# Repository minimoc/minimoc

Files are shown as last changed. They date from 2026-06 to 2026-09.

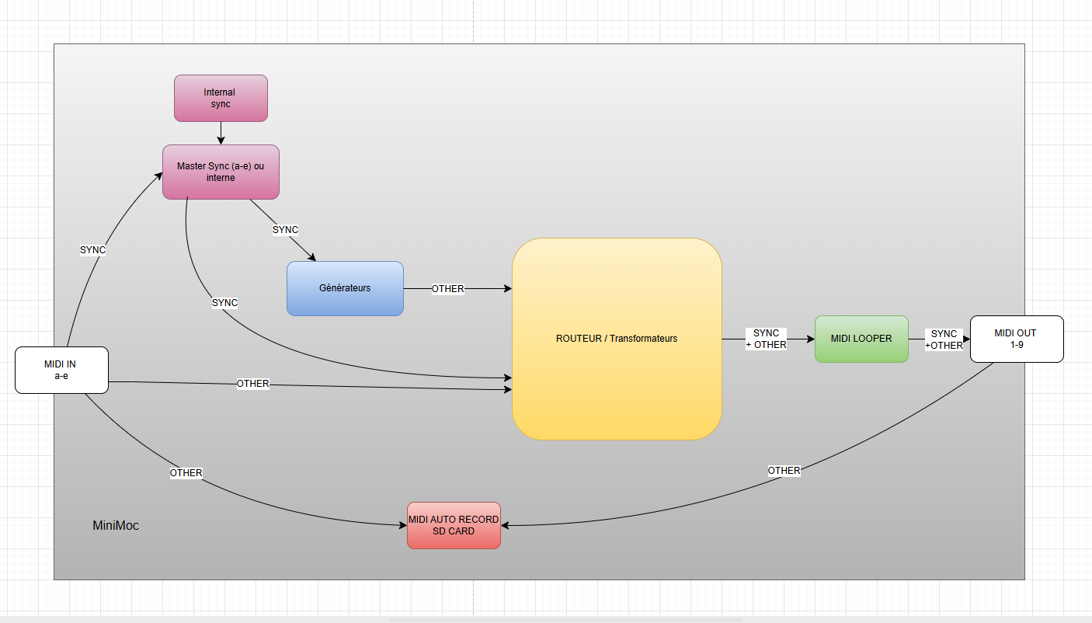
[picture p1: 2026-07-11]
docs/Conception.png

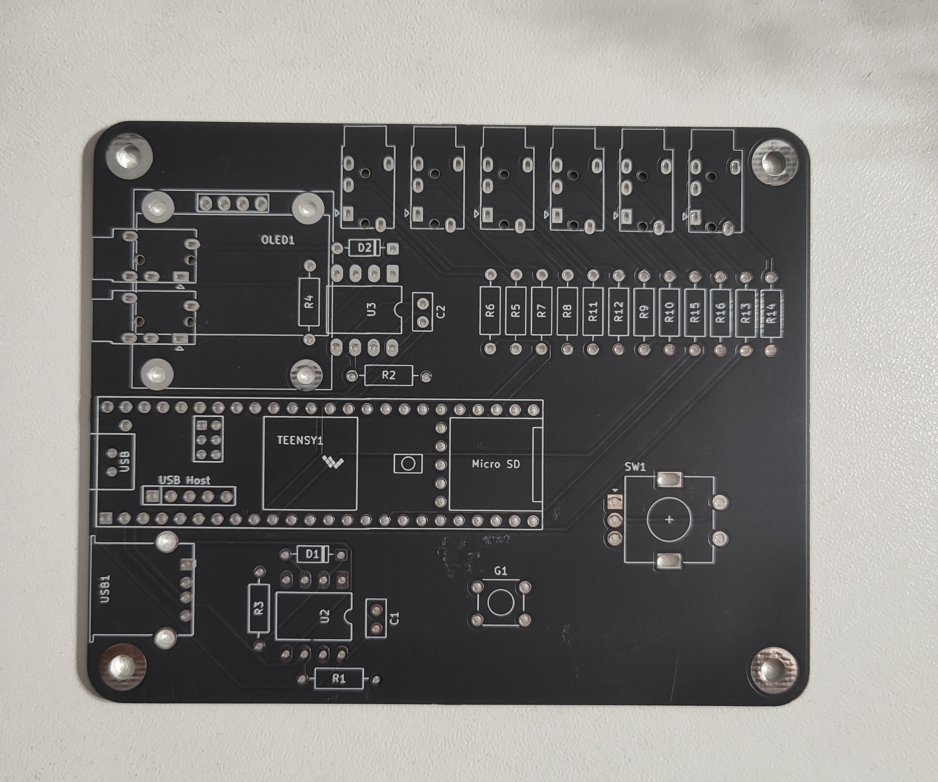
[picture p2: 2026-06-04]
hardware/dessous.jpg

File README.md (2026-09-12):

# miniMoc

**Routeur MIDI hybride DAWless, fait main.**

🇬🇧 In English — miniMoc is a handmade, open-hardware DAWless MIDI router built around a Teensy 4.1: 5 MIDI inputs, 9 outputs, TRS TYPE A + USB Host, a 128x64 OLED screen and a rotary encoder. Route MIDI between your synths and machines with no computer. Its signature feature, Smart Mirror: plug in a PC and the miniMoc's physical ports reappear as identical virtual ports in your DAW — no setup, no drivers. Unplug and you're back to standalone mode. The project is at v0.5.2 (routing, Smart Mirror, MIDI clock sync, Flux transforms — transpose/harmonize/chord progressions —, MIDI generators — LFO/Euclidean/drum patterns — and SD presets are solid; continuous MIDI auto-recording to SD is postponed to a future version). Documentation is currently in French — English translation contributions are very welcome (see CONTRIBUTING.md). Licence: source-available, non-commercial (PolyForm NC for firmware, CC BY-NC for hardware) — personal use is free, commercial use requires permission.

Le miniMoc est un boîtier portable qui route le MIDI entre vos synthés, séquenceurs
et machines — sans ordinateur. cinq entrées (2 TRS Type A + 3 USB), neuf sorties (6 TRS TYPE A + 3 USB), USB Host, un écran OLED 128x64 pixels
et un encodeur pour tout piloter à la main.

> **Smart Mirror** — branchez un PC/MAC/LINUX/SMARTPHONE et les ports physiques du miniMoc réapparaissent
> à l'identique en ports virtuels dans votre DAW. Aucune configuration, aucun pilote
> à installer. Vous débranchez, vous repartez en mode autonome.

---

## Démonstrations vidéo

- **Le projet et l'appel aux compagnons** : https://www.youtube.com/watch?v=sc03914Uq1w
- **Présentation du hardware** (ce que vous recevez, comment c'est fait) : https://youtu.be/FKErdNdDdWI
- **La navigation dans les menus** : https://youtu.be/ahOwxcXlfOY
- **Le smartmirror expliqué** : https://youtu.be/d6lrl4uF-Bw

---

## État du projet — v0.5.2

Le miniMoc en est à sa version 0.5.2, assemblée à la main.

**Ce qui fonctionne et est éprouvé :**
- Routage MIDI complet (mode BASIC par matrice, mode FLUX avancé avec filtrage et
  remapping de canal)
- Smart Mirror (miroir des ports physiques vers le DAW)
- Synchronisation MIDI Clock (horloge interne réglable ou source externe) + écran TRANSPORT
- Transformateurs de Flux : transposition, harmonisation, réharmonisation sur une
  progression d'accords
- Générateurs MIDI internes : LFO, séquenceur euclidien, motifs de batterie pré-enregistrés
- Sauvegarde / rappel des configurations sur carte SD (32 presets utilisateur + 8 d'usine)
- Interface écran OLED + encodeur
- Mise à jour du firmware par OTA depuis l'éditeur web

**Reporté après la V1 :**
- Auto-enregistrement MIDI continu sur carte SD (capture automatique des jams). Le moteur
  existe dans le code mais reste désactivé par défaut : pas de commande pour démarrer/
  arrêter un enregistrement à la volée, pas de fermeture propre du fichier en cours
  d'usage. Sera retravaillé pour une version ultérieure — vos retours d'usage sur ce
  point précis restent les bienvenus.

---

## Ce que c'est (et ce que ce n'est pas)

Le miniMoc est un projet dans un esprit maker. Ce n'est pas un
produit fini sous coque fermée : il se présente sous forme de carte (PCB) avec son
Teensy 4.1, et un *bezel* maintient l'écran en position. Des premiers fichiers 3D de
boîtier et de socle existent (dossiers [`boitier/`](boitier/) et [`socle/`](socle/))
mais restent perfectibles — c'est un terrain de contribution ouvert pour qui aime la CAO.

---

## Matériel

- **Microcontrôleur** : Teensy 4.1 (PJRC)
- **Affichage** : écran OLED monochrome (I²C)
- **Entrées / sorties** : 2+3 IN MIDI, 6+3 OUT MIDI
- **Contrôle** : encodeur rotatif + bouton

Les fichiers de conception (schémas, PCB, BOM) se trouvent dans le dossier
[`hardware/`](hardware/). Le *bezel* à imprimer est dans [`bezel/`](bezel/).

---

## Firmware

Le code du firmware est dans [`firmware/`](firmware/). Il se compile avec
**l'IDE Arduino + Teensyduino**, pour Teensy 4.1.

### Dépendances

Ces bibliothèques **ne sont pas incluses dans ce dépôt**. Installez-les via le
gestionnaire de bibliothèques de l'IDE Arduino (ou elles sont fournies avec
Teensyduino) :

- U8g2
- Arduino MIDI Library (version 5+)
- USBHost_t36 *(fournie avec Teensyduino)*
- MTP_Teensy
- SdFat
- Encoder *(fournie avec Teensyduino)*
- Bounce2

> ⚠️ N'essayez pas de récupérer ces bibliothèques depuis ce dépôt : elles n'y sont
> volontairement pas. Passez par le gestionnaire de bibliothèques Arduino.

Les licences de ces dépendances sont détaillées dans
[`THIRD_PARTY_LICENSES.md`](THIRD_PARTY_LICENSES.md).

---

## Licence

**Sources ouvertes — usage personnel libre, commercialisation sur accord.**

- **Firmware** (dossier `firmware/`) : licence **PolyForm Noncommercial 1.0.0**.
  Vous pouvez l'utiliser, l'étudier, le modifier et le partager **pour un usage
  non commercial**.
- **Matériel** (dossiers `hardware/` et `bezel/`) : licence
  **Creative Commons Attribution-NonCommercial 4.0 (CC BY-NC 4.0)**.

Toute **utilisation commerciale** (vente, intégration dans un produit vendu, etc.)
nécessite mon accord préalable. Si vous souhaitez commercialiser quelque chose à
partir du miniMoc, contactez-moi : c'est tout à fait possible de s'entendre.

Voir les fichiers [`LICENSE`](LICENSE) (firmware) et
[`hardware/LICENSE`](hardware/LICENSE) (matériel).

---

## Contribuer

Le miniMoc avance avec celles et ceux qui l'utilisent. Retours d'usage,
corrections, idées de fonctionnalités, conception d'un boîtier complet : tout est
bienvenu. Voir [`CONTRIBUTING.md`](CONTRIBUTING.md).

---

*miniMoc — conçu et assemblé à la main par François Jacob.*

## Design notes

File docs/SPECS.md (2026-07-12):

# miniMoc — Spécifications Fonctionnelles

## 1. Vue d'ensemble

Le **miniMoc** est un routeur MIDI hardware intelligent combinant :
- Un firmware embarqué (C++/Arduino) sur **Teensy 4.1**
- Une interface homme-machine sur **OLED 128×64 (SSD1306 I2C)**
- Un **encodeur rotatif** (navigation + sélection) et un bouton BACK

---

## 2. Ports MIDI

### Entrées (5 ports)
| Port | Type | Description |
|---|---|---|
| A | DIN MIDI (Serial2) | Entrée physique TRS TYPE A |
| B | DIN MIDI (Serial1) | Entrée physique TRS TYPE A |
| C | USB Host | 1er device USB branché |
| D | USB Host | 2e device USB branché |
| E | USB Host | 3e device USB branché |

### Sorties (9 ports)
| Port | Type | Description |
|---|---|---|
| 1–6 | DIN MIDI (Serial3/6/7/8) | Sorties physiques TRS |
| 7–9 | USB Host | Sorties vers devices USB |

### USB Device (vers DAW)
- Port 0 : SysEx/éditeur
- Ports 1–2 : miroir brut des entrées A/B
- Ports 3–12 : miroir routé des sorties 1–9 + miroir brut des entrées C/D/E
- **Smart Mirror** : tout signal routé est simultanément mirroré vers le DAW pour enregistrement

### USB Host (6 slots physiques)
- 6 objets `MIDIDevice_BigBuffer` (MIDIUSB1–6), assignation FIFO
- 3 instances `USBHub` pour robustesse hub multi-TT / reconnexion
- Pool : 12 pipes + 48 transfers extra

---

## 3. Routage MIDI — Architecture Hybride

Le routage combine deux couches cumulatives calculées dans `route_matrix[5][16][9]` :

### 3.1 Couche BASIC (matrice 5×9)
- Grille booléenne Port d'entrée → Port de sortie
- Quand un nœud est actif : **passthrough canal** (ch1→ch1, ch2→ch2, etc.)
- Stockée dans `basic_matrix[5]` (bitmask uint16_t par port d'entrée)
- Navigation : encodeur (1 case/tick), VALID = toggle

### 3.2 Couche FLUX (règles avancées cumulatives)
Chaque **flux** définit :
- **Entrées** : liste de (port, canal_mask) — ex. {A, ch1} + {B, ch2}
- **Sorties** : liste de (port, canal_mask) — ex. {sortie1, ch5} + {sortie4, ch2}
- Si canal_mask = 0 → tous les canaux (entrée) ou passthrough (sortie)
- Multi-sélection indépendante pour entrées ET sorties
- MAX 16 flux simultanés

**Cumul** : route_matrix = BASIC + tous FLUX actifs. Les bits sont OR-és : un signal peut arriver sur plusieurs destinations via BASIC et FLUX simultanément.

### 3.3 Filtrage canal 10
Supprimé — le canal 10 est traité comme n'importe quel autre canal.

---

## 4. Synchronisation MIDI (SYNC)

Sélection d'une **unique source maître** (`sync_master`, `uint8_t`) pour Clock/Start/Stop/Continue/SystemReset, diffusée via `_sync_forward()` (`_midi.h`) vers **toutes les sorties** (1–6 physiques, 7–9 USB Host) et leur miroir PC (smartmirror, `SYNC_MIRROR_CABLES[]`).

### 4.1 Encodage `sync_master`

Chaque lettre A-E a deux sources physiques distinctes qui déclenchaient toutes les deux le même maître avant cette distinction : l'entrée TRS/USB Host physique d'un côté, le câble USB miroir venant du PC (smartmirror) de l'autre. `SYNC_LABELS[]` (`logic.h`) :

| Valeur | Source | Valeur | Source |
|---|---|---|---|
| 0 | A (TRS) | 5 | A (USB/PC) |
| 1 | B (TRS) | 6 | B (USB/PC) |
| 2 | C (USB Host) | 7 | C (USB/PC) |
| 3 | D (USB Host) | 8 | D (USB/PC) |
| 4 | E (USB Host) | 9 | E (USB/PC) |
| 10 | MINIMOC (horloge interne) | 0xFF (RAM) / 0x7F (EEPROM, SysEx) | OFF |

- Persisté en EEPROM (adresse 34, 1 octet, valeurs 0-10 ou 0x7F=OFF)
- Les USB Host inputs (C/D/E) supportent la réception d'horloge via callbacks `setHandleRealTimeSystem` (`_usb_rt()`, valeurs 2-4 uniquement — inchangé par la distinction TRS/USB ci-dessus)
- Rétrocompatibilité : les valeurs 0-4 et 0xFF gardent exactement le sens qu'elles avaient avant l'introduction des variantes USB/PC (5-9) et MINIMOC (10)

### 4.2 Horloge interne (MINIMOC)

Quand `sync_master == SYNC_MASTER_INTERNAL` (10), le miniMoc génère lui-même le Clock via `internal_clock_isr()` (`_midi.h`), déclenché par un `IntervalTimer` matériel — indépendant de `loop()` et de ses appels bloquants (`u8g2.sendBuffer()` ~8ms, `sd_tick()`/`MTP.loop()`, `myusb.Task()`).

- **Sorties DIN (MIDI1-6)** : envoyées directement depuis l'ISR. Sûr par construction : si le buffer TX UART est plein, l'IRQ UART (priorité 64) préempte l'`IntervalTimer` (priorité par défaut 128, donc moins prioritaire) pour le drainer — mécanisme prévu par le core Teensy pour ce cas précis (`HardwareSerial.cpp::write9bit()`).
- **Sorties USB Host (7-9) et miroir PC** : jamais appelées depuis l'ISR — `MIDIDevice_BigBuffer::sendRealTime()` (USBHost_t36) et `usbMIDI` ne sont pas garantis réentrants (`write_packed()` peut boucler un temps non borné en cas de buffers pleins). L'ISR pose un flag (`internal_clock_usb_pending`), vidé en best-effort par `internal_clock_flush_usb()` appelée sans condition dans `loop()`.
- Tempo : `internal_clock_bpm` (`uint16_t`, 20-300, défaut 100), persisté en EEPROM (37-38). `internal_clock_apply()` démarre/arrête/reconfigure le timer (`period_us = 60000000UL / (24UL * internal_clock_bpm)`) — appelée après toute affectation de `sync_master` ou de `internal_clock_bpm`.
- Pas de Start/Stop/Continue automatique généré par le Clock lui-même — géré séparément par le menu TRANSPORT (4.3).

### 4.3 Transport (Play/Pause/Stop/MMC)

`transport_submenu.h` expose des actions réutilisées à la fois par les gestes physiques (encodeur + BACK) et par la commande SysEx `0x11` (weblink) :

| Fonction | Effet |
|---|---|
| `transport_do_play_pause()` | Bascule Play/Pause. Play : `Start` (premier départ) ou `Continue` (reprise après pause) selon `transport_resumable`. Pause : `Stop` temps réel, `transport_resumable=true` |
| `transport_do_stop()` | `Stop` temps réel + MMC Stop, `transport_resumable=false` (le Play suivant redémarre avec `Start`, pas `Continue`) |
| `transport_do_record()` | MMC Record Strobe |
| `transport_do_fastforward()` | MMC Fast Forward |
| `transport_do_rewind()` | MMC Rewind |

État partagé : `transport_playing` (bool), `transport_resumable` (bool) — lus par `transport_draw()` pour l'affichage PLAY/PAUSE/STOP.

**MMC (MIDI Machine Control)** : SysEx `F0 7F 7F 06 <commande> F7` (device-id 0x7F = broadcast), diffusé vers les mêmes 9 sorties + miroir PC via `send_mmc()` (`_midi.h`). Commandes utilisées : Stop 0x01, Fast Forward 0x04, Rewind 0x05, Record Strobe 0x06. Protocole indépendant du Start/Continue/Stop temps réel (`_sync_forward()`).

**Gestes physiques** (écran TRANSPORT) :
- Encodeur (BACK relâché) : ±1 BPM, ±5 si deux crans s'enchaînent en moins de `TRANSPORT_BPM_ACCEL_MS` (180ms)
- Clic encodeur (BACK relâché) : `transport_do_play_pause()`
- Clic simple BACK : `transport_do_stop()` si en pause (reste sur l'écran), sinon retour au menu précédent
- BACK tenu + clic encodeur / tourner à droite / tourner à gauche : `transport_do_record()` / `transport_do_fastforward()` / `transport_do_rewind()`
- Le long-appui global BACK→écran logo (`firmware.ino::loop()`) est désactivé tant que `ui_screen == UI_TRANSPORT`, pour ne pas interrompre les gestes chordés ci-dessus
- `btn_back` distingue un **front** (`backButton.fell()`, un seul événement par appui — utilisé par tous les autres écrans pour "remonter d'un niveau") d'un **niveau continu** (`btn_back_held`, utilisé uniquement par TRANSPORT pour les gestes chordés)

### 4.4 Protocole SysEx éditeur (PCEditor.h)

Toutes les commandes `F0 7D <cmd> ... F7` (`MANUFACTURER_ID = 0x7D`) :

| Cmd | Sens | Description |
|-----|---|---|
| 0x01 | PC→device | Update routing direct (legacy) |
| 0x02 | PC→device | Request full dump (`sendFullDumpToPC()`) |
| 0x03 | device→PC | Version firmware (ASCII, ex. "v0.3.0") — envoyée en tête du dump complet et à chaque QUICK POLL |
| 0x04 | bidirectionnel | BPM horloge interne (14 bits, 2×7bit) |
| 0x05 / 0x06 | PC→device | Charger / sauver preset N |
| 0x07 | device→PC | Preset actif |
| 0x08 | bidirectionnel | Ping / Pong (heartbeat) |
| 0x09 | bidirectionnel | Cellule matrice BASIC |
| 0x0A / 0x0B | bidirectionnel | Flux (données / count) |
| 0x0C | bidirectionnel | SYNC master |
| 0x0D | bidirectionnel | HOST CONFIG |
| 0x0E | PC→device | Quick poll (déclenche l'envoi groupé de 0x03/0x07/0x0C/0x04/0x09/0x0B/0x0A/0x0D/0x0F) |
| 0x0F | device→PC | Nom device USB (par slot) |
| 0x10 | PC→device | Reboot HalfKay bootloader |
| 0x11 | PC→device | Action transport — 0=Play/Pause 1=Stop 2=Record 3=Fast Forward 4=Rewind (voir 4.3) |

---

## 5. USB Host — Configuration (HOST CONFIG)

### 5.1 Assignation port logique ↔ slot physique
Table `port_slot[6]` : pour chaque port logique (IN C/D/E + OUT 7/8/9), quel slot physique (MIDIUSB1-6) le gère.

Défaut : slot 0 → C+7, slot 1 → D+8, slot 2 → E+9.

### 5.2 Mode AUTO
- Assignation chronologique FIFO (premier device branché = premier slot)
- Pas de persistance des assignations
- Toute reconnexion repart dans l'ordre d'arrivée

### 5.3 Mode MANUEL
- L'utilisateur assigne manuellement chaque port logique à un slot physique
- Capture des empreintes **VID:PID** de chaque port au moment de l'activation
- À la reconnexion : scan par VID:PID → le device retrouve son port logique quel que soit l'ordre de branchement
- Persisté en EEPROM (adresse 2, format v3)

---

## 6. Presets

- Stockage sur **carte SD** (SDIO), répertoire `/PRESETS/PRSTnn.DAT`
- Maximum **32 presets**
- Format v3 : `route_matrix` + `basic_matrix` + flux_list (FLUX)
- Migration automatique des presets v1 (legacy route_matrix → basic_matrix déduite)
- Sauvegarde/chargement via menu PRESET
- Preset actif mémorisé en EEPROM (adresse 0)

---

## 7. Interface Homme-Machine

### 7.1 Contrôles physiques
- **Encodeur rotatif** : navigation dans les listes/grilles
- **Bouton VALID** (encodeur click) : sélectionner, valider, entrer dans un menu
- **Bouton BACK** (bouton séparé) : retour arrière dans la navigation
- **Appui long BACK** (1s) : basculer vers/depuis l'écran logo (mode live)
- **Depuis le logo** : tout clic ou rotation → retour au carousel

### 7.2 Carousel principal (6 items)
```
PRESET → SYNC → ROUTAGE → MONITOR → SYSTEM → TRANSPORT
```
Ordre d'enregistrement : `firmware.ino::setup()` (`carousel_register()`).

### 7.3 Menu PRESET
- Affichage du numéro de preset courant (indicateur SD si sauvegardé)
- Actions : changer de numéro / Sauvegarder / Charger

### 7.4 Menu SYNC
- Liste défilante (`sync_submenu.h`) : 11 sources + OFF (voir §4.1), curseur en encart inversé, flèches `^`/`v` quand du contenu est masqué
- La source active est marquée d'un `*`, indépendamment de la position du curseur
- VALID = sélectionner + sauvegarder EEPROM + `internal_clock_apply()` (démarre/arrête l'horloge interne selon le nouveau choix)

### 7.5 Menu ROUTAGE
```
ROUTAGE
├── MATRICE  → grille 5×9 interactive (BASIC)
└── FLUX     → liste des flux avancés
     ├── [F1 - A:1 → 1:5]  (clic = Modifier / Supprimer)
     ├── [F2 - B → 1 4]
     └── [+] Nouveau flux
           Step 1 : FLUX → ENTREES (ports A-E, long press = canaux)
           Step 2 : FLUX → SORTIES (ports 1-9, long press = canaux)
           Picker canaux : grille 4×4 (ch1-16), sélection multi indépendante
```

### 7.6 Menu MONITOR
- VU-mètre temps réel : 5 entrées (A/B/C/D/E) + 9 sorties (1-9)
- Actualisation permanente (animation fondu 500ms)
- Les barres d'entrée s'allument dès réception, indépendamment du routage
- Page 2 (BPM) : tempo du maître SYNC en grand ; fréquence de rafraîchissement pilotée par le réglage **BPM REFRESH** (§7.7) ; un clic sur l'encodeur force toujours une actualisation immédiate quel que soit ce réglage ; la LED embarquée (`LED_BUILTIN`) clignote à chaque temps (`bpm_push_clock()`, toutes les 24 ticks), indépendamment de l'affichage

### 7.7 Menu SYSTEM
```
SYSTEM
├── INFO         → stats SD + liste devices USB physiques (D1..D6)
├── HOST CONFIG  → assignation ports logiques / Mode AUTO-MANUEL / LOCK VID:PID
├── USB LINK     → polling USB 2,5s pour forcer l'énumération (sans reboot)
├── USB RESET    → reboot Cortex-M7 complet (équivalent power-cycle)
├── CONTRASTE    → luminosité OLED (16–255)
└── BPM REFRESH  → fréquence d'actualisation de la page BPM du MONITOR
                   (250/500/1000/2000/5000ms ou MANUEL — cf. BPM_REFRESH_OPTIONS, logic.h)
```
Liste défilante (même pattern que SYNC), 6 items.

### 7.8 Menu TRANSPORT
Écran minimal : BPM en grand (`u8g2_font_logisoso42_tn`) + indicateur PLAY/PAUSE/STOP en dessous (`transport_submenu.h`). Pilote le tempo et le transport de l'horloge interne MINIMOC (§4.2, §4.3) — voir §4.3 pour le détail des gestes. `UI_TRANSPORT` est ajouté à `need_anim` dans `controls.h::ui_tick()` : l'écran tourne en continu (pas seulement sur activité détectée), nécessaire pour observer de façon fiable le front de relâchement de BACK.

---

## 8. Performances et stabilité

- **Latence MIDI** : presque nulle — `sendBuffer()` OLED suspendu si pas d'input utilisateur
- **USB Host** : `myusb.Task()` appelé 2× par itération de loop pour réduire le gap pendant SD/MTP
- **Démarrage** : logo affiché, preset et config restaurés depuis SD/EEPROM ; USB LINK disponible si devices non reconnus
- **Récupération** : USB RESET depuis SYSTEM → reboot propre, re-énumération complète

---

## 9. Stockage EEPROM (Teensy 4.1 — 1080 octets)

| Adresse | Contenu |
|---|---|
| 0 | Preset actif (index 1-indexed) |
| 1 | Compteur de session SD |
| 2–33 | Config USB Host (magic + mode + port_slot + VID:PID) |
| 34 | Maître SYNC (0-10, cf. `SYNC_LABELS` §4.1 ; 0x7F=OFF) |
| 35 | Contraste OLED (`screen_contrast`, 1 octet) |
| 36 | Intervalle de rafraîchissement BPM REFRESH (index dans `BPM_REFRESH_OPTIONS`, 1 octet) |
| 37–38 | BPM de l'horloge interne MINIMOC (`internal_clock_bpm`, `uint16_t`) |

---

## 10. Stockage SD

| Chemin | Contenu |
|---|---|
| `/PRESETS/PRSTnn.DAT` | Presets MIDI (format v3) |
| `/REC/RECnnn.DAT` | Enregistrements MIDI (ring buffer) |

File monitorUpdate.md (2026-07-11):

# Mémo — Réduction jitter menu Monitor

## Problème

Le menu Monitor (VU-mètre + BPM) introduisait du jitter et de l'instabilité dans le traitement MIDI.

**Cause racine :** l'appel `u8g2.sendBuffer()` (transfert I2C vers l'écran OLED) bloque le Teensy environ **20 ms** à chaque exécution. Avec un rafraîchissement toutes les 50 ms, le processeur était occupé par l'affichage **40 % du temps**, empêchant la lecture des messages MIDI USB en temps voulu.

---

## Modifications apportées

### 1. Throttle du rafraîchissement : 50 ms → 300 ms
**Fichier :** `firmware/monitor_submenu.h` — fonction `mon_handle_input()`

Un timestamp `mon_last_draw_ms` conditionne l'appel aux fonctions de rendu (`mon_draw()` / `mon_draw_bpm()`) : elles ne sont exécutées que si 300 ms se sont écoulées depuis le dernier dessin. Un changement de page via l'encodeur force un redraw immédiat (l'affichage répond instantanément à la navigation).

### 2. Vitesse I2C : 400 kHz → 1 MHz
**Fichier :** `firmware/firmware.ino` — fonction `setup()`

`Wire.setClock(400000)` remplacé par `Wire.setClock(1000000)`.
Le Teensy 4.1 supporte le mode Fast-mode Plus (1 MHz). À cette vitesse, chaque `sendBuffer()` passe de ~20 ms à ~8 ms.

---

## Effet combiné

| Situation | Durée sendBuffer | Fréquence | Temps bloqué / seconde |
|---|---|---|---|
| Avant | ~20 ms | toutes les 50 ms | ~400 ms/s |
| Après | ~8 ms | toutes les 300 ms | ~27 ms/s |

Réduction d'environ **15× du temps de blocage I2C** pendant l'affichage Monitor.

---

## Vérifications après flashage

### 1. Stabilité de l'écran OLED
- Naviguer dans le menu Monitor : l'affichage doit être propre, sans artefacts, lignes parasites ou freeze.
- Rester sur la page VU-mètre quelques secondes, puis passer à la page BPM.
- Si l'écran est instable → voir **Rollback** ci-dessous.

### 2. Rafraîchissement VU-mètre et BPM
- Le VU-mètre doit se mettre à jour environ 3 fois par seconde (toutes les ~300 ms). L'animation est moins fluide qu'avant mais reste lisible.
- Le BPM doit afficher la valeur correcte et se rafraîchir au même rythme.
- Changer de page avec l'encodeur : le nouveau contenu doit apparaître immédiatement (sans attendre les 300 ms).

### 3. Réduction du jitter MIDI
- Brancher un séquenceur ou une boîte à rythme envoyant du MIDI Clock.
- Comparer le jitter horloge mesuré dans le DAW (ou avec un outil de monitoring MIDI) avant/après.
- En mode Monitor actif, le jitter doit être significativement plus faible qu'avant.

### 4. Fonctionnement normal hors Monitor
- Vérifier que les autres menus (Preset, Sync, Routage, System) ne sont pas affectés.
- Le carousel doit défiler normalement.

---

## Rollback si l'OLED est instable à 1 MHz

Dans `firmware/firmware.ino`, ligne `Wire.setClock(...)` :

| Valeur | Mode | À essayer si… |
|---|---|---|
| `1000000` | Fast-mode Plus | **valeur actuelle** |
| `800000` | intermédiaire | artefacts légers |
| `400000` | Fast (valeur d'origine) | freeze ou corruption d'image |

Le throttle 300 ms reste bénéfique quelle que soit la vitesse I2C choisie.

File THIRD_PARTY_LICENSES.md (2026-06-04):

# Licences des bibliothèques tierces

Le firmware miniMoc utilise les bibliothèques externes listées ci-dessous.
Elles ne sont **pas** incluses dans ce dépôt : elles doivent être installées
séparément via le gestionnaire de bibliothèques de l'IDE Arduino / Teensyduino
(voir la section « Dépendances » du README).

Chaque bibliothèque reste soumise à sa propre licence. Les mentions de copyright
ci-dessous sont conservées conformément aux termes des licences MIT et BSD.

| Bibliothèque | Auteur | Licence | Lien |
|---|---|---|---|
| U8g2 | oliver (olikraus) | BSD 2-Clause | https://github.com/olikraus/u8g2 |
| Arduino MIDI Library (v5) | Francois Best | MIT | https://github.com/FortySevenEffects/arduino_midi_library |
| USBHost_t36 | Paul Stoffregen / PJRC | MIT | https://github.com/PaulStoffregen/USBHost_t36 |
| MTP_Teensy | PJRC / contributors | MIT | https://github.com/KurtE/MTP_Teensy |
| SdFat | Bill Greiman | MIT | https://github.com/greiman/SdFat |
| Encoder | Paul Stoffregen / PJRC | MIT | https://github.com/PaulStoffregen/Encoder |
| Bounce2 | Thomas Ouellet Fredericks | MIT | https://github.com/thomasfredericks/Bounce2 |
| Core Teensy (Wire, EEPROM, FS, usb_names) | PJRC | MIT (+ clause PJRC) | https://github.com/PaulStoffregen/cores |

## Notes importantes

- **U8g2 — fonts.** Le firmware n'utilise que des fonts du domaine public
  (`5x7_tf`, `6x10_tf`, `7x13_tf`, `8x13_tf`). La bibliothèque U8g2 contient par
  ailleurs un font sous GPLv2 (`u8g2_font_siji_t_6x10`) qui n'est **pas** utilisé
  par ce projet et n'entre donc pas dans le binaire compilé. Pour que cela reste
  vrai, U8g2 ne doit jamais être copié dans ce dépôt : il est référencé comme
  dépendance externe uniquement.

- **Fichiers d'exemple.** Certaines bibliothèques (MIDI, USBHost_t36) contiennent
  des sketches d'exemple sous licence GPL/LGPL. Ces fichiers ne sont jamais
  compilés dans le firmware miniMoc et n'ont aucun impact sur sa licence. C'est
  une raison de plus de ne pas embarquer ces bibliothèques dans le dépôt.

- **Clause PJRC (core Teensy).** Les fichiers du core Teensy portent une clause
  additionnelle PJRC qui concerne l'intégration dans un IDE / toolchain listant
  des cibles matérielles. Elle ne s'applique pas à un firmware utilisateur.

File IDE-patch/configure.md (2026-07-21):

Installation de l'env. IDE Arduino:

1 - télécharger et installer la dernière version https://www.arduino.cc/en/software/
2 - installer TeensyDduino: https://www.pjrc.com/teensy/td_download.html
3 - copier le fichier boards.txt modifié + usb_desc.h modifié
4 - supprimer C:\Users\XXXXXXXX\AppData\Roaming\arduino-ide
5 - Selectionner Teensy 4.1 MINOMOC comme boards
6 - Selectionner Tools/USB TYPE : Serial + MIDI16 + MTP
7 - librairies:
Installer les bibliothèques manquantes

Via Tools > Manage Libraries... (gestionnaire de bibliothèques), installe celles qui ne sont pas fournies par Teensyduino :

- U8g2 (écran OLED)

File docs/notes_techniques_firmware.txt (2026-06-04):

================================================================================
  miniMoc v0.2 — Notes techniques firmware
  Teensy 4.1 @ 600 MHz
  Date : 28 mai 2026
================================================================================

━━━━━━━━━━━━━━━━━━━━━━━━━━━━━━━━━━━━━━━━━━━━━━━━━━━━━━━━━━━━━━━━━━━━━━━━━━━━━━
1. GESTION MIDI ET ROUTAGE DES MESSAGES
━━━━━━━━━━━━━━━━━━━━━━━━━━━━━━━━━━━━━━━━━━━━━━━━━━━━━━━━━━━━━━━━━━━━━━━━━━━━━━

─── 1.1  Ports physiques TRS (UART hardware) ────────────────────────────────

Le Teensy 4.1 dispose de nombreux UARTs indépendants. Chaque port MIDI TRS
est câblé sur un Serial dédié, géré en interruption hardware. Les buffers ont
été agrandis à 1 024 octets (au lieu de 64 par défaut) pour absorber ~330 ms
de MIDI dense sans perte lors des opérations longues (SD write, OLED).

  Port   UART      Objet MIDI        Rôle
  ─────────────────────────────────────────────────────────────────────
  IN A   Serial2   MIDIA             Entrée TRS A
  IN B   Serial1   MIDIB             Entrée TRS B
  OUT 1  Serial8   MIDI1             Sortie physique 1
  OUT 2  Serial3   MIDI2             Sortie physique 2
  OUT 3  Serial7   MIDI3             Sortie physique 3
  OUT 4  Serial6   MIDI4             Sortie physique 4
  OUT 5  Serial2   MIDI5 = MIDIA_5   Sortie 5 (même UART que IN A)
  OUT 6  Serial1   MIDI6 = MIDIB_6   Sortie 6 (même UART que IN B)

  NOTE : MIDI5 et MIDI6 partagent l'UART avec les entrées A et B.
  Cela ne pose AUCUN problème de routage A→5 ou B→6 (voir § 1.5).

─── 1.2  Ports USB Host (C, D, E / sorties 7, 8, 9) ────────────────────────

Six objets MIDIDevice_BigBuffer (MIDIUSB1…MIDIUSB6) sont déclarés sur le bus
USB Host. Ils sont assignés dynamiquement aux ports logiques C/D/E (entrées)
et 7/8/9 (sorties) via le tableau port_slot[6]. Cette indirection permet de
reconfigurer quel device physique répond à quel port logique sans recompiler.

  port_slot[0..2] = slot physique pour les ENTREES C, D, E
  port_slot[3..5] = slot physique pour les SORTIES 7, 8, 9

Les devices USB se connectent dans l'ordre FIFO : le premier device branché
prend MIDIUSB1 (slot 0), le deuxième MIDIUSB2 (slot 1), etc. Le menu HOST
CONFIG permet de réassigner logiquement ces slots sans hot-plug.

─── 1.3  Matrice de routage route_matrix[5][16][9] ─────────────────────────

C'est le cœur de toute la logique de routage. Déclaration :

  uint16_t route_matrix[5][16][9]
    [input  0-4 ] : A, B, C (USB Host), D (USB Host), E (USB Host)
    [canal  0-15] : canaux MIDI 1-16
    [sortie 0-8 ] : OUT 1-6 (TRS physiques) + OUT 7/8/9 (USB Host)
    valeur        : bitmask uint16_t — bit i actif = canal (i+1) sur cette sortie

Cette matrice est PRÉCALCULÉE au chargement du preset par la fonction
recompute_route_matrix(). Elle n'est jamais modifiée pendant le routage en
temps réel, ce qui rend la lecture atomique et très rapide.

Elle combine deux couches :
  - BASIC  : mapping simple entrée→sortie, passthrough de canal
  - FLUX   : règles canal→canal avancées (many-to-many, remapping de canal)

Dans chaque handler (handleNoteOn, handleControlChange…), une double boucle
parcourt les 9 sorties et, pour chaque sortie, itère sur les bits actifs du
bitmask via __builtin_ctz (instruction CPU native, ~1 cycle). Complexité
O(sorties × canaux actifs), typiquement < 5 µs par message routé.

─── 1.4  Smart Mirror — mirroring vers le DAW (PC) ─────────────────────────

La conception est symétrique : chaque port possède un câble USB numéroté
identiquement pour les deux sens (Teensy→PC et PC→Teensy). Le mirroring
s'effectue à trois niveaux :

  NIVEAU 1 — Entrées brutes vers DAW
    Dans loop(), MIDIA.read() et MIDIB.read() envoient immédiatement le
    message reçu sur le câble USB correspondant (USB_PORT_A=1, USB_PORT_B=2)
    AVANT tout routage. Le DAW reçoit donc une copie exacte de l'entrée.

  NIVEAU 2 — Sorties routées vers DAW
    Dans les macros SEND_NOTE_ON/OFF etc., chaque envoi vers une sortie
    physique est SIMULTANÉMENT mirrored vers le câble USB correspondant
    (USB_OUT_1…USB_OUT_9). Guard : if(src!=SRC_PC) pour éviter la double
    boucle lorsque le message vient déjà du DAW.

  NIVEAU 3 — USB Host vers DAW
    Les callbacks _usb_note_on() envoient d'abord le miroir vers le DAW
    (usbMIDI.sendNoteOn sur HC_IN_CABLE[p]) puis déclenchent le routage
    via handleNoteOn(). Le DAW voit donc les entrées USB Host sur ses
    propres câbles (C=3, D=4, E=5).

  Tableau des câbles USB :
    USB_PORT_A  = 1    IN A   <-> DAW  (miroir + inject)
    USB_PORT_B  = 2    IN B   <-> DAW
    USB_IN_C    = 3    USB Host IN C <-> DAW
    USB_IN_D    = 4    USB Host IN D <-> DAW
    USB_IN_E    = 5    USB Host IN E <-> DAW
    USB_OUT_1   = 6    Sortie physique 1 (miroir vers DAW)
    USB_OUT_2   = 7    Sortie physique 2
    USB_OUT_3   = 8    Sortie physique 3
    USB_OUT_4   = 9    Sortie physique 4
    USB_OUT_5   = 10   Sortie physique 5
    USB_OUT_6   = 11   Sortie physique 6
    USB_OUT_7   = 12   USB Host OUT 7 (miroir vers DAW)
    USB_OUT_8   = 13   USB Host OUT 8
    USB_OUT_9   = 14   USB Host OUT 9
    Câble 0     = 0    Éditeur SysEx (commandes de configuration)

─── 1.5  Clarification : MIDI5/MIDI6 et routage A→5 ou B→6 ─────────────────

MIDI5 = MIDIA = MIDIA_5 = Serial2  (même objet C++)
MIDI6 = MIDIB = MIDIB_6 = Serial1  (même objet C++)

La question : router A→5 (ou B→6) pose-t-il un problème puisqu'ils partagent
le même UART ?

RÉPONSE : NON, aucun problème.

Un UART est FULL-DUPLEX par nature hardware :
  - La pin RX reçoit les données de l'entrée A (via optoisolateur)
  - La pin TX émet les données vers la sortie 5
  - Ces deux pins et leurs buffers sont électriquement et logiciellement
    indépendants dans le silicium

Quand handleNoteOn route A→5, il appelle :
  - MIDIA_5.read()       → lit le buffer RX de Serial2 (ce qui arrive)
  - MIDI5.sendNoteOn()   → écrit dans le buffer TX de Serial2 (ce qui part)
  Ces deux opérations n'interfèrent pas.

Le seul effet réel de ce partage est une contrainte matérielle : le Teensy
n'ayant pas d'UART supplémentaire, OUT 5 et OUT 6 ne peuvent pas être des
entrées indépendantes — ils sont fixés comme sorties. Ce n'est pas une
limitation de routage mais une limitation de ressources hardware.

━━━━━━━━━━━━━━━━━━━━━━━━━━━━━━━━━━━━━━━━━━━━━━━━━━━━━━━━━━━━━━━━━━━━━━━━━━━━━━
2. LOGIQUE ET TIMING DE LA BOUCLE PRINCIPALE
━━━━━━━━━━━━━━━━━━━━━━━━━━━━━━━━━━━━━━━━━━━━━━━━━━━━━━━━━━━━━━━━━━━━━━━━━━━━━━

La loop() est un polling pur, sans RTOS, sans delay(). Elle s'exécute aussi
vite que possible sur le Teensy 4.1 @ 600 MHz.

─── 2.1  Déroulement séquentiel avec estimations de durée ───────────────────

  Étape                         Durée estimée
  ────────────────────────────────────────────────────────────────────────
  ota_tick()                    ~1-5 µs (idle) / bloquant pendant OTA
  Gestion logo / BACK           ~0.5 µs
  ui_tick() max 1×/50 ms        ~20 ms si sendBuffer OLED / ~1 µs si skip
  MIDIA.read()                  ~0.5-2 µs (+2-5 µs si message : callback)
  MIDIB.read()                  ~0.5-2 µs
  myusb.Task() 1er appel        ~5-50 µs  (transferts USB Host → buffers)
  MIDIUSBx.read() × 6           ~1-3 µs × 6
  hc_poll()                     ~1 µs    (détection hot-plug USB Host)
  myusb.Task() 2ème appel       ~5-50 µs  (évite gap > bInterval hub ~8 ms)
  MIDIUSBx.read() × 6           ~1-3 µs × 6
  sd_tick()                     ~0.5 µs idle / 1-3 ms si write / pic 5-10 ms
  MTP.loop()                    ~1-10 ms variable si accès PC
  while usbMIDI.read()          ~1-5 µs par message PC → inject sorties
  ────────────────────────────────────────────────────────────────────────

  Durée typique sans MIDI actif : ~100–300 µs / itération
  Fréquence nominale de boucle  : ~3 000–10 000 itérations/seconde
  Avec MIDI dense + SD write    : peut monter à ~3–15 ms / itération

Raison du double appel myusb.Task() : le hub USB a un bInterval de ~8 ms.
Si le gap entre deux Task() dépasse cette valeur, le hub manque ses interrupts
de port. sd_tick() pouvant durer 1-3 ms, le second appel avant sd_tick()
garantit que le hub est servi dans les temps.

─── 2.2  Interruptions ───────────────────────────────────────────────────────

Il n'y a AUCUNE interruption applicative explicite dans le code (pas de
attachInterrupt(), pas d'ISR manuelle). Cependant, plusieurs mécanismes
tournent en interruption sous le capot de Teensyduino :

  UART RX (Serial1–8)
    Les octets MIDI arrivants sont reçus en ISR hardware et placés dans les
    buffers de 1 024 octets (agrandis via addMemoryForRead). Le MIDI.read()
    dépile ce buffer en tâche de fond. Capacité : ~330 ms de MIDI dense.

  USB Device (usbMIDI)
    Géré par les interruptions USB internes du Teensy. Transparent.

  USB Host (myusb.Task())
    N'EST PAS une interruption — c'est un polling coopératif. C'est pourquoi
    il est appelé deux fois par boucle (voir § 2.1).

  Encodeur rotatif (Encoder library)
    Utilise des interruptions GPIO sur les pins 39/40 pour ne rater aucun
    cran, quelle que soit la durée de la boucle principale.

  Bouton SELECT (Bounce2 library)
    Polling dans ui_tick(), avec debounce logiciel de 150 ms.

─── 2.3  Latence MIDI effective ─────────────────────────────────────────────

Sur le chemin critique (ISR UART → callback → MIDI.sendX()), la latence entre
réception d'un octet MIDI et émission vers la sortie est de l'ordre de
quelques dizaines de microsecondes — bien en dessous du seuil de perception
humain (~1 ms).

Pendant un sd_tick() à 3 ms, environ 9 octets MIDI arrivent sur chaque UART
(31 250 bauds = 3 125 octets/s). Le buffer RX de 1 024 octets absorbe ~330 ms
d'arrivée avant débordement — aucune perte dans ce cas.

━━━━━━━━━━━━━━━━━━━━━━━━━━━━━━━━━━━━━━━━━━━━━━━━━━━━━━━━━━━━━━━━━━━━━━━━━━━━━━
3. PARTAGE DU TEMPS : OLED ET CARTE SD
━━━━━━━━━━━━━━━━━━━━━━━━━━━━━━━━━━━━━━━━━━━━━━━━━━━━━━━━━━━━━━━━━━━━━━━━━━━━━━

─── 3.1  OLED SSD1306 (128×64, I2C 400 kHz) ────────────────────────────────

Un sendBuffer() — envoi du framebuffer complet 128×64 en I2C à 400 kHz —
prend environ 20 ms. C'est le plus grand consommateur de temps dans la boucle.
L'oscillateur SSD1306 est mis au maximum (0xF0) pour optimiser les temps.

Protection : rafraîchissement conditionnel à deux niveaux.

  Niveau 1 : ui_tick() n'est appelé que toutes les 50 ms
    (gardien : if millis()-lastUI > 50 dans loop())

  Niveau 2 : à l'intérieur de ui_tick(), le dessin n'est effectué que si
    nécessaire (flag need_anim, interaction utilisateur, ou entrée de menu).
    Sinon : return immédiat — aucun appel I2C.

  Conséquences pratiques :
    Mode logo/idle          : 0 dessin, OLED ne consomme rien du tout
    Menu sans interaction   : 0 dessin sauf animation en cours
    Mode MONITOR (VU-mètre) : redessin chaque 50 ms (~20 ms / 50 ms = 40% CPU)
    Interaction humaine     : 1 dessin ~20 ms, imperceptible

─── 3.2  Carte SD — Architecture ring buffer asynchrone ─────────────────────

Le SD recorder utilise une architecture ring buffer qui garantit que le flux
MIDI n'est JAMAIS bloqué par les écritures disque.

  rec_push()   — appelée dans _midi.h à chaque événement routé
    Durée : ~50 ns
    Action : copie 10 octets dans le ring buffer RAM. Ne bloque jamais.
    Structure d'un événement (10 octets) :
      [0-3]  timestamp micros() uint32_t little-endian
      [4]    sortie (1-9)
      [5]    source (0=PC/DAW, 1=A, 2=B, 3=C, 4=D, 5=E)
      [6]    type MIDI (0x90=NoteOn, 0x80=NoteOff, 0xB0=CC…)
      [7]    canal destination (1-16)
      [8]    data1 (note / numéro CC…)
      [9]    data2 (vélocité / valeur CC… / 0 si absent)

  sd_tick()    — appelée dans loop() à chaque itération
    Durée : ~0.5 µs si idle / 1-3 ms si write / pics jusqu'à 5-10 ms
    Action : écrit sur SD si >= 280 octets disponibles (28 événements)
    Batch max : 56 événements (504 octets) par appel pour plafonner la latence
    Sync : flush tous les ~4 Ko (pas à chaque write) pour limiter les délais

  Paramètres du ring buffer :
    Taille            : 4 096 octets (puissance de 2 → masquage binaire)
    Seuil d'écriture  : 280 octets (28 événements)
    Batch maximum     : 504 octets (56 événements)
    Préallocation SD  : 20 Mo au démarrage (~30h de MIDI dense)
      → évite la fragmentation et les délais FAT pendant la session

  Métriques exposées dans le menu Monitor :
    sd_max_us        : durée max d'un appel write() en µs (historique session)
    sd_spike_count   : nombre de writes ayant dépassé 3 000 µs

  MTP.loop() : accès aux fichiers REC*.DAT depuis le PC via USB (disque USB).
    Placé APRÈS sd_tick() pour donner priorité aux écritures MIDI.
    Peut bloquer plusieurs ms si le PC lit activement un fichier.

━━━━━━━━━━━━━━━━━━━━━━━━━━━━━━━━━━━━━━━━━━━━━━━━━━━━━━━━━━━━━━━━━━━━━━━━━━━━━━
4. 6 ENTRÉES + 9 SORTIES EN SIMULTANÉ — FAISABILITÉ
━━━━━━━━━━━━━━━━━━━━━━━━━━━━━━━━━━━━━━━━━━━━━━━━━━━━━━━━━━━━━━━━━━━━━━━━━━━━━━

Configuration maximale : 3 TRS IN (A, B + OUT5/6 reconfigurés non applicable)
                         + 3 USB Host IN (C, D, E)
                         = 5 entrées MIDI indépendantes (A, B, C, D, E)
                       : 6 TRS OUT (1, 2, 3, 4, 5, 6)
                         + 3 USB Host OUT (7, 8, 9)
                         = 9 sorties MIDI indépendantes

─── 4.1  Ce qui tourne vraiment en parallèle ────────────────────────────────

  UARTs TX : matériellement indépendants
    Quand MIDI1.sendNoteOn() écrit sur Serial8 et MIDI2.sendNoteOn() écrit
    sur Serial3, ces deux transmissions se font physiquement en même temps
    dans le silicium. Le CPU ne fait que remplir les buffers TX et passer à
    la suite. Les 6 ports TRS émettent donc en parallèle.

  UARTs RX : interruptions indépendantes
    Chaque port RX a sa propre ISR et son propre buffer de 1 024 octets.
    Les données arrivent en parallèle sur tous les ports.

  USB Host : contrôleur EHCI hardware
    Le contrôleur EHCI du Teensy 4.1 gère les transactions USB en hardware.
    myusb.Task() ne fait que drainer les buffers déjà remplis.

  USB Device (usbMIDI) : géré en interruption, indépendant du polling.

─── 4.2  Le vrai goulot : la bande passante MIDI TRS ────────────────────────

MIDI = 31 250 baud = ~3 125 octets/s = ~1 000 messages 3 octets/s par port.
C'est la limite physique du protocole, indépendante du Teensy.

  Scénario          Entrées→Sortie 1  Charge sortie 1  Résultat
  ───────────────────────────────────────────────────────────────────────
  Diagonal (A→1…)   1 seule entrée   ~100%             OK
  Merge 2→1         A + B            ~200%             Saturation si plein régime
  Live réaliste     6 entrées        6×50=300 msg/s    OK (~30% capacité)
  Stress test       6 entrées max    ~600%             Saturation certaine
  ───────────────────────────────────────────────────────────────────────

  Note : les sorties USB Host 7/8/9 ne sont pas concernées par ce goulot.
  USB Full Speed = 12 Mbps → ~40 000 messages MIDI/s. Pas de limite pratique.

─── 4.3  Comportement en cas de saturation d'une sortie TRS ─────────────────

Si une sortie TRS est saturée, MIDI.sendNoteOn() ne PERD PAS l'événement
mais BLOQUE jusqu'à ce qu'il y ait de la place dans le buffer TX (64 octets
par défaut = ~20 ms de MIDI).

Ce blocage stalle loop(), ce qui retarde la lecture des autres entrées.
Mais les buffers RX de 1 024 octets absorbent ~330 ms d'arrivée :
  → pas de perte de données, juste un retard temporaire.

─── 4.4  Synthèse des marges ─────────────────────────────────────────────────

  Ressource          Limite          Usage live typique   Marge
  ───────────────────────────────────────────────────────────────────────
  CPU (600 MHz)      ~millions msg/s quelques milliers/s  immense
  USB Host           ~40 000 msg/s   centaines/s          très large
  TRS IN (buffer)    ~1 000 msg/s    ~100-200/s           large
  TRS OUT (1 port)   ~1 000 msg/s    ~100-200/s (1:1)     confortable
  Merge N→1 TRS OUT  1 000 msg/s     N × flux entrée      risque si N > 3-4
                     partagés entre                        à plein régime
                     N sources
  ───────────────────────────────────────────────────────────────────────

CONCLUSION : 6 entrées + 9 sorties en simultané fonctionne sans problème
pour un usage musical normal. La seule limite réelle est physique (débit
MIDI 31 250 baud sur les sorties TRS), pas le Teensy. Un merge de plusieurs
entrées très actives vers la même sortie TRS peut provoquer un retard de
quelques ms, sans perte de données (grâce aux buffers RX de 1 Ko).

━━━━━━━━━━━━━━━━━━━━━━━━━━━━━━━━━━━━━━━━━━━━━━━━━━━━━━━━━━━━━━━━━━━━━━━━━━━━━━
5. SCHÉMA RÉCAPITULATIF DE LA BOUCLE PRINCIPALE
━━━━━━━━━━━━━━━━━━━━━━━━━━━━━━━━━━━━━━━━━━━━━━━━━━━━━━━━━━━━━━━━━━━━━━━━━━━━━━

+--------------------------------------------------------------+
|           BOUCLE PRINCIPALE  (polling pur, sans RTOS)        |
|    ~100 µs/iter idle          ~3-15 ms/iter avec SD+OLED     |
|                                                              |
|  TRS IN A/B    ISR UART -> buffer 1 Ko                       |
|  ----------->  MIDIA/B.read() polling       ~2 µs            |
|                callback -> route_matrix[in][ch][out]         |
|                   -> send TRS physique + USB miroir          |
|                      -> rec_push()  ~50 ns  (ring buf RAM)   |
|                                                              |
|  USB HOST C/D/E  myusb.Task() × 2 / boucle (avant+après SD) |
|  ------------>   MIDIUSBx.read() × 6                        |
|                  callback -> même pipeline que TRS           |
|                                                              |
|  USB PC (DAW)  usbMIDI.read() while loop                     |
|  ----------->  dispatch par câble USB (0-14)                 |
|                -> inject direct vers sorties physiques       |
|                                                              |
|  SD Recorder   sd_tick()  ~1-3 ms si 28+ events             |
|  ring 4 Ko ->  56 events × 10 B par écriture batch          |
|                sync() tous les ~4 Ko (pas à chaque write)    |
|                                                              |
|  OLED SSD1306  ui_tick() toutes les 50 ms                    |
|  I2C 400 kHz   sendBuffer() ~20 ms si interaction/animation  |
|                skip complet si pas d'interaction (0 I2C)     |
+--------------------------------------------------------------+

  UARTs hardware (TX) : 6 ports TRS émettent EN PARALLÈLE dans le silicium
  UARTs hardware (RX) : 5 ports écoutent EN PARALLÈLE via ISR
  USB Host EHCI       : transactions USB gérées EN PARALLÈLE par le contrôleur
  CPU                 : séquentiel mais ~600 MHz, routing ~5 µs/message

================================================================================
  Fin des notes — miniMoc firmware v2.0.2
================================================================================

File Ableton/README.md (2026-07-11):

# AutoTrackCreator - POC Ableton Live

Script MIDI Remote Script pour Ableton Live qui crée automatiquement une piste MIDI avec un routage configurable.

Compatible avec Ableton Live Lite 11 et versions supérieures.

## Installation

### Automatique

```bash
python install.py
```

Options :
- `--symlink` : crée un lien symbolique au lieu de copier (pratique pour le dev, nécessite admin)
- `--system` : installe dans le chemin système au lieu du chemin utilisateur (nécessite admin)

### Manuelle

Copier le dossier `AutoTrackCreator/` dans le répertoire User Remote Scripts d'Ableton :

```
%APPDATA%\Ableton\Live 11.x.x\Preferences\User Remote Scripts\
```

## Configuration

### Activer dans Ableton

1. (Re)démarrer Ableton Live
2. Aller dans **Preferences > Link/Tempo/MIDI**
3. Dans un slot Control Surface, sélectionner **AutoTrackCreator**
4. Input/Output MIDI : laisser sur "None"

### Configurer le routage MIDI

Éditer le fichier `config.json` dans le dossier installé :

```json
{
  "track_name": "Auto-MIDI",
  "midi_input": "Nom du peripherique input",
  "midi_input_channel": "All Channels",
  "midi_output": "Nom du peripherique output",
  "midi_output_channel": "All Channels"
}
```

Pour connaître les noms exacts des périphériques disponibles, consulter le fichier `Log.txt` après le premier lancement. Le script y liste tous les périphériques détectés.

Laisser un champ vide (`""`) pour garder le routage par défaut d'Ableton.

### Chemin du Log.txt

```
%APPDATA%\Ableton\Live 11.x.x\Preferences\Log.txt
```

Chercher les lignes contenant `AutoTrackCreator` pour voir les messages du script.

## Workflow typique

1. `python install.py`
2. Ouvrir Ableton, activer AutoTrackCreator dans les préférences
3. La piste "Auto-MIDI" est créée, Log.txt liste les périphériques
4. Éditer `config.json` avec les noms souhaités
5. Relancer Ableton (ou désélectionner/resélectionner le Control Surface)
6. La piste est créée avec le bon routage

## Limitations

- **Live Lite** : maximum 8 pistes MIDI + 8 pistes Audio
- Pas de rechargement à chaud : il faut relancer Ableton ou basculer le Control Surface pour recharger le script
- Python 3.7 (version embarquée dans Ableton 11)

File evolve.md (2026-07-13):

# Faisabilité : Transformateurs & Générateurs MIDI sur miniMoc

## Contexte

miniMoc est un routeur MIDI DAWless (Teensy 4.1, écran OLED 128x64, encodeur rotatif) avec un éditeur web compagnon "weblink" (Web MIDI/SysEx + Web Serial pour le flashage). Aujourd'hui, la matrice de routage (`route_matrix`, `firmware/logic.h:104-198`) ne fait que **recopier les messages MIDI d'une entrée vers une sortie**, avec au maximum un remap de canal — aucun traitement du message lui-même.

L'idée : ajouter deux familles de blocs de traitement, comme le font d'autres équipements MIDI (Retrokits RK-006, Squarp Hermod, Chase Bliss, etc.) :
- **Transformateurs** — modifient un message MIDI existant en transit (transpose, scale/clamp de vélocité, remap/scale/quantize de CC, offset de PC, scale de pitch bend, etc.)
- **Générateurs** — produisent eux-mêmes des messages MIDI de façon autonome (LFO, arpégiateur, séquenceur euclidien)

Ces deux enums (`TransformType`, `GeneratorType`) n'existent pas dans le code actuel — c'est un **greenfield feature**, pas une fonctionnalité à terminer. Il n'y a aucune trace dans le CHANGELOG ou l'historique git. Ce document est une évaluation de faisabilité et un espace de réflexion architecturale, pas encore un plan d'implémentation détaillé.

## Ce qui existe et sur quoi ça s'accrocherait

- **Routage** (`firmware/logic.h:104-198`, `firmware/_midi.h`) : `route_matrix[in_port][in_chan][out_port]` est une table booléenne + remap de canal, construite depuis `basic_matrix` et une liste de règles `Flux` (`flux_list[16]`, chacune avec des slots d'entrée/sortie). Les handlers (`handleNoteOn/Off`, `handleControlChange`, `processPitchBend`, `processAfterTouch`, `handleProgramChange` dans `_midi.h`) font le lookup puis envoient directement (`SEND_NOTE_ON` etc.) — **aucun point d'accroche pour un traitement intermédiaire n'existe aujourd'hui**.
- **UI on-device** (`firmware/routing_submenu.h`) : un menu en wizard (liste de Flux → étape entrées → étape sorties → sélecteur de canal par port). L'écran 128px est déjà serré ; un écran générique "liste de paramètres" serait nécessaire pour éditer des transforms (pas juste réutiliser les grilles fixes actuelles).
- **weblink** (`weblink/index.html`) : mirroir exact du firmware — `FluxEditor`, SysEx opcodes 0x04–0x0D déjà occupés (BPM, matrice, flux, sync, contraste, host config). Un mécanisme de version/bump SysEx existe déjà (`0x0A`), donc étendre le protocole est un problème déjà anticipé, pas un blocage.
- **Contraintes temps réel** : le clock est déjà géré par ISR (`_midi.h:135-176`, marqué real-time-critical, non-blocking). Tout générateur autonome (LFO/arpège/euclidien) devra s'accrocher à cette horloge existante plutôt que d'en créer une nouvelle.

## Analyse de faisabilité

**Verdict : oui, c'est faisable et réaliste — mais ce n'est pas un petit patch.** C'est une fonctionnalité transverse qui touche le firmware (dispatch + stockage EEPROM), l'UI OLED, l'UI weblink et le protocole SysEx simultanément. Rien n'est architecturalement bloqué ni n'exige de bricolage exotique : ce sont des traitements MIDI simples et bien connus (transpose, scale, clamp, remap, LFO, euclidien...), déjà faits dans d'autres équipements.

### Transformateurs — complexité modérée, à faire en premier
- Modèle de données : attacher un transform optionnel à chaque `Flux` (le concept de "règle" existe déjà, c'est une extension naturelle plutôt qu'une nouvelle structure).
- Point d'accroche : insérer l'appel du transform entre le lookup `route_matrix` et les `SEND_*`, dans ~5-6 handlers — mécanique mais répétitif.
- Coût CPU : négligeable (arithmétique simple), aucun souci sur un Teensy 4.1 à 600 MHz.
- Stockage EEPROM : de la place libre (prochain octet libre ~39), mais la disposition doit être versionnée proprement (le projet a déjà un mécanisme de migration via l'OTA/version bump).
- UI OLED + weblink : travail répétitif (un écran/formulaire par type de transform), pas complexe individuellement mais volumineux si on veut couvrir les ~25 types listés.

### Générateurs — plus complexe, à faire ensuite
- Contrairement aux transforms, un générateur n'est **pas déclenché par une entrée** — c'est une source autonome qui doit être routée vers une ou plusieurs sorties. Idée à valider : le traiter comme une "entrée virtuelle" dans `flux_list`, ce qui réutiliserait gratuitement toute la UI et la logique de routage existantes pour ses sorties — probablement le levier de simplification le plus important du projet.
- LFO : simple (forme d'onde, taux, sync clock, CC cible) — complexité modérée.
- Arpégiateur : état des notes tenues, modes de direction, latch — complexité moyenne-haute, plus de cas limites.
- Euclidien : peut réutiliser l'infra de clock/division déjà présente (`TRANS_CLOCK_DIVIDER` est dans la même famille d'idée) — modéré.
- Risque principal : tout code de tick doit respecter les contraintes non-bloquantes déjà en place dans l'ISR de clock.

### Effort réaliste
Pas une fonctionnalité de "quelques heures" — plutôt un projet de plusieurs semaines si on veut une poignée de transforms + 2-3 générateurs avec firmware **et** weblink à jour, fait type par type de façon incrémentale. Le principal risque n'est pas technique mais de **volume** : chaque nouveau type de transform/générateur implique un écran OLED + un formulaire weblink + un opcode SysEx à maintenir en synchro des deux côtés.

## Décisions prises

1. **Transform attaché à la route individuelle (niveau Flux)** — chaque `Flux` porte un transform optionnel ; cohérent avec le fait que `Flux` est déjà l'unité de règle dans `flux_list`.
2. **Générateur = entrée virtuelle** — un générateur (LFO, arpégiateur, euclidien) est traité comme une source supplémentaire aux côtés des 5 ports d'entrée physiques, et se raccorde à des sorties via le mécanisme `Flux` existant. Ça évite de dupliquer la logique de routage/canaux pour les générateurs.
3. **Un écran OLED dédié par type de transform** — pas d'écran générique "liste de paramètres" mutualisé ; chaque type de transform (transpose, vel scale, CC remap, etc.) a son propre écran de configuration, plus simple à lire sur 128x64 mais plus de volume de code UI à produire et maintenir (et à répliquer côté weblink).

Prochaine étape si on avance : définir précisément la structure de données du transform attaché au Flux (union/struct par type ? enum + params génériques ?) et le nouveau format d'entrée virtuelle pour les générateurs, avant de toucher au firmware.

## État

Faisabilité confirmée, décisions d'architecture verrouillées (ci-dessus). Pas de code écrit. En attente d'une demande explicite pour passer à un plan d'implémentation détaillé (structures de données précises, découpage des opcodes SysEx, ordre des types de transform/générateur à livrer en premier).

## POC recommandé : TRANS_NOTE_TRANSPOSE

Premier transform à coder : transpose de note (offset signé, ex. -24..+24 demi-tons), attaché à un `Flux`. Choisi parce que :
- Un seul paramètre (int8), pas de courbe/plage à gérer — valide la plomberie complète (Flux → EEPROM → firmware → OLED → weblink → SysEx) sans complexité annexe.
- Utile en soi (adapter le registre entre clavier/synthé, décaler un séquenceur).
- Touche exactement 2 handlers (`handleNoteOn`/`handleNoteOff` dans `_midi.h`), assez pour valider le pattern d'insertion du hook sans la variété CC/PC/PB/AT.
- UI minimale des deux côtés (un seul widget valeur, OLED + weblink).

Une fois ce transform validé bout-en-bout, les ~24 autres types deviennent un travail répétitif plutôt qu'un risque architectural.

## Extension architecturale : points virtuels (patch bay)

Idée proposée : généraliser "générateur = source virtuelle" en introduisant des **points virtuels** qui peuvent être à la fois :
- la **destination** d'un Flux (au lieu d'un port de sortie physique)
- la **source** d'un autre Flux (au lieu d'un port d'entrée physique / générateur)

Ça transforme le modèle actuel (table plate `route_matrix` : une entrée → une sortie) en un **graphe de patch** permettant de chaîner plusieurs transforms en série (`entrée → transform A → point virtuel → transform B → sortie`) et de faire du fan-in/fan-out entre points virtuels — beaucoup plus de combinaisons qu'un simple transform mono-étape entre une entrée et une sortie.

**Implications architecturales :**
- **Espace des ports élargi** : entrées physiques + générateurs + points virtuels comme sources ; sorties physiques + points virtuels comme destinations. Extension de la liste déjà proposée dans le wizard OLED / `FluxEditor` weblink, pas un nouveau paradigme d'UI.
- **Détection de cycle nécessaire** : un point virtuel étant source ET destination, une boucle est possible (A → ... → A) — à détecter à la validation de la config (DFS/tri topologique), jamais au runtime.
- **Résolution recommandée à la config, pas au runtime** : aplatir/précalculer le graphe en une séquence de transforms lors d'un changement de config (comme le fait déjà `recompute_route_matrix()`), pour garder les handlers temps réel (`_midi.h`, ISR clock) aussi simples qu'aujourd'hui — un simple lookup + séquence de transforms précalculée, sans marche de graphe par message.
- **Stockage** : coût EEPROM marginal (juste un id de port supplémentaire), le vrai coût est en logique de validation/aplatissement à la config.

**Verdict** : faisable, et ça augmente significativement la puissance du système (vrai patch bay chaînable) sans compromettre le temps réel, à condition d'aplatir le graphe à la config plutôt que de le parcourir en live. C'est une extension architecturale plus large que les 3 décisions initiales — à traiter comme une itération après le POC transpose, pas en même temps.

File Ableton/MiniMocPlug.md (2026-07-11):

# MiniMocPlug — Création dynamique de pistes via SysEx du MINIMOC

> Ce document décrit l'extension future du script AutoTrackCreator pour recevoir des commandes SysEx du MINIMOC et créer des pistes dynamiquement.

## Principe

Le MINIMOC envoie des messages MIDI SysEx à Ableton. Le script AutoTrackCreator les intercepte, parse le payload JSON, et crée les pistes avec le routage demandé.

## Protocole SysEx

### Format du message

```
F0 7D 01 <commande> <payload JSON en ASCII> F7
```

| Octet | Valeur | Signification |
|---|---|---|
| `F0` | Fixe | Début SysEx |
| `7D` | Fixe | Manufacturer ID non-commercial (réservé par la spec MIDI, usage privé) |
| `01` | Fixe | Device ID AutoTrackCreator |
| `<cmd>` | Variable | Commande (voir ci-dessous) |
| Payload | Variable | Chaîne JSON encodée en ASCII 7-bit |
| `F7` | Fixe | Fin SysEx |

### Commandes

| Commande | Octet | Payload | Description |
|---|---|---|---|
| Créer piste | `0x01` | JSON | Crée une piste avec la config spécifiée |
| Supprimer piste | `0x02` | JSON | Supprime une piste par nom |
| Ping | `0x03` | Aucun | Heartbeat — le script répond avec un acquittement |

### Payload "Créer piste"

```json
{
  "type": "midi",
  "port": 3,
  "name": "Synth",
  "channel": 1
}
```

| Champ | Type | Requis | Valeurs | Description |
|---|---|---|---|---|
| `type` | string | Oui | `"midi"` ou `"audio"` | Type de piste |
| `port` | integer | Oui (MIDI) | 2-16 | Numéro de port MINIMOC → dérivé en `MIDIIN{port} (MINIMOC)` / `MIDIOUT{port} (MINIMOC)` |
| `name` | string | Oui | ASCII | Nom affiché de la piste |
| `channel` | integer | Non | 1-16 | Canal MIDI. 0 ou absent = "All Channels" |

### Payload "Supprimer piste"

```json
{
  "name": "Synth"
}
```

### Réponse d'acquittement (vers le MINIMOC)

```
F0 7D 01 7F <status> <JSON> F7
```

- `status` : `0x00` = succès, `0x01` = erreur
- JSON : `{"cmd":1,"ok":true}` ou `{"cmd":1,"ok":false,"error":"message"}`

## Exemples SysEx concrets

### Ping
```
F0 7D 01 03 F7
```

### Créer une piste MIDI "Synth" sur le port 3, canal 1
```
F0 7D 01 01 7B 22 74 79 70 65 22 3A 22 6D 69 64 69 22 2C 22 70 6F 72 74 22 3A 33 2C 22 6E 61 6D 65 22 3A 22 53 79 6E 74 68 22 2C 22 63 68 61 6E 6E 65 6C 22 3A 31 7D F7
```
(= `{"type":"midi","port":3,"name":"Synth","channel":1}` en hexadécimal ASCII)

### Supprimer la piste "Synth"
```
F0 7D 01 02 {"name":"Synth"} F7
```

## Modifications du script à réaliser

### 1. `AutoTrackCreator.py`

**Nouvelles constantes :**
```python
SYSEX_HEADER = (0xF0, 0x7D, 0x01)
CMD_CREATE_TRACK = 0x01
CMD_DELETE_TRACK = 0x02
CMD_PING = 0x03
SYSEX_RESPONSE = 0x7F
STATUS_OK = 0x00
STATUS_ERROR = 0x01
```

**Modifications du `__init__` :**
- Ajouter `self._dynamic_tracks = []` pour tracker les pistes créées dynamiquement
- Conditionner la création initiale sur `config.get('create_initial_track', True)`

**Nouvelles méthodes :**

- `handle_sysex(midi_bytes)` — override du parent `ControlSurface`. Vérifie l'en-tête `F0 7D 01`, extrait la commande et le payload, dispatche vers le bon handler.

- `_handle_command(command, payload_bytes)` — Parse le JSON du payload et dispatche vers `_handle_create_track` ou `_handle_delete_track`.

- `_handle_create_track(payload)` — Crée la piste (MIDI ou Audio), stocke la référence dans `_dynamic_tracks`, puis diffère le routage via `schedule_message(DEFERRED_DELAY_TICKS, callback, (track, routing_config))`.

- `_build_routing_config(track_type, port, channel)` — Convertit le numéro de port en noms de périphériques via les templates `port_name_format` du config.json. Ex: port=3 → `"MIDIIN3 (MINIMOC)"`.

- `_deferred_dynamic_setup(params)` — Callback différé qui applique le routage via `_apply_routing()` (méthode existante réutilisée).

- `_handle_delete_track(payload)` — Supprime par nom, uniquement parmi `_dynamic_tracks`.

- `_send_ack(command, success, error_msg)` — Envoie un SysEx d'acquittement via `self._send_midi()`.

**Méthodes existantes réutilisées sans modification :**
- `_apply_routing()`, `_set_routing()`, `_log_available_routing()`, `_load_config()`

### 2. `config.json` — Nouveau schéma

```json
{
  "create_initial_track": true,
  "track_name": "Auto-MIDI",
  "midi_input": "MIDIIN2 (MINIMOC)",
  "midi_input_channel": "All Channels",
  "midi_output": "MIDIOUT2 (MINIMOC)",
  "midi_output_channel": "",
  "port_name_format": {
    "input": "MIDIIN{port} (MINIMOC)",
    "output": "MIDIOUT{port} (MINIMOC)"
  }
}
```

- `create_initial_track` : si `true`, crée la piste au démarrage (comportement actuel). `false` pour tout gérer via SysEx.
- `port_name_format` : templates pour dériver les noms de périphériques à partir du numéro de port. Adaptable à d'autres routeurs MIDI.

### 3. `__init__.py` — Ajouter `get_capabilities()`

```python
from _Framework.Capabilities import (
    PORTS_KEY, NOTES_CC, SCRIPT, REMOTE,
    inport, outport,
)

def get_capabilities():
    return {
        PORTS_KEY: [
            inport(props=[NOTES_CC, SCRIPT, REMOTE]),
            outport(props=[SCRIPT, REMOTE]),
        ]
    }

def create_instance(c_instance):
    from .AutoTrackCreator import AutoTrackCreator
    return AutoTrackCreator(c_instance)
```

### 4. `install.py`

Mettre à jour les instructions "Next steps" pour mentionner l'assignation du MIDI Input.

## Contrainte importante : port de contrôle dédié

Le port MIDI assigné comme Control Surface Input est **consommé** par le Control Surface — il n'apparaîtra plus comme entrée MIDI disponible sur les pistes.

**Recommandation :** Dédier le **port 2 du MINIMOC** au contrôle SysEx. Les ports 3-16 restent disponibles pour le routage musical des pistes.

## Configuration dans Ableton

1. Preferences > Link/Tempo/MIDI
2. Control Surface : **AutoTrackCreator**
3. MIDI Input : **MIDIIN2 (MINIMOC)** (port de contrôle)
4. MIDI Output : **MIDIOUT2 (MINIMOC)** (pour les acquittements, optionnel)

## Vérification

1. `python install.py` → copier vers Ableton
2. Redémarrer Ableton, configurer AutoTrackCreator avec MIDI Input = `MIDIIN2 (MINIMOC)`
3. Envoyer un ping : `F0 7D 01 03 F7` → vérifier "Ping received" dans Log.txt
4. Créer une piste : `F0 7D 01 01 {"type":"midi","port":3,"name":"Synth","channel":1} F7`
5. Vérifier qu'une piste "Synth" apparaît, routée sur MIDIIN3/MIDIOUT3 (MINIMOC), canal 1
6. Tester la suppression : `F0 7D 01 02 {"name":"Synth"} F7`
7. Tester les erreurs : limite de pistes (Live Lite: 8 MIDI + 8 Audio), JSON invalide

## Notes techniques

- **Timing** : Le routage est appliqué en différé (`schedule_message`, 10 ticks) car les propriétés de routage ne sont pas disponibles immédiatement après la création de la piste.
- **Python 3.7** : Pas de f-strings, utiliser `.format()`. Pas de walrus operator.
- **Taille SysEx** : Garder les noms de pistes courts (< 50 caractères). Les payloads typiques font ~50 octets, bien dans les limites.
- **Messages simultanés** : Si le MINIMOC envoie plusieurs commandes rapidement, espacer d'au moins ~100ms pour éviter de surcharger Ableton.
- **Référence de piste invalide** : Dans le callback différé, vérifier que la piste existe encore avant d'appliquer le routage (l'utilisateur pourrait la supprimer manuellement entre-temps).

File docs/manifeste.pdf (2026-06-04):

Bonjour à tous,

Il y a un an, je cherchais un appareil qui n'existait pas. Alors je l'ai fabriqué.
Aujourd'hui, j'en ai six exemplaires, et je cherche six musiciens pour inventer la suite avec moi : les fonctions à ajouter, à améliorer.

Je suis François Jacob, ingénieur en informatique et électronicien. Je fais de la musique électronique en amateur, pendant mon temps libre.

J'ai commencé sur PC. Mais pour moi, le PC, ce n'est pas un instrument de musique. Ça tue toute inspiration. Alors, je suis passé au DAWless* pour retrouver le contact avec les instruments. Mais là, deux murs. D'abord la galère des branchements et des setups qu’il faut toujours faire et refaire. Ensuite, le pire : enchaîner des impros, et à la fin, tout perdre car rien n’avait été enregistré.

L’idéal pour moi c’est juste de m'asseoir, d’allumer mes instruments et de jouer — puis de retrouver toutes mes sessions d’impro, intactes, dans l’ordinateur pour les finaliser. N'ayant pas trouvé de solution dans les produits existants, j'ai décidé d'utiliser mes compétences pour fabriquer le miniMoc.

Le miniMoc, ce sont deux étapes essentielles:

1 - Pendant les impros, il fait dialoguer toutes tes machines midi entre elles, avec ou sans ordinateur.

2 - Après, il permet de récupérer toutes les sessions dans le logiciel de prod, pour finaliser — sans rien rebrancher.

Concrètement :

- Un boîtier compact qui route et enregistre tout le setup MIDI, sans ordinateur ;
- Toutes les sessions sauvegardées automatiquement en MIDI, prêtes à être rejouées ou exportées ;
- Branché, allumé, ça marche — pas de PC, pas de configuration interminable.

Le matériel est abouti et stable : le routage, l'interface et le Smart Mirror sont solides et éprouvés. Mais ce n’est pas tout car les possibilités d'évolution du logiciel sont immenses. Et le Minimoc peut se mettre à jour par un simple site web.

Je ne suis ni une multinationale ni une start up en quête de profit. Je suis un musicien et un artisan qui vous ouvre la porte de son atelier.

Ce que je propose à mes 6 compagnons de route :

- Vous recevez un miniMoc fonctionnel, assemblé à la main, pour un prix modeste.
- En échange, vous l'intégrez à votre setup et vous me faites des retours honnêtes : ce qui marche, ce qui coince, ce qui manque.
- Vous suggérez et votez sur les prochaines fonctionnalités prioritaires. On construit le produit ensemble.

- Tous les firmwares, présents et à venir, sont gratuits et le code est libre, à vie. Vous pouvez le customiser, le partager, le faire vôtre. (*)

Soyons clairs : vous faites partie de la première série. L'appareil tourne, je l'utilise dans mes propres sessions. Mais comme on défriche ensemble, vous croiserez peut-être un bug ou deux — c'est justement ce qui fait de vous des co-créateurs, des expérimentateurs, pas de simples consommateurs.

Si vous vous reconnaissez dans ce besoin de protéger vos impros et de jouer sans vous prendre la tête avec la technique, écrivez-moi. On prendra le temps d'échanger sur vos configurations pour voir si on peut avancer ensemble. »

(*): la seule restriction, pour protéger mon travail (et le votre) est que toute commercialisation du code ou du hardware nécessite sans mon autorisation.

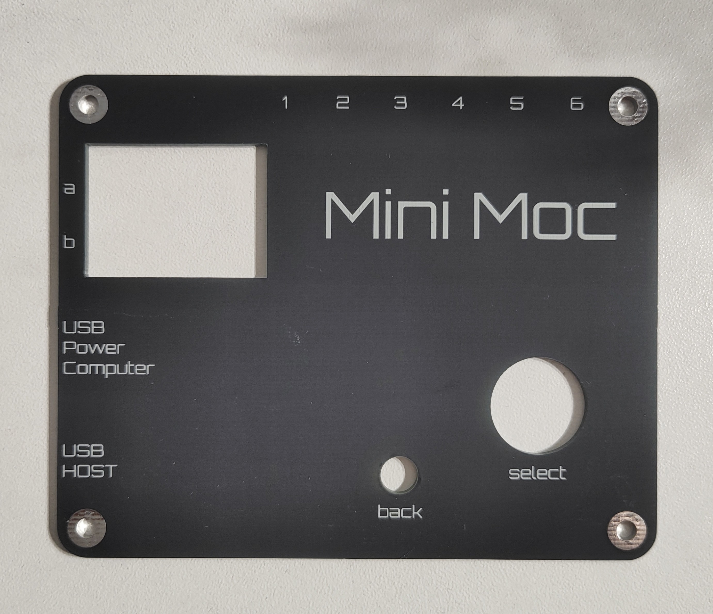
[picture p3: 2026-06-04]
hardware/dessus.jpg

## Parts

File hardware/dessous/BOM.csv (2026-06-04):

Reference | Qty | Value | DNP | Exclude from BOM | Exclude from Board | Footprint | Datasheet
C1,C2 | 2 | 104 |  |  |  | Capacitor_THT:C_Disc_D5.0mm_W2.5mm_P2.50mm | ~
D1,D2 | 2 | 1N4148 |  |  |  | Diode_THT:D_DO-35_SOD27_P7.62mm_Horizontal | https://assets.nexperia.com/documents/data-sheet/1N4148_1N4448.pdf
G1 | 1 | SW_Omron_B3FS |  |  |  | Button_Switch_THT:SW_TH_Tactile_Omron_B3F-100x | https://omronfs.omron.com/en_US/ecb/products/pdf/en-b3fs.pdf
MIDI_IN1,MIDI_IN2,MIDI_OUT1,MIDI_OUT2,MIDI_OUT3,MIDI_OUT4,MIDI_OUT5,MIDI_OUT6 | 8 | Conn_01x04_Pin |  |  |  | Connector_Audio:Jack_3.5mm_PJ320E_Horizontal | ~
OLED1 | 1 | Conn_01x04_Pin |  |  |  | KICAD:128x64OLED | ~
R1,R2 | 2 | 470 |  |  |  | Resistor_THT:R_Axial_DIN0207_L6.3mm_D2.5mm_P10.16mm_Horizontal | ~
R3,R4 | 2 | 220 |  |  |  | Resistor_THT:R_Axial_DIN0207_L6.3mm_D2.5mm_P10.16mm_Horizontal | ~
R5,R6,R7,R8,R9,R10,R11,R12,R13,R14,R15,R16 | 12 | 47 |  |  |  | Resistor_THT:R_Axial_DIN0207_L6.3mm_D2.5mm_P10.16mm_Horizontal | ~
SW1 | 1 | RotaryEncoder_Switch |  |  |  | Rotary_Encoder:RotaryEncoder_Alps_EC11E-Switch_Vertical_H20mm | ~
TEENSY1 | 1 | Teensy4.1 |  |  |  | teensy:Teensy41
U2,U3 | 2 | 6N138 |  |  |  | Package_DIP:DIP-8_W10.16mm_LongPads | http://www.onsemi.com/pub/Collateral/HCPL2731-D.pdf
USB1 | 1 | USB_A |  |  |  | Connector_USB:USB_A_Stewart_SS-52100-001_Horizontal | ~

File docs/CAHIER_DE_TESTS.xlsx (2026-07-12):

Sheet: 0-Config
miniMoc — Configuration matérielle de test
Entrées
Port | Type | Appareil
A | TRS | Novation SL MK2
B | TRS | Electribe 2
C | USB Host | Arturia MiniLab
D | USB Host | (libre — tests de branchement à chaud)
E | USB Host | (libre — tests de branchement à chaud)
Sorties
Port | Type | Appareil
1 | TRS | Dreadbox Typhon
2 | TRS | Minifreak
3 | TRS | Electribe 2
4 | TRS | reface CP
5 | TRS | Keytron SD1000
6 | TRS | Novation SL MK2
7 | USB Host | OP-1
8 | USB Host | (libre)
9 | USB Host | (libre)
Poste informatique
Rôle | Machine
Smart Mirror / enregistrement DAW | PC + Ableton Live (branché en USB sur le miniMoc)
Éditeur web (weblink) | PC + navigateur Chrome ou Edge, weblink/index.html (ou URL hébergée)
Point d'attention config : l'Electribe 2 est câblée à la fois en entrée B et en sortie 3, et le Novation SL MK2 à la fois en entrée A et en sortie 6. Vérifier lors des tests de bouclage qu'un message n'est pas indéfiniment renvoyé vers sa propre source (voir MATRICE-05, FLUX-06). Point d'attention USB Host : MiniLab (entrée C) et OP-1 (sortie 7) sont deux appareils USB distincts. En mode AUTO, l'assignation des slots est FIFO — l'ordre de branchement détermine qui devient C/D/E. Testé en section 7 (HOST CONFIG).

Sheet: Synthese
miniMoc — Synthèse des tests
Thème | Nb tests | OK | KO | Non testé / vide
1-Connectique | 5
2-Matrice | 9
3-Flux | 7
4-Sync | 9
5-Transport | 10
6-Presets | 7
7-HostConfig | 9
8-Monitor | 8
9-System | 6
10-SmartMirror | 8
11-RecordSD | 6
12-Weblink | 10
13-Robustesse | 6
TOTAL

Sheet: 1-Connectique
ID | Procédure | Résultat attendu | Résultat | Commentaire
CONN-01 | Démarrer le miniMoc sans rien de branché | Écran logo puis carousel s'affiche normalement, aucun blocage
CONN-02 | Brancher Novation SL MK2 sur A, Electribe 2 sur B (câbles TRS) | MONITOR (page VU-mètres) affiche une activité sur A et B dès qu'une note est jouée sur chaque appareil
CONN-03 | Brancher MiniLab sur un port USB Host du miniMoc | SYSTEM → INFO liste MiniLab parmi les devices USB (D1..D6) ; MONITOR affiche l'activité sur le port logique C (mode AUTO, 1er device = C)
CONN-04 | Brancher les 6 sorties TRS (Typhon=1, Minifreak=2, Electribe2=3, reface CP=4, Keytron=5, SL MK2=6) et OP-1 sur une sortie USB Host | SYSTEM → INFO confirme la présence d'OP-1 ; aucune sortie TRS ne nécessite de config
CONN-05 | Débrancher puis rebrancher le câble USB PC pendant que le miniMoc fonctionne seul (sans PC) | Le routage MIDI matériel (TRS/USB Host) continue de fonctionner sans interruption pendant le débranchement

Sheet: 2-Matrice
ID | Procédure | Résultat attendu | Résultat | Commentaire
MATRICE-01 | Charger le preset d'usine VIDE, jouer une note sur Novation SL MK2 (A) | Aucune sortie ne reçoit la note
MATRICE-02 | Activer la cellule [A, 1] (MATRICE), jouer une note sur A | Dreadbox Typhon (sortie 1) reçoit la note, sur tous les canaux (passthrough canal)
MATRICE-03 | Activer [A,1] et [A,2] simultanément | Note de Novation SL MK2 arrive à la fois sur Typhon (1) et Minifreak (2)
MATRICE-04 | Charger le preset DIAGONALE (A→1, B→2, C→3, D→4, E→5) | Novation SL MK2 (A) → Typhon (1) ; Electribe2 (B) → Minifreak (2) ; MiniLab (C) → Electribe2 (3)
MATRICE-05 | Activer [B,3] (Electribe2 → Electribe2 en sortie 3) | La note jouée sur l'Electribe2 (entrée B) ressort sur sa propre entrée MIDI (sortie 3) — vérifier absence de boucle infinie ou de blocage
MATRICE-06 | Charger le preset MERGE | Toutes les entrées (A,B,C) arrivent sur toutes les sorties actives ; jouer sur MiniLab (C) doit atteindre les 6 sorties TRS + OP-1 (7)
MATRICE-07 | Charger USB>TRS | MiniLab (C, entrée USB) routé vers les sorties TRS 1–6 ; aucune sortie vers OP-1 (7)
MATRICE-08 | Charger TRS>USB | Novation SL MK2 (A) et Electribe2 (B) routés vers OP-1 (sortie 7 USB Host) ; aucune sortie TRS
MATRICE-09 | Désactiver toutes les cellules (retour VIDE) puis vérifier via MONITOR | Barres d'entrée VU-mètre continuent de s'allumer (réception indépendante du routage) mais aucune sortie ne s'anime

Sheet: 3-Flux
ID | Procédure | Résultat attendu | Résultat | Commentaire
FLUX-01 | Créer un flux : Entrée B canal 10 uniquement → Sortie 3 canal 1 (remap) | Jouer canal 10 sur Electribe2 (B) → arrive sur Electribe2 (sortie 3) reconverti en canal 1 ; jouer canal 1 sur B ne passe pas
FLUX-02 | Créer un flux : Entrée A (ALL canaux) → Sortie 6 (ALL, passthrough) | Toute note de Novation SL MK2 (A), quel que soit le canal, ressort sur sa propre sortie 6 (SL MK2), canal conservé
FLUX-03 | Créer un flux multi-entrées : {A, ch1} + {B, ch2} → {sortie 4, ch1} | ch1 de SL MK2 et ch2 d'Electribe2 arrivent tous deux sur reface CP (sortie 4) en canal 1
FLUX-04 | Créer 16 flux (maximum) | Le 17e flux est refusé ou impossible à créer (limite respectée)
FLUX-05 | Activer un flux ET la cellule MATRICE correspondante en parallèle (ex FLUX-01 + MATRICE [B,3]) | Doublement du signal MIDI observé sur Electribe2 sortie 3 (comportement cumulatif documenté — non un bug)
FLUX-06 | Modifier un flux existant (bouton Éditer) puis le supprimer (✕) | Modification appliquée immédiatement ; suppression stoppe le routage correspondant sans affecter les autres flux/matrice
FLUX-07 | Créer un flux avec sélection multi-canaux via la grille 4×4 (ex. ch1, ch3, ch7 sur MiniLab C) | Seules les notes sur les canaux cochés passent, les autres canaux de C sont bloqués pour ce flux

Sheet: 4-Sync
ID | Procédure | Résultat attendu | Résultat | Commentaire
SYNC-01 | Régler SYNC = A (TRS), envoyer Clock depuis Novation SL MK2 sur l'entrée A | Toutes les sorties actives (TRS 1–6 + OP-1 si branché) reçoivent le Clock ; MONITOR page BPM affiche le tempo mesuré
SYNC-02 | Régler SYNC = C (USB Host), envoyer Clock depuis MiniLab | Clock diffusé sur toutes les sorties ; vérifier qu'aucune autre source n'est écoutée en parallèle
SYNC-03 | Régler SYNC = A (USB/PC), envoyer Clock depuis Ableton via le câble miroir A | Clock d'Ableton propagé sur les sorties, alors qu'un clock TRS simultané sur l'entrée physique A est ignoré
SYNC-04 | Envoyer simultanément un Clock TRS sur A et un Clock USB/PC sur le miroir A, avec SYNC=A (TRS) | Seul le clock TRS physique est suivi, le clock USB/PC est ignoré (pas de tempo instable/mélangé)
SYNC-05 | Régler SYNC = MINIMOC, définir un BPM via le menu TRANSPORT | Le miniMoc génère lui-même le Clock en continu, y compris en naviguant dans d'autres menus ou avec le VU-mètre MONITOR actif
SYNC-06 | SYNC = MINIMOC, envoyer volontairement un Start MIDI externe depuis SL MK2 sur A | Le Start externe est ignoré (seule la source sélectionnée est maître)
SYNC-07 | Régler SYNC = OFF | Aucun Clock/Start/Stop/Continue n'est propagé sur aucune sortie, quel que soit ce qui est branché en entrée
SYNC-08 | Parcourir la liste des 11 sources + OFF depuis l'écran OLED SYNC | La source active est marquée d'un *, indépendamment de la position du curseur ; le choix est conservé après redémarrage (persistance EEPROM)
SYNC-09 | Sélectionner une source SYNC depuis l'onglet SYNC de l'éditeur web | Réglage appliqué et sauvegardé immédiatement, visible aussi sur l'écran OLED

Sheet: 5-Transport
ID | Procédure | Résultat attendu | Résultat | Commentaire
TRSP-01 | Entrer dans le menu TRANSPORT, tourner l'encodeur (SYNC=MINIMOC) | BPM affiché change de ±1 ; ±5 si rotation rapide (< 180 ms entre crans)
TRSP-02 | Clic encodeur (1er appui) | Indicateur passe à PLAY, un message Start (FA) est envoyé sur toutes les sorties + miroir PC
TRSP-03 | Clic simple BACK pendant PLAY | Retour au menu précédent (pas de Stop)
TRSP-04 | Revenir dans TRANSPORT, clic encodeur (Pause) | Indicateur PAUSE, message Stop (FC) envoyé, transport_resumable=true
TRSP-05 | Clic encodeur à nouveau depuis PAUSE | Message Continue (FB) envoyé (pas un nouveau Start)
TRSP-06 | Depuis PAUSE, clic simple BACK | STOP réel (le prochain Play enverra Start, pas Continue)
TRSP-07 | Maintenir BACK + clic encodeur | Message MMC Record Strobe envoyé (SysEx F0 7F 7F 06 06 F7)
TRSP-08 | Maintenir BACK + tourner à droite / à gauche | MMC Fast Forward / Rewind envoyés respectivement
TRSP-09 | Rester sur l'écran TRANSPORT et vérifier le long-appui BACK global (retour logo) | Le geste global BACK→logo (1s) est désactivé sur cet écran, pour ne pas interrompre les gestes chordés
TRSP-10 | Piloter Play/Pause/Stop/Record/FF/RW depuis l'onglet SYNC de l'éditeur web | Mêmes effets que les gestes physiques, cohérence affichée entre OLED et éditeur web

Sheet: 6-Presets
ID | Procédure | Résultat attendu | Résultat | Commentaire
PRST-01 | Configurer un routage (MATRICE + FLUX + SYNC), Sauver sur preset 5 | Fichier /PRESETS/PRST05.DAT créé/mis à jour sur la carte SD
PRST-02 | Charger un autre preset puis recharger le preset 5 | Routage, flux et réglage SYNC restaurés à l'identique
PRST-03 | Redémarrer le miniMoc (coupure d'alimentation) | Le dernier preset actif (EEPROM) est rechargé automatiquement au boot
PRST-04 | Charger chacun des 8 presets d'usine (VIDE, DIAGONALE, MERGE, DISPATCH, TOTAL, SPLIT, USB>TRS, TRS>USB) | Chaque preset produit le comportement décrit dans le guide utilisateur
PRST-05 | Charger un preset legacy v1 (si disponible) | Migration automatique vers v3 sans perte (route_matrix legacy → basic_matrix déduite)
PRST-06 | Sauver/charger un preset via l'éditeur web | Comportement identique à l'écran OLED, astérisque * affiché en cas de modif non sauvée
PRST-07 | Tester la limite haute (preset 32) | Sauvegarde/chargement fonctionne sans erreur

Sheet: 7-HostConfig
ID | Procédure | Résultat attendu | Résultat | Commentaire
HOST-01 | Mode AUTO, brancher MiniLab en premier puis OP-1 en second | MiniLab → port logique C (+7 en miroir de slot), OP-1 second device → assigné au slot suivant (D+8)
HOST-02 | Mode AUTO, débrancher/rebrancher les deux appareils dans l'ordre inverse | L'assignation change en fonction du nouvel ordre de branchement (comportement FIFO documenté)
HOST-03 | Passer en mode MANUEL depuis SYSTEM → HOST CONFIG | Listes déroulantes activées, assigner explicitement le slot de MiniLab → C et le slot d'OP-1 → 7
HOST-04 | Avec le mapping manuel de HOST-03, débrancher/rebrancher MiniLab et OP-1 en même temps, en désordre | Chaque appareil retrouve son port logique via VID:PID, indépendamment de l'ordre physique de branchement
HOST-05 | Éteindre/rallumer le miniMoc avec le mapping MANUEL déjà configuré | Mapping conservé après redémarrage (persistance EEPROM adresse 2)
HOST-06 | Configurer HOST CONFIG depuis l'éditeur web (onglet HOST CONFIG) | Résultat identique à la configuration via écran OLED
HOST-07 | Brancher un 3e appareil USB Host sur le port D ou E libre (branchement à chaud) | Le nouvel appareil est détecté sans reboot ; SYSTEM → INFO le liste
HOST-08 | Provoquer un problème de reconnaissance (débrancher pendant l'activité) puis lancer USB LINK | Re-détection des appareils en ~2,5 s sans reboot complet
HOST-09 | Lancer USB RESET | Redémarrage complet du Teensy, tous les appareils USB Host se ré-énumèrent proprement

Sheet: 8-Monitor
ID | Procédure | Résultat attendu | Résultat | Commentaire
MON-01 | Entrer dans MONITOR (page VU-mètres), jouer sur chacune des 3 entrées (A, B, C) | Chaque barre d'entrée s'allume à réception, avec fondu ~500 ms, indépendamment du routage actif
MON-02 | Router A→1 (MATRICE) et jouer sur A | Barre d'entrée A ET barre de sortie 1 (Typhon) s'animent
MON-03 | Tourner l'encodeur vers la droite pour passer à la page BPM, SYNC = A (TRS) actif avec Clock envoyé | Tempo du maître affiché en grand, arrondi à l'entier le plus proche ; source maître rappelée en haut
MON-04 | Couper la source Clock plus de 2 secondes | Écran affiche NO CLOCK
MON-05 | Régler SYSTEM → BPM REFRESH sur 5000 ms, changer le tempo pendant l'affichage de la page BPM | L'affichage ne se met à jour qu'après ~5 s, sauf clic encodeur qui force une actualisation immédiate
MON-06 | Régler BPM REFRESH sur MANUEL | Affichage jamais rafraîchi automatiquement ; seul le clic encodeur actualise
MON-07 | Vérifier le clignotement de la LED embarquée pendant la lecture SYNC=MINIMOC | LED clignote à chaque temps (toutes les 24 ticks), indépendamment de l'écran affiché
MON-08 | Retourner à l'écran d'accueil après consultation MONITOR | Limiter le temps sur MONITOR en usage à forte densité MIDI pour éviter le jitter dû au refresh I²C (~20 ms)

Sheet: 9-System
ID | Procédure | Résultat attendu | Résultat | Commentaire
SYS-01 | SYSTEM → INFO | Stats carte SD affichées + liste des devices USB physiques branchés (MiniLab, OP-1)
SYS-02 | SYSTEM → CONTRASTE, faire varier de 16 à 255 | Luminosité OLED change visiblement sur toute la plage
SYS-03 | SYSTEM → USB LINK | Polling 2,5 s, appareils USB non reconnus forcés à se ré-énumérer, sans reboot
SYS-04 | SYSTEM → USB RESET | Reboot complet du Teensy (équivalent power-cycle), retour au logo puis restauration preset/config
SYS-05 | SYSTEM → BPM REFRESH, parcourir toutes les options (250/500/1000/2000/5000/MANUEL) | Chaque valeur est sélectionnable et persistée en EEPROM (adresse 36)
SYS-06 | Retirer la carte SD puis consulter SYSTEM → INFO | Message d'absence de carte cohérent, pas de blocage du firmware

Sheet: 10-SmartMirror
ID | Procédure | Résultat attendu | Résultat | Commentaire
MIRROR-01 | Brancher le miniMoc en USB sur le PC, ouvrir Ableton Live | Le miniMoc apparaît comme périphérique MIDI multi-port (15 câbles virtuels), sans installation de driver
MIRROR-02 | Dans Ableton, armer une piste sur le câble correspondant à l'entrée A, jouer sur Novation SL MK2 | La note est reçue en temps réel dans Ableton (câble 1 = entrée physique A)
MIRROR-03 | Router A→1 (MATRICE), armer dans Ableton le câble correspondant à la sortie 1 | Ableton reçoit également le miroir de ce qui sort vers Dreadbox Typhon (câbles 6-11 = sorties 1–6)
MIRROR-04 | Jouer sur MiniLab (entrée C, USB Host) avec Ableton armé sur le câble 3 (entrées USB Host C/D/E) | Réception confirmée dans Ableton indépendamment du routage
MIRROR-05 | Envoyer du MIDI depuis Ableton sur le câble miroir de sortie 7 (OP-1) | Le message ressort physiquement sur OP-1 comme si envoyé directement par le miniMoc
MIRROR-06 | Débrancher le PC en cours d'utilisation | Le miniMoc continue de fonctionner en autonome (Smart Mirror non requis pour le fonctionnement standalone)
MIRROR-07 | Rebrancher le PC | Les mêmes ports réapparaissent dans Ableton avec les mêmes numéros de câble
MIRROR-08 | Test croisé SYNC-03/04 avec Ableton comme source de Clock via le câble miroir A | Confirme le comportement TRS vs USB/PC documenté en section SYNC

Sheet: 11-RecordSD
ID | Procédure | Résultat attendu | Résultat | Commentaire
REC-01 | Jouer sur plusieurs entrées avec un routage actif pendant quelques minutes | Fichier(s) /REC/RECnnn.DAT créé(s)/mis à jour sur la carte SD
REC-02 | Remplir jusqu'à REC099 puis continuer à jouer | REC001 est écrasé (ring buffer confirmé)
REC-03 | Brancher le miniMoc en USB sous Windows, vérifier qu'il apparaît en disque amovible | Fichiers /REC/*.DAT accessibles en copie
REC-04 | Charger un .dat dans l'éditeur web, onglet DAT → MIDI | Événements affichés dans un tableau (horodatage, source, destination, type, canal)
REC-05 | Configurer l'export : diviser par sortie physique, BPM 120, PPQ 960, cocher les pistes | Fichier .mid téléchargé, lisible dans un lecteur MIDI standard, tempo et résolution respectés
REC-06 | Répéter REC-05 en divisant par source d'entrée plutôt que sortie | Pistes réparties différemment dans le fichier exporté, conformément au choix

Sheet: 12-Weblink
ID | Procédure | Résultat attendu | Résultat | Commentaire
WEB-01 | Ouvrir weblink/index.html dans Chrome/Edge, brancher le miniMoc en USB | Menu déroulant « Port MIDI » liste le miniMoc
WEB-02 | Sélectionner le port miniMoc | Point de statut passe au vert (Connecté), badge de version firmware affiché à côté du logo
WEB-03 | Ouvrir avec un navigateur non-Chromium (Firefox) | Connexion impossible (Web MIDI API non supportée) — comportement attendu, à documenter
WEB-04 | Tester chaque onglet (SYNC, MATRICE, FLUX, HOST CONFIG, FIRMWARE, DAT→MIDI) avec la config matérielle en place | Chaque onglet reflète et modifie l'état réel du miniMoc en temps réel
WEB-05 | Modifier une cellule MATRICE depuis le navigateur, vérifier sur l'écran OLED | Changement appliqué immédiatement et visible sur les deux interfaces
WEB-06 | Onglet FIRMWARE → sélectionner une version depuis « Firmwares du serveur » | Fichier .hex téléchargé automatiquement depuis le serveur
WEB-07 | Lancer la mise à jour firmware (⬆), choisir le port série dans le sélecteur navigateur | Barre de progression, confirmation, redémarrage automatique du miniMoc avec le nouveau firmware actif
WEB-08 | Vérifier le comportement si le firmware connecté est plus ancien que l'éditeur web | Bandeau d'avertissement affiché avec lien vers une version compatible du configurateur
WEB-09 | Onglet FIRMWARE → « Fichier local », glisser un .hex compilé manuellement (Arduino IDE) | Même flux de mise à jour que WEB-06/07, avec le fichier local
WEB-10 | Brancher/débrancher le miniMoc pendant que l'éditeur web est ouvert | Le menu déroulant Port MIDI reflète la (dé)connexion sans crash de la page

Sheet: 13-Robustesse
ID | Procédure | Résultat attendu | Résultat | Commentaire
ROB-01 | Couper l'alimentation brutalement pendant une écriture SD (sauvegarde preset ou enregistrement) | Redémarrage propre, pas de corruption bloquante de la carte SD (au pire perte du dernier événement)
ROB-02 | Enchaîner rapidement de nombreux changements MATRICE/FLUX/SYNC via l'éditeur web | Pas de blocage ni désynchronisation entre firmware et éditeur web
ROB-03 | Saturer une sortie TRS avec un flux dense (ex. pitch bend continu sur SL MK2) pendant que SYNC=MINIMOC | Le Clock interne (IntervalTimer/ISR) reste stable, pas de dérive tempo malgré la charge UART
ROB-04 | Saturer une sortie USB Host (OP-1) de la même façon | internal_clock_flush_usb() absorbe le flag en best-effort ; pas de blocage prolongé du Clock USB Host
ROB-05 | Naviguer dans tous les menus OLED pendant qu'un Clock externe rapide (200+ BPM) est actif sur une entrée TRS | Pas de perte de synchro DIN (l'ISR UART préempte l'affichage OLED bloquant ~8ms)
ROB-06 | Débrancher un appareil USB Host en pleine transmission MIDI (ex. MiniLab pendant une note tenue) | Pas de note bloquée en stuck note sur les sorties routées ; récupération propre après USB LINK/RESET

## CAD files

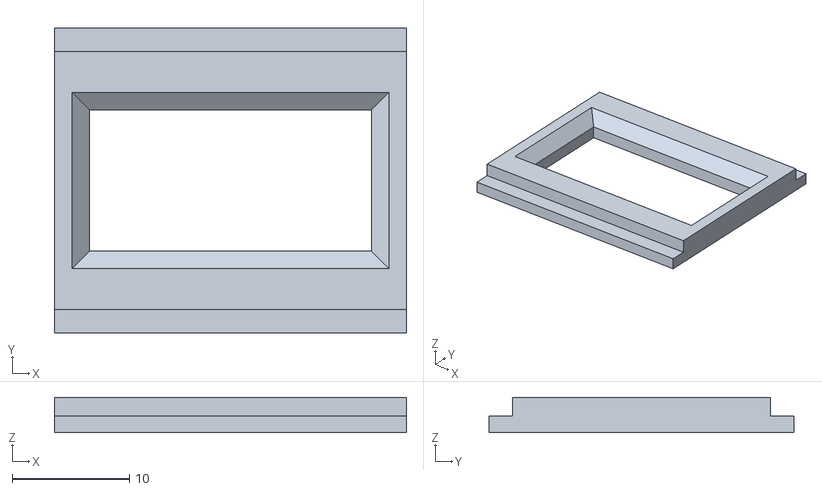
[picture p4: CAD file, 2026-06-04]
bezel/bezel.stl
30.0 x 26.0 x 3.00

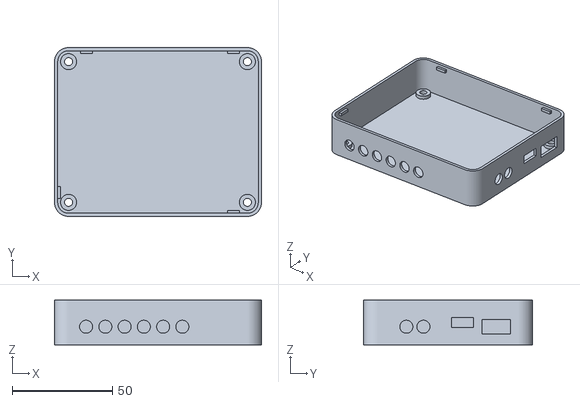
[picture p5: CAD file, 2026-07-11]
boitier/boitier.stl
103.0 x 84.0 x 22.2

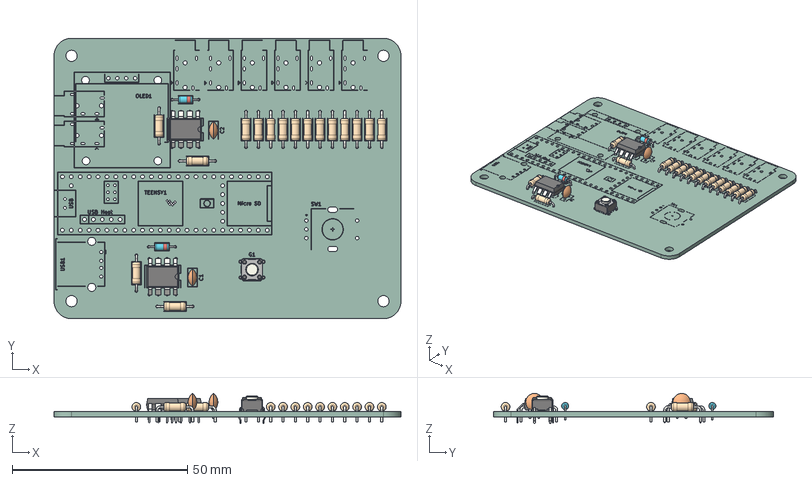
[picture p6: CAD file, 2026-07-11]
hardware/dessous/MIDISHIELD.step
99.0 x 80.0 x 8.60 mm
DIP-8_W10.16mm x 2
R_Axial_DIN0207_L6.3mm_D2.5mm_P10.16mm_Horizontal x 16
C_Disc_D5.0mm_W2.5mm_P2.50mm x 2
D_DO-35_SOD27_P7.62mm_Horizontal x 2
SW_TH_Tactile_Omron_B3F-100x
MiniMoc_bottom_silkscreen
MiniMoc_bottom_PCB

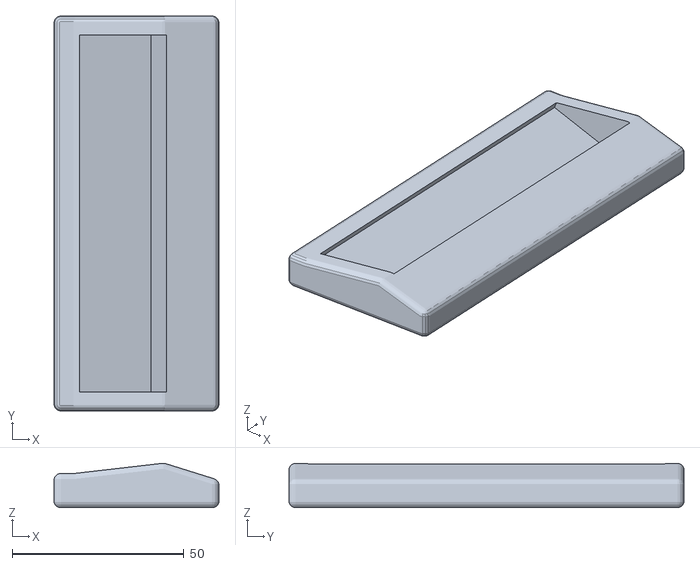
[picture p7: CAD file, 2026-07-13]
socle/socle.stl
48.0 x 114.9 x 12.9

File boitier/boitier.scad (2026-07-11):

// ============================================================
//  MiniMoc — BOÎTIER FUSIONNÉ (fond + anneau en une pièce)
//  ------------------------------------------------------------
//  Ce fichier NE MODIFIE PAS ta géométrie. Il contient tes deux
//  pièces telles quelles (l'anneau a juste ses noms préfixés
//  "a_" pour éviter les conflits avec le fond), puis les
//  assemble :
//    - fond() à sa place
//    - anneau retourné 180° autour de Y, recalé en X, posé à
//      Z = 2.4 mm (sur la plaque du fond)
//
//  Pour exporter : F6 puis Exporter STL.
// ============================================================

$fn = 64;

// ---------- PIÈCE A : LE FOND (inchangé) --------------------
// ============================================================
//  MiniMoc — Boîtier imprimé en 3D
//  PIÈCE 1/2 : LE FOND (plaque inférieure)
//  ------------------------------------------------------------
//  Repère : coin inférieur-gauche du PCB = origine (0,0),
//  comme dans KiCad. Cotes en millimètres.
//
//  Cotes extraites du PCB MiniMoc v0.2 :
//    - Contour des cartes ......... 99 x 80 mm, coins R5
//    - 4 trous M3 aux coins ....... (5,5) (94,5) (5,75) (94,75)
//
//  IMPORTANT : le fond et l'anneau partagent la MÊME empreinte
//  extérieure (PCB + jeu + murs). Les deux dépassent donc
//  légèrement du PCB, du même montant, pour coïncider bord à
//  bord. Le PCB, lui, reste à 99 x 80 à l'intérieur.
//
//  OpenSCAD : F5 = aperçu, F6 = rendu, puis
//  Fichier > Exporter > Exporter en STL.
// ============================================================


// ---------- PARAMÈTRES À AJUSTER ----------------------------

pcb_l        = 99;    // longueur du PCB (axe X)
pcb_w        = 80;    // largeur du PCB  (axe Y)
coin_r       = 5;     // rayon des coins du PCB (R5)

// -- Murs & jeu : CES DEUX VALEURS définissent l'empreinte --
//    extérieure, partagée avec l'anneau. Garde-les identiques
//    dans les deux fichiers.
mur_ep       = 1.6;   // épaisseur des murs de l'anneau
jeu_pcb      = 0.4;   // jeu entre le PCB et l'intérieur des murs

// => empreinte extérieure de la coque (calculée, ne pas éditer)
ext_l        = pcb_l + 2*(jeu_pcb + mur_ep);   // ~103.0
ext_w        = pcb_w + 2*(jeu_pcb + mur_ep);   // ~84.0
ext_coin_r   = coin_r + jeu_pcb + mur_ep;      // arrondi extérieur

fond_ep      = 2.4;   // épaisseur de la plaque de fond

// -- Colonnes de vis aux 4 coins (positions = repère PCB) --
trou_x1      = 5;
trou_x2      = 94;
trou_y1      = 5;
trou_y2      = 75;

colonne_d    = 8;     // diamètre des bossages de vis
colonne_h    = 2;     // hauteur des bossages (surélève le PCB,
                      //  dégage les soudures du dessous)

// -- Type de fixation --
//   "taraude" = vis M3 taraude le plastique (Ø2.7)
//   "insert"  = trou pour insert thermofusible M3 (Ø4.0)
fixation     = "insert";

trou_d_taraude = 2.9;
trou_d_insert  = 4.0;

// -- Lamage tête de vis sous la plaque --
// -- Lamage tête de vis sous le fond (vis Allen tête bombée M3) --
// La vis monte PAR LE DESSOUS ; sa tête bombée se loge dans ce
// logement cylindrique creusé sous le fond pour ne pas dépasser.
lamage       = true;
lamage_d     = 6.2;   // Ø tête bombée M3 (~5.7) + jeu impression
lamage_h     = 2.0;   // profondeur (tête bombée M3 ~1.65 de haut)

$fn = 48;


// ---------- CONSTRUCTION ------------------------------------

// Profil arrondi générique (l, w, r) centré sur le repère PCB.
// Le décalage place le contour extérieur autour du PCB.
module profil(l, w, r, ox, oy) {
    translate([ox, oy, 0])
    hull() {
        translate([r,       r    ]) circle(r);
        translate([l - r,   r    ]) circle(r);
        translate([r,       w - r]) circle(r);
        translate([l - r,   w - r]) circle(r);
    }
}

// Décalage du contour extérieur par rapport à l'origine PCB
off = -(jeu_pcb + mur_ep);

trou_d = (fixation == "insert") ? trou_d_insert : trou_d_taraude;

positions = [
    [trou_x1, trou_y1], [trou_x2, trou_y1],
    [trou_x1, trou_y2], [trou_x2, trou_y2]
];

module fond() {
    difference() {
        union() {
            // plaque à l'empreinte EXTÉRIEURE (partagée avec l'anneau)
            linear_extrude(fond_ep)
                profil(ext_l, ext_w, ext_coin_r, off, off);
            // colonnes de vis
            for (p = positions)
                translate([p[0], p[1], 0])
                    cylinder(d = colonne_d, h = fond_ep + colonne_h);
        }
        // perçage des trous de vis
        for (p = positions)
            translate([p[0], p[1], -1])
                cylinder(d = trou_d, h = fond_ep + colonne_h + 2);
        // lamage optionnel
        if (lamage)
            for (p = positions)
                translate([p[0], p[1], -0.01])
                    cylinder(d = lamage_d, h = lamage_h);
    }
}



// ---------- PIÈCE B : L'ANNEAU (noms préfixés a_, inchangé) --
// ============================================================
//  MiniMoc — Boîtier imprimé en 3D
//  PIÈCE 2/2 : L'ANNEAU (cadre + 2 épaulements + découpes)
//  ------------------------------------------------------------
//  Repère KiCad : coin HAUT-gauche du PCB = origine (0,0),
//  axe X vers la droite, axe Y vers le BAS. Cotes en mm.
//
//  STRUCTURE (coupe en "H" couché) :
//    - débord extérieur = ton liseré autour des PCB
//    - épaulement BAS  : repose SUR le PCB du bas
//    - ouverture centrale : hauteur = entretoises (11 mm)
//    - épaulement HAUT : reçoit le PCB du haut
//
//  FIXATION : 4 trous ronds laissent passer les entretoises
//  hexagonales aux coins -> bloquent l'a_anneau en X/Y. Les deux
//  épaulements + les PCB le bloquent en Z.
//
//  Murs (repère) :
//    - bord y=0 -> FACE AVANT : 6 jacks de sortie
//    - bord x=0 -> FACE GAUCHE : 2 entrées + USB-A + micro-USB Teensy
//
//  Positions connecteurs & entretoises : extraites du PCB. NE PAS toucher.
//  Cotes à confirmer = bloc MESURES.
//  OpenSCAD : F5 aperçu, F6 rendu, export STL.
// ============================================================


// réglages fins FJA
a_decaltrs=0;
a_agrandir_anneau= 5.6;



// ---------- DOIT CORRESPONDRE AU FICHIER DU FOND ------------
a_pcb_l        = 99;
a_pcb_w        = 80;
a_coin_r       = 5;
a_mur_ep       = 1.6;    // épaisseur du mur extérieur (liseré)
a_jeu_pcb      = 0.4;    // jeu pour que le PCB entre sans forcer

// empreinte extérieure (identique au fond)
a_ext_l        = a_pcb_l + 2*(a_jeu_pcb + a_mur_ep);
a_ext_w        = a_pcb_w + 2*(a_jeu_pcb + a_mur_ep);
a_ext_coin_r   = a_coin_r + a_jeu_pcb + a_mur_ep;
a_off          = -(a_jeu_pcb + a_mur_ep);


// ---------- MESURES (confirmées avec toi) -------------------
a_entretoise_h = 11.0+a_agrandir_anneau;   // hauteur des entretoises = ouverture centrale
a_pcb_ep       = 1.6;    // épaisseur de tes PCB (feuillures)

// --- PATINS D'APPUI (au lieu d'un rebord continu) ---
// Chaque a_patin = petit plot sur lequel un PCB vient reposer.
// Format : [x, y, largeur, profondeur]  (x,y = centre, repère PCB)
// ÉDITE CETTE LISTE LIBREMENT : ajoute/déplace/supprime des lignes.
// Pré-rempli avec les 4 coins (zones dégagées). Décale-les vers
// l'intérieur si un composant gêne, réduis largeur/profondeur, etc.
//


// Attntion BAS = ceux du haut et HAUT = plus utilisés
// Patins du BAS (sous le PCB du bas — ATTENTION aux composants) :
a_patins_bas = [
    [12, 0, 6, 2],   // coin bas-gauche
    [99, 10, 2, 6],   // coin bas-droite
    [12, 80, 6, 2],   // coin haut-gauche
    [85, 80, 6, 2],   // coin haut-droite
];
// Patins du HAUT (sous le PCB du haut — carte nue, peu de contraintes) :
a_patins_haut = [
    [12, 2, 6, 6],
    [98, 10, 6, 6],
    [12, 78, 6, 6],
    [85, 78, 6, 6],
];

// hauteur totale de l'a_anneau = PCB bas + entretoises + PCB haut
a_anneau_h     = a_pcb_ep + a_entretoise_h + a_pcb_ep;   // = 14.2

// -- Entretoises hexagonales (passage aux 4 coins) --
a_entre_plats  = 4.0;    // dimension entre plats mesurée (4 mm)
a_ent_jeu      = 0.4;    // jeu d'impression
// largeur max de l'hexagone (pointe à pointe) = a_entre_plats / cos(30)
a_ent_trou_d   = a_entre_plats / cos(30) + a_ent_jeu;   // ~5.02


// ---------- MESURES connecteurs (au pied à coulisse) --------
a_jack_axe_z   = 6.0+a_agrandir_anneau;    // hauteur axe jack au-dessus du PCB bas
a_jack_trou_d  = 6.5;    // Ø trou fût du jack + jeu

a_usb_larg     = 14.0;   // ouverture USB-A
a_usb_haut     = 7.0;
a_usb_axe_z    = 6.0+a_agrandir_anneau;

a_tusb_larg    = 11.0;   // ouverture micro-USB Teensy (large pour la fiche)
a_tusb_haut    = 5.0;
a_tusb_axe_z   = 4.0+a_agrandir_anneau;

// Hauteur de référence : le PCB du bas est posé à z = a_pcb_ep
// (l'épaulement bas fait a_pcb_ep de haut). Les connecteurs sont
// au-dessus du PCB bas, donc leur z = a_pcb_ep + axe_z.
a_pcb_bas_z    = a_pcb_ep;
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

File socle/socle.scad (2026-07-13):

// ============================================================
//  MiniMoc — SOCLE INCLINÉ (profil en CALE)
//  ------------------------------------------------------------
//  Le boîtier se pose DEBOUT dans une gorge inclinée, penché de
//  `angle_vert` degrés depuis la verticale.
//  Jacks 1-6 en haut, entrées A/B à gauche.
//
//  PROFIL EN CALE : fin à l'avant, épais à l'arrière.
//  Gorge asymétrique :
//    - lèvre AVANT basse   -> passe SOUS les têtes de vis du PCB
//    - dossier ARRIÈRE haut -> le boîtier s'y appuie en penchant
//
//  La géométrie est CALCULÉE pour qu'il reste toujours de la
//  matière devant, derrière et sous la gorge (pas de zone
//  fragile, pas de pièce coupée en deux).
// ============================================================


// ---------- PARAMÈTRES ---------------------------------------

angle_vert   = 20;    // inclinaison depuis la VERTICALE (°)

// -- Boîtier --
boitier_l    = 103;   // largeur reposant dans la gorge
boitier_ep   = 22.2;  // épaisseur du boîtier

// -- Gorge --
gorge_jeu    = 0.6;   // jeu d'insertion
gorge_prof   = 9;    // profondeur d'encastrement du boîtier
gorge_h_av   = 6.0;   // hauteur de la lèvre AVANT
                      //  GARDER SOUS 4 mm (vis à 4-5 mm du bord)
gorge_marge  = 6.0;   // débord latéral de chaque côté = épaisseur des
                      //  JOUES qui bloquent le boîtier latéralement
gorge_jeu_lat= 0.8;   // jeu latéral (le boîtier doit glisser sans forcer)

// -- Épaisseurs de matière (solidité) --
ep_sous      = 4.0;   // matière SOUS le fond de la gorge
ep_avant     = 6.0;   // matière DEVANT la gorge (la lèvre)
ep_arriere   = 16.0;  // matière DERRIÈRE la gorge (lest/dossier)
                      //  AUGMENTER si le socle bascule en arrière

dossier_h    = 8;    // hauteur du dossier arrière

// -- Arrondis (confort + finition) --
arrondi_r    = 2.0;   // rayon d'arrondi des arêtes EXTÉRIEURES
arrondi_fn   = 16;    // finesse de l'arrondi (16 = bon compromis).
                      //  Monte à 24-32 pour l'export final si tu veux
                      //  plus lisse ; baisse à 8-12 si le rendu F6
                      //  est trop lent pendant que tu travailles.
                      //  (la gorge, elle, reste à angles VIFS pour
                      //   que le boîtier s'y loge bien)

$fn = 48;


// ---------- CALCULS (géométrie garantie cohérente) -----------

socle_l  = boitier_l + 2*gorge_marge;   // largeur totale
gorge_w  = boitier_ep + gorge_jeu;      // largeur de la fente
dx       = gorge_prof * tan(angle_vert);// décalage dû à l'inclinaison

// Bord AVANT de la gorge, mesuré à son point le plus avancé
// (c'est-à-dire au FOND de la gorge, car elle penche vers l'avant).
// On place ce point à ep_avant du bord avant du socle.
// => position X de l'axe de la gorge, au niveau du DESSUS :
gx       = ep_avant + gorge_w/2 + dx;

// Hauteur du sommet de la gorge (= hauteur utile du socle à cet endroit)
h_gorge  = ep_sous + gorge_prof;

// Bord ARRIÈRE de la gorge au sommet + matière derrière
prof_tot = gx + gorge_w/2 + ep_arriere;

// Hauteur de la lèvre avant (sommet)
h_levre  = ep_sous + gorge_h_av;


// ---------- CONSTRUCTION -------------------------------------

// Silhouette : cale (fin devant, épais derrière)
module silhouette_brute() {
    polygon([
        [0,                    0],           // avant-bas
        [prof_tot,             0],           // arrière-bas
        [prof_tot,             dossier_h],   // arrière-haut
        [gx + gorge_w/2,       h_gorge],     // sommet, derrière la gorge
        [gx - gorge_w/2 - dx,  h_levre],     // sommet de la lèvre avant
        [0,                    h_levre]      // avant-haut
    ]);
}

// Silhouette avec les angles ARRONDIS (offset -r puis +r)
module silhouette() {
    if (arrondi_r > 0)
        offset(r =  arrondi_r)
            offset(r = -arrondi_r)
                silhouette_brute();
    else
        silhouette_brute();
}

// Gorge : fente inclinée, borgne (s'arrête à ep_sous du fond)
module gorge() {
    translate([gx, h_gorge])
        rotate(-angle_vert)
            translate([-gorge_w/2, -gorge_prof])
                square([gorge_w, gorge_prof + 30]);
}

module profil_socle() {
    difference() {
        silhouette();
        gorge();
    }
}

// Le socle : bloc plein extrudé sur toute la largeur, dans lequel
// on creuse la gorge UNIQUEMENT sur la longueur du boîtier.
// Il reste donc une JOUE de `gorge_marge` de chaque côté, qui
// empêche le boîtier de coulisser latéralement.
module socle() {
    gorge_len = boitier_l + gorge_jeu_lat;
    gorge_y0  = (socle_l - gorge_len) / 2;

    difference() {
        // ---- BLOC PLEIN, arêtes extérieures arrondies ----
        // On arrondit les arêtes verticales (coins vus de dessus) en
        // rétrécissant puis re-gonflant le bloc avec minkowski d'un
        // cylindre : cela adoucit tous les bords verticaux.
        minkowski() {
            // bloc réduit du rayon d'arrondi dans TOUTES les directions.
            // IMPORTANT : on le décale de +arrondi_r en Y pour que le
            // regonflement par la sphère retombe SYMÉTRIQUEMENT
            // (sinon le socle se décale d'un côté).
            translate([0, arrondi_r, 0])
                rotate([90, 0, 0])
                    translate([0, 0, -(socle_l - 2*arrondi_r)])
                        linear_extrude(socle_l - 2*arrondi_r)
                            offset(delta = -arrondi_r) silhouette();
            // la "brosse" : une SPHÈRE -> arrondit TOUTES les arêtes,
            // y compris celles des faces latérales gauche et droite.
            sphere(r = arrondi_r, $fn = arrondi_fn);
        }

        // ---- LA GORGE : creusée APRÈS -> angles VIFS ----
        translate([0, gorge_y0, 0])
            rotate([90, 0, 0])
                translate([0, 0, -gorge_len])
                    linear_extrude(gorge_len)
                        gorge();
    }
}

socle();

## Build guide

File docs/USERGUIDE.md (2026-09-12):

# Mode d'emploi — miniMoc

> Version 0.5.2

---

## Sommaire

1. [Présentation](#1-présentation)
2. [Matériel — ce qu'il y a dans la boîte](#2-matériel)
3. [Connexions MIDI](#3-connexions-midi)
4. [Interface physique — écran et encodeur](#4-interface-physique)
5. [Smart Mirror — connexion à un DAW](#5-smart-mirror)
6. [Routage basique (MATRICE)](#6-routage-basique-matrice)
7. [Routage avancé (FLUX)](#7-routage-avancé-flux)
8. [Synchronisation MIDI Clock (SYNC)](#8-synchronisation-midi-clock-sync)
9. [Gestion des presets](#9-gestion-des-presets)
10. [Appareils USB (HOST CONFIG)](#10-appareils-usb-host-config)
11. [Enregistrement MIDI sur carte SD](#11-enregistrement-midi-sur-carte-sd)
12. [Éditeur web (weblink)](#12-éditeur-web-weblink)
13. [Mise à jour du firmware](#13-mise-à-jour-du-firmware)
14. [Référence des menus OLED](#14-référence-des-menus-oled)
15. [Dépannage](#15-dépannage)

---

## 1. Présentation

Le **miniMoc** est un routeur MIDI hardware fait main, conçu pour fonctionner **sans ordinateur**. Il permet de relier des synthétiseurs, boîtes à rythmes et autres instruments MIDI entre eux avec une grande flexibilité.

**Fonctionnalités principales :**

- 2 entrées MIDI physiques TRS type A (a, b) + 3 entrées USB Host (c, d, e)
- 6 sorties MIDI physiques TRS (1–6) + 3 sorties USB Host (7–9)
- Routage basique par matrice 5×9 (un bouton = une connexion)
- Routage avancé par **Flux** : filtrage par canal, remapping de canal
- **Smart Mirror** : les ports physiques apparaissent automatiquement dans votre DAW quand vous branchez un PC — sans driver, sans configuration
- Synchronisation MIDI Clock : choix d'un maître parmi 10 sources externes (TRS/USB Host physique ou câble USB/PC, au choix) **ou l'horloge interne du miniMoc lui-même**, diffusion sur toutes les sorties
- Menu **TRANSPORT** : réglage du tempo de l'horloge interne, Play/Pause/Stop, et pilotage d'un enregistreur externe (MMC Record/Avance/Rewind)
- **Transformateurs de Flux** : transposition, harmonisation, réharmonisation sur une progression d'accords
- **Générateurs** internes : LFO, séquenceur euclidien, motifs de batterie pré-enregistrés
- 32 presets utilisateur + 8 presets d'usine, stockés sur carte SD
- Mise à jour firmware OTA via l'éditeur web

> L'enregistrement MIDI continu sur carte SD (capture automatique des jams) fait partie
> du projet mais est **désactivé par défaut et reporté après la V1** — voir
> [§11](#11-enregistrement-midi-sur-carte-sd).

---

## 2. Matériel

| Composant | Description |
|---|---|
| Teensy 4.1 | Microcontrôleur principal (ARM Cortex-M7 @ 600 MHz) |
| Écran OLED | 128×64 px, interface I²C |
| Encodeur rotatif | Navigation dans les menus |
| Bouton SELECT | Valider une sélection |
| Bouton BACK | Revenir en arrière / annuler |
| Carte SD | Presets et enregistrements (FAT32) |
| Ports TRS | Connecteurs 3,5 mm Type A (compatibles MIDI TRS et adaptateurs 5-broches DIN) |

---

## 3. Connexions MIDI

### Entrées

| Port | Type | Description |
|---|---|---|
| **A** | TRS 3,5 mm | Entrée physique — câble TRS ou adaptateur DIN |
| **B** | TRS 3,5 mm | Entrée physique — câble TRS ou adaptateur DIN |
| **C** | USB Host | Appareils USB MIDI branchés directement sur le miniMoc |
| **D** | USB Host | (idem) |
| **E** | USB Host | (idem) |

### Sorties

| Port | Type | Description |
|---|---|---|
| **1–6** | TRS 3,5 mm | Sorties physiques — câble TRS ou adaptateur DIN |
| **7–9** | USB Host | Sorties vers les appareils USB MIDI connectés |

### Connexion PC / DAW

Branchez le miniMoc sur votre ordinateur via USB. Il apparaît immédiatement comme un **périphérique MIDI USB multi-port** (15 câbles virtuels). Aucun driver n'est nécessaire.

> **Astuce** : débranchez le PC, le miniMoc continue de fonctionner seul. Rebranchez, et les mêmes ports réapparaissent dans votre DAW.

---

## 4. Interface physique

L'interface est composée de :

- **Encodeur rotatif** : tourner pour naviguer dans les listes / changer une valeur
- **Bouton SELECT** (appuyer sur l'encodeur) : valider / entrer dans un sous-menu
- **Bouton BACK** : revenir au niveau précédent

### Navigation dans le carousel principal

Au démarrage, l'écran affiche un **carousel** de 6 sections :

```
◀ PRESET   SYNC   ROUTAGE   MONITOR   SYSTEME   TRANSPORT ▶
```

Tournez l'encodeur pour changer de section. Appuyez sur SELECT pour entrer.

---

## 5. Smart Mirror

Quand le miniMoc est branché à un ordinateur :

- Chaque message reçu sur un port physique est **simultanément transmis** sur le câble USB correspondant → votre DAW peut enregistrer directement.
- Chaque message envoyé vers une sortie physique est aussi **reflété** sur le câble USB correspondant → monitoring complet depuis le DAW.

**Câbles virtuels USB (numérotation interne) :**

| Câble | Correspondance |
|---|---|
| 1–2 | Entrées physiques A, B |
| 3–5 | Entrées USB Host C, D, E |
| 6–11 | Sorties physiques 1–6 |
| 12–14 | Sorties USB Host 7–9 |
| 0 | Éditeur web (SysEx) |

---

## 6. Routage basique (MATRICE)

La **MATRICE** est une grille 5×9 : chaque cellule active ou désactive la connexion entre une entrée et une sortie.

### Via l'écran OLED

1. Section **ROUTAGE** → **MATRICE**
2. L'écran affiche une grille. La ligne = entrée (A–E), la colonne = sortie (1–9).
3. Naviguez avec l'encodeur, appuyez sur SELECT pour activer/désactiver une cellule.

### Via l'éditeur web

1. Onglet **MATRICE**
2. Cliquez sur une cellule pour l'activer (colorée) ou la désactiver.
3. Les changements sont envoyés en temps réel.

### Exemple : relier le synthé en entrée A aux sorties 1 et 2

Activez les cellules [A, 1] et [A, 2] dans la matrice. Toutes les notes et messages du synthé sont maintenant envoyés simultanément aux deux destinations, **sur tous les canaux MIDI**.

> Pour un routage par canal ou avec remapping, utilisez les **Flux** (section 7).

### Presets d'usine

| Preset | Description |
|---|---|
| VIDE | Aucune connexion |
| DIAGONALE | A→1, B→2, C→3, D→4, E→5 |
| MERGE | Toutes les entrées → toutes les sorties |
| DISPATCH | Chaque entrée → sa sortie + une sortie commune |
| TOTAL | Interconnexion maximale |
| SPLIT | Séparation stéréo / double mono |
| USB>TRS | Entrées USB C/D/E → sorties TRS 1–6 |
| TRS>USB | Entrées TRS A/B → sorties USB 7–9 |

---

## 7. Routage avancé (FLUX)

Les **Flux** permettent un routage précis : vous choisissez **quels canaux MIDI** entrent et **sur quel canal** ils ressortent.

Jusqu'à **16 flux simultanés** sont possibles.

### Créer un flux (éditeur web)

1. Onglet **FLUX** → bouton **+ Nouveau flux**
2. **Étape 1 – Entrées**
   - Cochez les ports d'entrée (A, B, C, D, E)
   - Pour chaque port, cliquez sur l'indicateur de canal :
     - **ALL** : tous les canaux MIDI passent
     - **ch×N** : cliquez pour ouvrir la grille et sélectionner les canaux 1–16 individuellement
3. **Étape 2 – Sorties**
   - Cochez les ports de sortie (1–9)
   - Pour chaque port, cliquez sur l'indicateur de canal :
     - **ALL** : le canal d'entrée est conservé
     - **ch×N** : forcer un canal de sortie fixe (remapping)
4. Cliquez **OK**

### Exemple : boîte à rythmes (entrée B, canal 10) → expandeur (sortie 3, canal 1)

- Entrée : B, canal 10 uniquement
- Sortie : 3, canal 1 (remapping)
- Résultat : seules les données MIDI canal 10 de B arrivent sur la sortie 3, converties en canal 1.

### Gérer les flux existants

- Chaque flux affiché montre un résumé : `F1 - A:1 → 1:5`
- Bouton **Éditer** : modifier le flux
- Bouton **✕** : supprimer le flux

> **Important** : les Flux et la Matrice sont **cumulatifs**. Un message peut être routé à la fois par la matrice (tous canaux) et par un flux (canal spécifique). Veillez à ne pas doubler le signal non voulu.

---

## 8. Synchronisation MIDI Clock (SYNC)

Le miniMoc peut prendre **une seule source** comme maître d'horloge et diffuser son Clock, Start, Stop, Continue sur **toutes les sorties actives** (physiques et USB Host), avec un miroir vers le PC (smartmirror) sur les câbles correspondants.

### Pourquoi chaque lettre a deux variantes

Chaque port A-E existe sous **deux formes distinctes** comme source d'horloge :

- **TRS / USB Host** : le signal reçu sur l'entrée physique elle-même (câble TRS pour A/B, appareil USB branché pour C/D/E).
- **USB/PC** : le signal envoyé par votre ordinateur (via le smartmirror) sur le câble USB miroir de ce même port.

Ce sont deux sources potentiellement différentes qui partagent la même lettre. Sans cette distinction, choisir « A » écouterait les deux en même temps — si un vrai clock TRS et le smartmirror envoient tous les deux du Clock sur le port A, les ticks se mélangent et le tempo devient instable. En choisissant explicitement **A (TRS)** ou **A (USB/PC)**, une seule des deux sources est réellement écoutée.

### Les 11 sources disponibles

| Source | Ce qu'elle écoute |
|---|---|
| **A (TRS)** / **B (TRS)** | Entrée physique TRS |
| **C (USB Host)** / **D (USB Host)** / **E (USB Host)** | Appareil USB branché directement sur le miniMoc |
| **A (USB/PC)** … **E (USB/PC)** | Câble USB miroir correspondant, piloté depuis votre ordinateur (smartmirror) |
| **MINIMOC** | Horloge interne du miniMoc — voir ci-dessous |
| **OFF** | Aucune horloge propagée |

### Configurer le maître

**Via l'écran OLED — section SYNC** :
- Tournez l'encodeur pour faire défiler la liste (11 sources + OFF)
- SELECT pour valider — le choix est sauvegardé immédiatement

**Via l'éditeur web — onglet SYNC** :
- Cliquez sur l'une des cases de la grille
- La source active est marquée d'un `*`
- Le réglage est envoyé et sauvegardé immédiatement

### Ce qui est transmis depuis le maître

- MIDI Clock (F8)
- Start (FA), Stop (FC), Continue (FB)
- Active Sensing (FE)
- System Reset (FF)

Les messages Real-Time des sources non sélectionnées sont **ignorés**, pour éviter les conflits d'horloge. Réglez **OFF** si vous ne souhaitez propager aucun clock.

### Horloge interne (MINIMOC)

Le miniMoc peut être son propre maître d'horloge, sans dépendre d'aucun appareil externe : sélectionnez **MINIMOC** dans la liste SYNC. Le tempo est généré en continu par une horloge matérielle dédiée du Teensy — il reste précis même quand l'écran est très sollicité (VU-mètre, navigation dans les menus). Réglez le tempo et pilotez la lecture depuis le menu **TRANSPORT** (voir ci-dessous) ou depuis l'onglet SYNC de l'éditeur web.

### Menu TRANSPORT

Accessible depuis le carousel principal, cet écran n'affiche que le **BPM en grand** et un indicateur **PLAY / PAUSE / STOP**.

| Geste | Action |
|---|---|
| Tourner l'encodeur | Régler le tempo (±1 BPM ; ±5 si vous tournez vite) |
| Clic encodeur | Play / Pause — premier départ = Start, reprise après pause = Continue (la lecture reprend, elle ne redémarre pas) |
| Clic simple sur BACK, en pause | STOP — arrête réellement l'horloge ; le Play suivant redémarrera depuis le début |
| Clic simple sur BACK, en lecture ou déjà stoppé | Retour au menu précédent |
| Maintenir BACK + clic encodeur | RECORD — commande un enregistreur/DAW externe (MMC) |
| Maintenir BACK + tourner à droite | AVANCE (MMC Fast Forward) |
| Maintenir BACK + tourner à gauche | REWIND (MMC Rewind) |

> Record/Avance/Rewind utilisent le protocole **MMC** (MIDI Machine Control), pensé pour piloter un enregistreur ou un DAW externe — c'est un protocole différent du Play/Pause/Stop "temps réel" qui pilote les appareils synchronisés sur le clock. Les deux peuvent être utilisés indépendamment.

Depuis l'éditeur web, l'onglet SYNC propose les mêmes contrôles : deux boutons **−/+** pour le tempo (appui maintenu = défilement continu) et une rangée de boutons ▶/⏸ ⏹ ⏺ ⏪ ⏩.

### Visualiser le BPM en temps réel

Depuis le carousel, entrez dans **MONITOR** puis tournez l'encodeur vers la droite pour passer à l'écran **BPM**.

- La source maître est rappelée en haut de l'écran.
- Le BPM du maître est affiché en grands chiffres, arrondi à l'entier le plus proche.
- La LED embarquée du miniMoc clignote à chaque temps (toutes les 24 ticks de Clock).
- Si aucun signal n'est reçu depuis plus de 2 secondes, l'écran affiche **NO CLOCK**.
- Tournez l'encodeur vers la gauche pour revenir à l'écran VU-mètre.

La fréquence d'actualisation de cette page se règle dans **SYSTEME → BPM REFRESH** (de 250ms à 5s, ou **MANUEL** pour ne jamais rafraîchir automatiquement). Quel que soit le réglage, un **clic sur l'encodeur** pendant que cette page est affichée force toujours une actualisation immédiate — pratique en mode MANUEL, ou pour vérifier le tempo à l'instant précis où vous le voulez.

> **Important** : l'écran MONITOR se rafraîchit en permanence (chaque rafraîchissement de l'affichage OLED bloque le bus I²C ~20 ms). Pour éviter tout jitter sur les sorties MIDI à forte densité de données, **revenez à l'écran d'accueil (la feuille du carousel) dès que vous n'avez plus besoin du moniteur**. Ceci ne concerne pas l'horloge MINIMOC : générée par un timer matériel dédié, elle reste précise même écran actif.

---

## 9. Gestion des presets

Le miniMoc dispose de **32 emplacements utilisateur** et **8 presets d'usine**.

Chaque preset contient :
- La matrice de routage basique
- Tous les flux définis
- Le réglage SYNC

### Charger un preset

**Via l'éditeur web** :
1. Cliquez **Charger** dans la barre du haut
2. Sélectionnez un preset d'usine ou un numéro 1–32
3. Cliquez **Charger preset N**

**Via l'écran OLED — section PRESET** :
1. Tournez l'encodeur pour sélectionner le numéro
2. SELECT pour charger

### Sauvegarder un preset

**Via l'éditeur web** :
1. Configurez votre routage
2. Cliquez **Sauver** dans la barre du haut
3. Choisissez un emplacement (1–32)
4. Cliquez **Sauver sur preset N**

**Via l'écran OLED — section PRESET** :
1. Allez sur **SAUVER**
2. Sélectionnez le numéro de destination
3. SELECT pour confirmer

### Indicateur de modification

Dans l'éditeur web, un astérisque `*` apparaît à côté du numéro de preset si des modifications non sauvegardées sont en cours.

### Persistance

- Les presets sont stockés sur la **carte SD** (`/PRESETS/PRST01.DAT` à `PRST32.DAT`).
- Le **preset actif** est mémorisé en EEPROM et rechargé automatiquement au démarrage.

---

## 10. Appareils USB (HOST CONFIG)

Le miniMoc peut connecter jusqu'à **3 appareils USB MIDI simultanément** en entrée (C, D, E) et 3 en sortie (7, 8, 9), via un hub USB interne.

### Mode AUTO (défaut)

- Les appareils sont assignés dans l'ordre de connexion.
- Premier branché = slot C/7, deuxième = D/8, troisième = E/9.
- À chaque déconnexion/reconnexion, l'ordre peut changer.
- Idéal pour des tests rapides.

### Mode MANUEL

- Chaque appareil est identifié par son VID:PID (identifiant fabricant/produit).
- L'appareil retrouve toujours le même port logique, quel que soit l'ordre de branchement.
- Idéal pour un live setup stable.

### Passer en mode MANUEL

**Via l'éditeur web — onglet HOST CONFIG** :
1. Cliquez le bouton **MANUEL**
2. Les listes déroulantes deviennent actives
3. Assignez chaque slot physique (D1–D6) à un port logique (C, D, E, 7, 8, 9)

**Via l'écran OLED — SYSTEME → HOST CONFIG** :
- Sélectionnez AUTO ou MANUEL
- Assignez les slots si en mode MANUEL

### En cas de problème de reconnaissance

Depuis **SYSTEME** :
- **USB LINK** : force une nouvelle détection des appareils (2,5 secondes de polling)
- **USB RESET** : redémarre complètement le Teensy

---

## 11. Enregistrement MIDI sur carte SD

> ⚠️ **Reporté après la V1.** Le moteur d'enregistrement continu (ring buffer → écriture
> SD, format `.DAT`) existe dans le firmware mais est **désactivé par défaut**
> (`SD_RECORDER_ENABLED`) : il n'y a pas encore de commande pour démarrer/arrêter un
> enregistrement à la volée, ni de fermeture propre du fichier en cours d'usage. En
> conséquence, l'onglet **DAT → MIDI** de l'éditeur web est également masqué tant que
> cette fonctionnalité n'est pas retravaillée. Le reste de cette section décrit le
> fonctionnement prévu, pour référence.

Une fois réactivé, le miniMoc enregistre automatiquement tous les messages MIDI routés sur la carte SD, dans `/REC/REC001.DAT` à `/REC099.DAT`.

- L'enregistrement est en **anneau** (ring buffer) : REC099 plein → REC001 écrasé
- Format propriétaire `.DAT` (10 octets/événement : horodatage, source, destination, type, canal, données)
- La conversion en fichier MIDI standard se fera via un onglet **DAT → MIDI** de l'éditeur web, réactivé en même temps que l'enregistrement.

---

## 12. Éditeur web (weblink)

L'éditeur web est une application accessible depuis un **navigateur Chrome ou Edge**.

### Prérequis

- Navigateur : **Google Chrome** ou **Microsoft Edge** (Chromium)
- Connexion : USB entre le miniMoc et l'ordinateur
- Protocole : le fichier doit être ouvert en HTTPS ou en `localhost` (Web MIDI API)

### Ouvrir l'éditeur

Ouvrez le fichier `weblink/index.html` depuis votre navigateur, ou accédez à l'URL hébergée si disponible.

### Se connecter

1. Branchez le miniMoc en USB
2. Dans la barre du haut, cliquez sur le menu déroulant **— Port MIDI —**
3. Sélectionnez **miniMoc** (ou le nom qui lui correspond)
4. Le point de statut devient **vert** ("Connecté")

> Un badge affiche la version du firmware connecté à côté du logo. Si ce firmware est trop ancien pour cette version de l'éditeur web, un bandeau d'avertissement apparaît avec un lien vers une version compatible du configurateur — voir [Dépannage](#15-dépannage).

### Onglets disponibles

| Onglet | Fonction |
|---|---|
| **SYNC** | Choisir la source d'horloge maître (11 sources + OFF), régler le tempo de l'horloge interne (boutons −/+, appui maintenu = défilement continu) et piloter le transport (▶/⏸ ⏹ ⏺ ⏪ ⏩) |
| **MATRICE** | Routage basique (grille 5×9) |
| **FLUX** | Routage avancé (filtrage, remapping de canaux, transformateurs) |
| **GENERATEURS** | Configuration des générateurs MIDI internes (LFO, séquenceur euclidien, motifs) |
| **HOST CONFIG** | Gestion des appareils USB |
| **FIRMWARE** | Mise à jour du firmware |

---

## 13. Mise à jour du firmware

### Via l'éditeur web (recommandé)

1. Dans l'éditeur web, onglet **FIRMWARE**
2. Choisissez la source du fichier :
   - **Firmwares du serveur** *(onglet par défaut)* : sélectionnez une version dans la liste — le fichier `.hex` est téléchargé automatiquement depuis le serveur
   - **Fichier local** : compilez d'abord dans l'Arduino IDE (**Croquis → Exporter le binaire compilé**), puis glissez le `.hex` dans la zone ou cliquez pour le sélectionner
3. Une fois le fichier chargé, cliquez **⬆ Mettre à jour le firmware**
4. Sélectionnez le port série du miniMoc dans le sélecteur du navigateur
5. Attendez la barre de progression et le message de confirmation
6. Le miniMoc redémarre automatiquement

### Première installation (Arduino IDE)

Si le miniMoc n'a jamais de firmware, ou en cas de problème grave :

1. **Installer Arduino IDE** (dernière version)
2. **Installer Teensyduino** : [pjrc.com/teensy/teensyduino.html](https://www.pjrc.com/teensy/teensyduino.html)
3. **Installer les bibliothèques** (Croquis → Gérer les bibliothèques) :
   - U8g2
   - Arduino MIDI Library (v5+)
   - MTP_Teensy
   - SdFat
   - Encoder
   - Bounce2
4. **Configurer Arduino IDE** :
   - Outils → Carte → **Teensy 4.1**
   - Outils → Type USB → **Serial + MIDI**
   - Outils → Vitesse CPU → **600 MHz**
   - Outils → Optimisation → **Faster**
5. Ouvrir `firmware/firmware.ino`
6. **Croquis → Téléverser**

---

## 14. Référence des menus OLED

```
CAROUSEL PRINCIPAL
├── PRESET
│   ├── Sélectionner preset actif (1–32)
│   ├── Charger depuis SD
│   └── Sauver sur SD
│
├── ROUTAGE
│   ├── MATRICE   ← grille 5×9
│   └── FLUX      ← liste des flux / créer / éditer / supprimer
│
├── SYNC   ← liste défilante, 11 sources + OFF
│   ├── A (TRS) / B (TRS)
│   ├── C (USB Host) / D (USB Host) / E (USB Host)
│   ├── A (USB/PC) … E (USB/PC)
│   ├── MINIMOC   ← horloge interne
│   └── OFF
│
├── MONITOR
│   ├── Page 1 — VU-mètres temps réel (5 entrées + 9 sorties)
│   └── Page 2 — BPM du maître SYNC en grand (tournez l'encodeur pour naviguer)
│
├── SYSTEME
│   ├── INFO           ← numéro preset, stats SD, noms appareils USB
│   ├── HOST CONFIG    ← mode AUTO/MANUEL, assignation des slots
│   ├── USB LINK       ← forcer détection appareils (2,5 s)
│   ├── USB RESET      ← redémarrage complet Teensy
│   ├── CONTRASTE      ← luminosité OLED (16–255)
│   └── BPM REFRESH    ← fréquence d'actualisation de la page BPM du MONITOR (250ms–5s ou MANUEL)
│
└── TRANSPORT   ← tempo + transport de l'horloge interne MINIMOC
    ├── Tourner l'encodeur     : ±1 BPM (±5 en rotation rapide)
    ├── Clic encodeur          : Play / Pause
    ├── Clic simple BACK       : STOP (si en pause) ou retour au menu précédent
    └── BACK maintenu + encodeur : Record / Avance / Rewind (MMC)
```

---

## 15. Dépannage

| Problème | Cause possible | Solution |
|---|---|---|
| L'éditeur web ne se connecte pas | Mauvais navigateur | Utilisez Chrome ou Edge uniquement |
| L'éditeur web ne se connecte pas | USB non reconnu | Essayez un autre port USB ou câble |
| Pas de son en sortie | Matrice vide | Vérifiez onglet MATRICE — activez les cellules |
| Doublement du signal MIDI | Flux + Matrice actifs simultanément | Désactivez la cellule Matrice correspondant au Flux |
| Clock irrégulier | Plusieurs sources de clock actives sur la même lettre | Choisissez explicitement **TRS/Host** ou **USB/PC** dans SYNC — les deux ne sont plus mélangées automatiquement |
| Le tempo affiché ne bouge pas quand je change le BPM | Réglage BPM REFRESH sur un intervalle long ou MANUEL | Cliquez l'encodeur sur la page BPM du MONITOR pour forcer une actualisation immédiate |
| L'éditeur web affiche un bandeau "firmware plus ancien" | Le firmware connecté ne supporte pas certaines fonctions de cette version de l'éditeur | Utilisez le lien du bandeau (ou le lien "configurateur classique" en bas de la barre latérale) vers la version compatible |
| Appareils USB non reconnus | Ordre de connexion | SYSTEME → USB LINK, ou USB RESET |
| Appareils USB changent de port | Mode AUTO actif | HOST CONFIG → passer en mode MANUEL |
| Carte SD non détectée | Carte absente ou non formatée | Insérez une carte SD formatée FAT32 |
| Firmware ne se met pas à jour | Fichier `.hex` incorrect | Recompilez dans Arduino IDE avec les bons paramètres |
| Écran OLED très sombre | Contraste bas | SYSTEME → CONTRASTE → augmentez la valeur |

---

*miniMoc — firmware PolyForm NC 1.0 / hardware CC BY-NC 4.0*

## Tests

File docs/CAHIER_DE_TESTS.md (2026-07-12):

# miniMoc — Cahier de tests unitaires

> Basé sur `docs/SPECS.md` et `docs/USERGUIDE.md`. À dérouler avec la configuration matérielle ci-dessous.
> Pour chaque test : dérouler la procédure, cocher OK/KO, noter les écarts observés en commentaire.

---

## 0. Configuration matérielle de test

### Entrées

| Port | Type | Appareil |
|---|---|---|
| A | TRS | Novation SL MK2 |
| B | TRS | Electribe 2 |
| C | USB Host | Arturia MiniLab |
| D | USB Host | *(libre — réservé pour tests de branchement à chaud)* |
| E | USB Host | *(libre — réservé pour tests de branchement à chaud)* |

### Sorties

| Port | Type | Appareil |
|---|---|---|
| 1 | TRS | Dreadbox Typhon |
| 2 | TRS | Minifreak |
| 3 | TRS | Electribe 2 |
| 4 | TRS | reface CP |
| 5 | TRS | Keytron SD1000 |
| 6 | TRS | Novation SL MK2 |
| 7 | USB Host | OP-1 |
| 8 | USB Host | *(libre)* |
| 9 | USB Host | *(libre)* |

### Poste informatique

| Rôle | Machine |
|---|---|
| Smart Mirror / enregistrement DAW | PC + Ableton Live (branché en USB sur le miniMoc) |
| Éditeur web (weblink) | PC + navigateur Chrome ou Edge, fichier `weblink/index.html` (ou URL hébergée) |

> **Point d'attention config** : l'Electribe 2 est câblée à la fois en entrée B et en sortie 3, et le Novation SL MK2 à la fois en entrée A et en sortie 6. Vérifier lors des tests de bouclage qu'un message n'est pas indéfiniment renvoyé vers sa propre source (cf. §2 test MATRICE-05, §3 test FLUX-06).
> **Point d'attention USB Host** : MiniLab (entrée C) et OP-1 (sortie 7) sont deux appareils USB distincts. En mode AUTO, l'assignation des slots est FIFO — l'ordre de branchement détermine qui devient C/D/E. Ce point est directement testé en §7.

---

## 1. Connectique & détection de base

| ID | Procédure | Résultat attendu | OK/KO |
|----|---|---|:---:|
| CONN-01 | Démarrer le miniMoc sans rien de branché | Écran logo puis carousel s'affiche normalement, aucun blocage | |
| CONN-02 | Brancher Novation SL MK2 sur A, Electribe 2 sur B (câbles TRS) | MONITOR (page VU-mètres) affiche une activité sur A et B dès qu'une note est jouée sur chaque appareil | |
| CONN-03 | Brancher MiniLab sur un port USB Host du miniMoc | SYSTEM → INFO liste MiniLab parmi les devices USB (D1..D6) ; MONITOR affiche l'activité sur le port logique C (mode AUTO, 1er device = C) | |
| CONN-04 | Brancher les 6 sorties TRS (Typhon=1, Minifreak=2, Electribe2=3, reface CP=4, Keytron=5, SL MK2=6) et OP-1 sur une sortie USB Host | SYSTEM → INFO confirme la présence d'OP-1 ; aucune sortie TRS ne nécessite de config | |
| CONN-05 | Débrancher puis rebrancher le câble USB PC pendant que le miniMoc fonctionne seul (sans PC) | Le routage MIDI matériel (TRS/USB Host) continue de fonctionner sans interruption pendant le débranchement | |

---

## 2. Routage basique — MATRICE (grille 5×9)

| ID | Procédure | Résultat attendu | OK/KO |
|----|---|---|:---:|
| MATRICE-01 | Charger le preset d'usine VIDE, jouer une note sur Novation SL MK2 (A) | Aucune sortie ne reçoit la note | |
| MATRICE-02 | Activer la cellule [A, 1] (MATRICE), jouer une note sur A | Dreadbox Typhon (sortie 1) reçoit la note, sur tous les canaux (passthrough canal) | |
| MATRICE-03 | Activer [A,1] et [A,2] simultanément | Note de Novation SL MK2 arrive à la fois sur Typhon (1) et Minifreak (2) | |
| MATRICE-04 | Charger le preset DIAGONALE (A→1, B→2, C→3, D→4, E→5) | Novation SL MK2 (A) → Typhon (1) ; Electribe2 (B) → Minifreak (2) ; MiniLab (C) → Electribe2 (3) | |
| MATRICE-05 | Activer [B,3] (Electribe2 → Electribe2 en sortie 3) | La note jouée sur l'Electribe2 (entrée B) ressort sur sa propre entrée MIDI (sortie 3) — vérifier absence de boucle infinie ou de blocage (le miniMoc ne renvoie pas la note reçue en retour, pas de ré-injection) | |
| MATRICE-06 | Charger le preset MERGE | Toutes les entrées (A,B,C) arrivent sur toutes les sorties actives ; jouer sur MiniLab (C) doit atteindre les 6 sorties TRS + OP-1 (7) | |
| MATRICE-07 | Charger USB>TRS | MiniLab (C, entrée USB) routé vers les sorties TRS 1–6 ; aucune sortie vers OP-1 (7) | |
| MATRICE-08 | Charger TRS>USB | Novation SL MK2 (A) et Electribe2 (B) routés vers OP-1 (sortie 7 USB Host) ; aucune sortie TRS | |
| MATRICE-09 | Désactiver toutes les cellules (retour VIDE) puis vérifier via MONITOR | Barres d'entrée VU-mètre continuent de s'allumer (réception indépendante du routage) mais aucune sortie ne s'anime | |

---

## 3. Routage avancé — FLUX

| ID | Procédure | Résultat attendu | OK/KO |
|----|---|---|:---:|
| FLUX-01 | Créer un flux : Entrée B canal 10 uniquement → Sortie 3 canal 1 (remap) | Jouer canal 10 sur Electribe2 (B) → arrive sur Electribe2 (sortie 3) reconverti en canal 1 ; jouer canal 1 sur B ne passe pas | |
| FLUX-02 | Créer un flux : Entrée A (ALL canaux) → Sortie 6 (ALL, passthrough) | Toute note de Novation SL MK2 (A), quel que soit le canal, ressort sur sa propre sortie 6 (SL MK2), canal conservé | |
| FLUX-03 | Créer un flux multi-entrées : {A, ch1} + {B, ch2} → {sortie 4, ch1} | ch1 de SL MK2 et ch2 d'Electribe2 arrivent tous deux sur reface CP (sortie 4) en canal 1 | |
| FLUX-04 | Créer 16 flux (maximum) | Le 17e flux est refusé ou impossible à créer (limite respectée) | |
| FLUX-05 | Activer un flux ET la cellule MATRICE correspondante en parallèle (ex FLUX-01 + MATRICE [B,3]) | Doublement du signal MIDI observé sur Electribe2 sortie 3 (comportement cumulatif documenté — non un bug) | |
| FLUX-06 | Modifier un flux existant (bouton Éditer) puis le supprimer (✕) | Modification appliquée immédiatement ; suppression stoppe le routage correspondant sans affecter les autres flux/matrice | |
| FLUX-07 | Créer un flux avec sélection multi-canaux via la grille 4×4 (ex. ch1, ch3, ch7 sur MiniLab C) | Seules les notes sur les canaux cochés passent, les autres canaux de C sont bloqués pour ce flux | |

---

## 4. Synchronisation MIDI Clock (SYNC)

| ID | Procédure | Résultat attendu | OK/KO |
|----|---|---|:---:|
| SYNC-01 | Régler SYNC = A (TRS), envoyer Clock depuis Novation SL MK2 sur l'entrée A | Toutes les sorties actives (TRS 1–6 + OP-1 si branché) reçoivent le Clock ; MONITOR page BPM affiche le tempo mesuré | |
| SYNC-02 | Régler SYNC = C (USB Host), envoyer Clock depuis MiniLab | Clock diffusé sur toutes les sorties ; vérifier qu'aucune autre source n'est écoutée en parallèle | |
| SYNC-03 | Régler SYNC = A (USB/PC), envoyer Clock depuis Ableton via le câble miroir A | Clock d'Ableton propagé sur les sorties, alors qu'un clock TRS simultané sur l'entrée physique A est ignoré | |
| SYNC-04 | Envoyer simultanément un Clock TRS sur A et un Clock USB/PC sur le miroir A, avec SYNC=A (TRS) | Seul le clock TRS physique est suivi, le clock USB/PC est ignoré (pas de tempo instable/mélangé) | |
| SYNC-05 | Régler SYNC = MINIMOC, définir un BPM via le menu TRANSPORT | Le miniMoc génère lui-même le Clock en continu, y compris en naviguant dans d'autres menus ou avec le VU-mètre MONITOR actif | |
| SYNC-06 | SYNC = MINIMOC, envoyer volontairement un Start MIDI externe depuis SL MK2 sur A | Le Start externe est ignoré (seule la source sélectionnée est maître) | |
| SYNC-07 | Régler SYNC = OFF | Aucun Clock/Start/Stop/Continue n'est propagé sur aucune sortie, quel que soit ce qui est branché en entrée | |
| SYNC-08 | Parcourir la liste des 11 sources + OFF depuis l'écran OLED SYNC | La source active est marquée d'un `*`, indépendamment de la position du curseur ; le choix est conservé après redémarrage (persistance EEPROM) | |
| SYNC-09 | Sélectionner une source SYNC depuis l'onglet SYNC de l'éditeur web | Réglage appliqué et sauvegardé immédiatement, visible aussi sur l'écran OLED | |

---

## 5. Transport (Play/Pause/Stop, MMC)

*Pré-requis : SYNC = MINIMOC.*

| ID | Procédure | Résultat attendu | OK/KO |
|----|---|---|:---:|
| TRSP-01 | Entrer dans le menu TRANSPORT, tourner l'encodeur | BPM affiché change de ±1 ; ±5 si rotation rapide (< 180 ms entre crans) | |
| TRSP-02 | Clic encodeur (1er appui) | Indicateur passe à PLAY, un message Start (FA) est envoyé sur toutes les sorties + miroir PC | |
| TRSP-03 | Clic simple BACK pendant PLAY | Retour au menu précédent (pas de Stop) | |
| TRSP-04 | Revenir dans TRANSPORT, clic encodeur (Pause) | Indicateur PAUSE, message Stop (FC) envoyé, `transport_resumable=true` | |
| TRSP-05 | Clic encodeur à nouveau depuis PAUSE | Message Continue (FB) envoyé (pas un nouveau Start) | |
| TRSP-06 | Depuis PAUSE, clic simple BACK | STOP réel (le prochain Play enverra Start, pas Continue) | |
| TRSP-07 | Maintenir BACK + clic encodeur | Message MMC Record Strobe envoyé (SysEx `F0 7F 7F 06 06 F7`) — vérifier réception sur un device MMC-compatible ou via un analyseur MIDI | |
| TRSP-08 | Maintenir BACK + tourner à droite / à gauche | MMC Fast Forward / Rewind envoyés respectivement | |
| TRSP-09 | Rester sur l'écran TRANSPORT et vérifier le long-appui BACK global (retour logo) | Le geste global BACK→logo (1s) est désactivé sur cet écran, pour ne pas interrompre les gestes chordés | |
| TRSP-10 | Piloter Play/Pause/Stop/Record/FF/RW depuis l'onglet SYNC de l'éditeur web | Mêmes effets que les gestes physiques, cohérence affichée entre OLED et éditeur web | |

---

## 6. Presets (SD)

| ID | Procédure | Résultat attendu | OK/KO |
|----|---|---|:---:|
| PRST-01 | Configurer un routage (MATRICE + FLUX + SYNC), Sauver sur preset 5 | Fichier `/PRESETS/PRST05.DAT` créé/mis à jour sur la carte SD | |
| PRST-02 | Charger un autre preset puis recharger le preset 5 | Routage, flux et réglage SYNC restaurés à l'identique | |
| PRST-03 | Redémarrer le miniMoc (coupure d'alimentation) | Le dernier preset actif (EEPROM) est rechargé automatiquement au boot | |
| PRST-04 | Charger chacun des 8 presets d'usine (VIDE, DIAGONALE, MERGE, DISPATCH, TOTAL, SPLIT, USB>TRS, TRS>USB) | Chaque preset produit le comportement décrit dans le guide utilisateur | |
| PRST-05 | Charger un preset legacy v1 (si disponible) | Migration automatique vers v3 sans perte (route_matrix legacy → basic_matrix déduite) | |
| PRST-06 | Sauver/charger un preset via l'éditeur web | Comportement identique à l'écran OLED, astérisque `*` affiché en cas de modif non sauvée | |
| PRST-07 | Tester la limite haute (preset 32) | Sauvegarde/chargement fonctionne sans erreur | |

---

## 7. USB Host — HOST CONFIG

*Pré-requis : MiniLab (entrée) et OP-1 (sortie) branchés sur deux ports USB Host distincts.*

| ID | Procédure | Résultat attendu | OK/KO |
|----|---|---|:---:|
| HOST-01 | Mode AUTO, brancher MiniLab en premier puis OP-1 en second | MiniLab → port logique C (+7 en miroir de slot), OP-1 second device → assigné au slot suivant (D+8) — noter que sans MANUEL, OP-1 n'est pas nécessairement en sortie 7 | |
| HOST-02 | Mode AUTO, débrancher/rebrancher les deux appareils dans l'ordre inverse | L'assignation change en fonction du nouvel ordre de branchement (comportement FIFO documenté) | |
| HOST-03 | Passer en mode MANUEL depuis SYSTEM → HOST CONFIG | Listes déroulantes activées, assigner explicitement le slot de MiniLab → C et le slot d'OP-1 → 7 | |
| HOST-04 | Avec le mapping manuel de HOST-03, débrancher/rebrancher MiniLab et OP-1 en même temps, en désordre | Chaque appareil retrouve son port logique via VID:PID, indépendamment de l'ordre physique de branchement | |
| HOST-05 | Éteindre/rallumer le miniMoc avec le mapping MANUEL déjà configuré | Mapping conservé après redémarrage (persistance EEPROM adresse 2) | |
| HOST-06 | Configurer HOST CONFIG depuis l'éditeur web (onglet HOST CONFIG) | Résultat identique à la configuration via écran OLED | |
| HOST-07 | Brancher un 3e appareil USB Host sur le port D ou E libre (test de branchement à chaud) | Le nouvel appareil est détecté sans reboot ; SYSTEM → INFO le liste | |
| HOST-08 | Provoquer un problème de reconnaissance (débrancher pendant l'activité) puis lancer USB LINK | Re-détection des appareils en ~2,5 s sans reboot complet | |
| HOST-09 | Lancer USB RESET | Redémarrage complet du Teensy, tous les appareils USB Host se ré-énumèrent proprement | |

---

## 8. Monitor

| ID | Procédure | Résultat attendu | OK/KO |
|----|---|---|:---:|
| MON-01 | Entrer dans MONITOR (page VU-mètres), jouer sur chacune des 3 entrées (A, B, C) | Chaque barre d'entrée s'allume à réception, avec fondu ~500 ms, indépendamment du routage actif | |
| MON-02 | Router A→1 (MATRICE) et jouer sur A | Barre d'entrée A ET barre de sortie 1 (Typhon) s'animent | |
| MON-03 | Tourner l'encodeur vers la droite pour passer à la page BPM, SYNC = A (TRS) actif avec Clock envoyé | Tempo du maître affiché en grand, arrondi à l'entier le plus proche ; source maître rappelée en haut | |
| MON-04 | Couper la source Clock plus de 2 secondes | Écran affiche NO CLOCK | |
| MON-05 | Régler SYSTEM → BPM REFRESH sur 5000 ms, changer le tempo pendant l'affichage de la page BPM | L'affichage ne se met à jour qu'après ~5 s, sauf clic encodeur qui force une actualisation immédiate | |
| MON-06 | Régler BPM REFRESH sur MANUEL | Affichage jamais rafraîchi automatiquement ; seul le clic encodeur actualise | |
| MON-07 | Vérifier le clignotement de la LED embarquée pendant la lecture SYNC=MINIMOC | LED clignote à chaque temps (toutes les 24 ticks), indépendamment de l'écran affiché | |
| MON-08 | Retourner à l'écran d'accueil après consultation MONITOR | Recommandation du guide : limiter le temps sur MONITOR en usage à forte densité MIDI pour éviter le jitter dû au refresh I²C (~20 ms) — vérifier absence de jitter audible une fois revenu au carousel | |

---

## 9. Menu SYSTEM

| ID | Procédure | Résultat attendu | OK/KO |
|----|---|---|:---:|
| SYS-01 | SYSTEM → INFO | Stats carte SD affichées + liste des devices USB physiques branchés (MiniLab, OP-1) | |
| SYS-02 | SYSTEM → CONTRASTE, faire varier de 16 à 255 | Luminosité OLED change visiblement sur toute la plage | |
| SYS-03 | SYSTEM → USB LINK | Polling 2,5 s, appareils USB non reconnus forcés à se ré-énumérer, sans reboot | |
| SYS-04 | SYSTEM → USB RESET | Reboot complet du Teensy (équivalent power-cycle), retour au logo puis restauration preset/config | |
| SYS-05 | SYSTEM → BPM REFRESH, parcourir toutes les options (250/500/1000/2000/5000/MANUEL) | Chaque valeur est sélectionnable et persistée en EEPROM (adresse 36) | |
| SYS-06 | Retirer la carte SD puis consulter SYSTEM → INFO | Message d'absence de carte cohérent, pas de blocage du firmware | |

---

## 10. Smart Mirror (Ableton / DAW)

| ID | Procédure | Résultat attendu | OK/KO |
|----|---|---|:---:|
| MIRROR-01 | Brancher le miniMoc en USB sur le PC, ouvrir Ableton Live | Le miniMoc apparaît comme périphérique MIDI multi-port (15 câbles virtuels), sans installation de driver | |
| MIRROR-02 | Dans Ableton, armer une piste sur le câble correspondant à l'entrée A, jouer sur Novation SL MK2 | La note est reçue en temps réel dans Ableton (câble 1 = entrée physique A) | |
| MIRROR-03 | Router A→1 (MATRICE), armer dans Ableton le câble correspondant à la sortie 1 | Ableton reçoit également le miroir de ce qui sort vers Dreadbox Typhon (câble 6-11 = sorties 1–6) | |
| MIRROR-04 | Jouer sur MiniLab (entrée C, USB Host) avec Ableton armé sur le câble 3 (entrées USB Host C/D/E) | Réception confirmée dans Ableton indépendamment du routage | |
| MIRROR-05 | Envoyer du MIDI depuis Ableton sur le câble miroir de sortie 7 (OP-1) | Le message ressort physiquement sur OP-1 comme si envoyé directement par le miniMoc | |
| MIRROR-06 | Débrancher le PC en cours d'utilisation | Le miniMoc continue de fonctionner en autonome (Smart Mirror non requis pour le fonctionnement standalone) | |
| MIRROR-07 | Rebrancher le PC | Les mêmes ports réapparaissent dans Ableton avec les mêmes numéros de câble | |
| MIRROR-08 | Test croisé SYNC-03/04 (§4) avec Ableton comme source de Clock via le câble miroir A | Confirme le comportement TRS vs USB/PC documenté en §4.1 des specs | |

---

## 11. Enregistrement MIDI sur SD

| ID | Procédure | Résultat attendu | OK/KO |
|----|---|---|:---:|
| REC-01 | Jouer sur plusieurs entrées avec un routage actif pendant quelques minutes | Fichier(s) `/REC/RECnnn.DAT` créé(s)/mis à jour sur la carte SD | |
| REC-02 | Remplir jusqu'à REC099 puis continuer à jouer | REC001 est écrasé (ring buffer confirmé) | |
| REC-03 | Brancher le miniMoc en USB sous Windows, vérifier qu'il apparaît en disque amovible | Fichiers `/REC/*.DAT` accessibles en copie | |
| REC-04 | Charger un `.dat` dans l'éditeur web, onglet DAT → MIDI | Événements affichés dans un tableau (horodatage, source, destination, type, canal) | |
| REC-05 | Configurer l'export : diviser par sortie physique, BPM 120, PPQ 960, cocher les pistes | Fichier `.mid` téléchargé, lisible dans un lecteur MIDI standard, tempo et résolution respectés | |
| REC-06 | Répéter REC-05 en divisant par source d'entrée plutôt que sortie | Pistes réparties différemment dans le fichier exporté, conformément au choix | |

---

## 12. Weblink / Éditeur web

| ID | Procédure | Résultat attendu | OK/KO |
|----|---|---|:---:|
| WEB-01 | Ouvrir `weblink/index.html` dans Chrome/Edge, brancher le miniMoc en USB | Menu déroulant "— Port MIDI —" liste le miniMoc | |
| WEB-02 | Sélectionner le port miniMoc | Point de statut passe au vert ("Connecté"), badge de version firmware affiché à côté du logo | |
| WEB-03 | Ouvrir avec un navigateur non-Chromium (Firefox) | Connexion impossible (Web MIDI API non supportée) — comportement attendu, à documenter | |
| WEB-04 | Tester chaque onglet (SYNC, MATRICE, FLUX, HOST CONFIG, FIRMWARE, DAT→MIDI) avec la config matérielle en place | Chaque onglet reflète et modifie l'état réel du miniMoc en temps réel | |
| WEB-05 | Modifier une cellule MATRICE depuis le navigateur, vérifier sur l'écran OLED | Changement appliqué immédiatement et visible sur les deux interfaces | |
| WEB-06 | Onglet FIRMWARE → sélectionner une version depuis "Firmwares du serveur" | Fichier `.hex` téléchargé automatiquement depuis le serveur | |
| WEB-07 | Lancer la mise à jour firmware (⬆), choisir le port série dans le sélecteur navigateur | Barre de progression, confirmation, redémarrage automatique du miniMoc avec le nouveau firmware actif | |
| WEB-08 | Vérifier le comportement si le firmware connecté est plus ancien que l'éditeur web | Bandeau d'avertissement affiché avec lien vers une version compatible du configurateur | |
| WEB-09 | Onglet FIRMWARE → "Fichier local", glisser un `.hex` compilé manuellement (Arduino IDE, Exporter le binaire compilé) | Même flux de mise à jour que WEB-06/07, avec le fichier local | |
| WEB-10 | Brancher/débrancher le miniMoc pendant que l'éditeur web est ouvert | Le menu déroulant "Port MIDI" reflète la disponibilité (dé)connexion sans crash de la page | |

---

## 13. Robustesse / cas limites

| ID | Procédure | Résultat attendu | OK/KO |
|----|---|---|:---:|
| ROB-01 | Couper l'alimentation brutalement pendant une écriture SD (sauvegarde preset ou enregistrement) | Redémarrage propre, pas de corruption bloquante de la carte SD (au pire perte du dernier événement) | |
| ROB-02 | Enchaîner rapidement de nombreux changements MATRICE/FLUX/SYNC via l'éditeur web | Pas de blocage ni désynchronisation entre firmware et éditeur web | |
| ROB-03 | Saturer une sortie TRS avec un flux de données MIDI dense (ex. pitch bend continu sur SL MK2) pendant que SYNC=MINIMOC | Le Clock interne (IntervalTimer/ISR) reste stable, pas de dérive tempo malgré la charge UART | |
| ROB-04 | Saturer une sortie USB Host (OP-1) de la même façon | `internal_clock_flush_usb()` absorbe le flag en best-effort ; vérifier qu'il n'y a pas de blocage prolongé du Clock USB Host, tout en acceptant une éventuelle latence supérieure au DIN | |
| ROB-05 | Naviguer dans tous les menus OLED pendant qu'un Clock externe rapide (200+ BPM) est actif sur une entrée TRS | Pas de perte de synchro DIN (l'ISR UART préempte l'affichage OLED bloquant ~8ms) | |
| ROB-06 | Débrancher un appareil USB Host en pleine transmission MIDI (ex. MiniLab pendant une note tenue) | Pas de note bloquée en "stuck note" sur les sorties routées ; récupération propre après USB LINK/RESET | |

---

## Synthèse

| Thème | Nb tests | OK | KO | Non testé |
|---|:---:|:---:|:---:|:---:|
| 1. Connectique | 5 | | | |
| 2. Matrice | 9 | | | |
| 3. Flux | 7 | | | |
| 4. Sync | 9 | | | |
| 5. Transport | 10 | | | |
| 6. Presets | 7 | | | |
| 7. Host Config | 9 | | | |
| 8. Monitor | 8 | | | |
| 9. System | 6 | | | |
| 10. Smart Mirror | 8 | | | |
| 11. Enregistrement SD | 6 | | | |
| 12. Weblink | 10 | | | |
| 13. Robustesse | 6 | | | |
| **Total** | **100** | | | |

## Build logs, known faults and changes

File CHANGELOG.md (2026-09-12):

# Journal des modifications — miniMoc firmware

Toutes les modifications notables de ce projet sont documentées ici.

Format inspiré de [Keep a Changelog](https://keepachangelog.com/fr/1.1.0/).  
Le versionnage suit [Semantic Versioning](https://semver.org/lang/fr/).

---

## [0.5.2] — 2026-09-12

### Modifié

- **Enregistrement MIDI continu sur SD reporté après la V1** : décision explicite de ne
  pas livrer cette fonctionnalité avec la V1 (`SD_RECORDER_ENABLED` reste désactivé par
  défaut) tant qu'il n'existe pas de commande manuelle pour démarrer/arrêter un
  enregistrement et fermer proprement le fichier (`sd_close()` toujours jamais appelé).
  Le montage de la carte SD et les presets restent actifs indépendamment (cf. 0.5.1).
- Éditeur web : onglet **DAT → MIDI** masqué en conséquence (flag `DAT2MIDI_ENABLED`
  dans `weblink/index.html`) — code conservé pour réactivation le jour où
  l'enregistrement continu sera retravaillé.

### Corrigé

- **Bornes défensives sur les générateurs chargés depuis un preset SD** : `division_idx`
  et `rate_x10hz` n'étaient pas validés à la lecture d'un preset (formats v7/v8/v9,
  `firmware/sd_presets.h`), contrairement au chemin SysEx (éditeur web) qui les
  clampait déjà. Un preset corrompu ou hors-format pouvait provoquer une lecture hors
  tableau de `LFO_DIVISIONS` et, si la valeur lue par erreur valait 0, une division par
  zéro pour un générateur LFO synchronisé.

## [0.5.1] — 2026-08-29

### Corrigé

- **Régression majeure sur les presets SD**, introduite par erreur en 0.4.0 (commit
  "ajout transformateurs") : `sd_setup()` / `sd_preset_init()` avaient été encapsulés
  dans `#ifdef SD_RECORDER_ENABLED`, désactivé par défaut dans la foulée du même
  commit — la carte SD n'était donc plus montée et les presets plus initialisés dans
  aucun build par défaut, de la 0.4.0 à la 0.5.0 incluses. Le montage SD et
  l'initialisation des presets sont désormais indépendants de `SD_RECORDER_ENABLED`,
  qui ne contrôle plus que l'enregistrement continu (et MTP).

## [0.5.0] — 2026-07-25

### Ajouté

- **Générateurs — Motifs de batterie pré-enregistrés** : troisième type de générateur
  (`GEN_PATTERN`). Rejoue en boucle un motif de batterie figé dans le firmware (Amen
  Break, Funky Drummer, Backbeat Simple — interprétations simplifiées, pas des
  transcriptions note pour note), toujours calé sur le maître SYNC (pas de mode libre).
  Moteur polyphonique à 4 voix simultanées pour gérer les hits qui tombent ensemble
  (ex. grosse caisse + charley sur le même pas).
- **Transport relié aux générateurs** : Play/Pause/Stop (écran TRANSPORT ou éditeur web)
  contrôle désormais aussi les générateurs (LFO, Euclidien, Motif) — Stop/Pause les gèle
  proprement (Note OFF immédiate, jamais de note bloquée), Continue reprend exactement
  où c'était plutôt que de redémarrer le motif.
- Format de preset SD **v9** (`Generator.pattern_id`), migration automatique des presets v8.
- Éditeur web : sélecteur de motif dans l'écran GENERATEURS, protocole étendu de façon
  rétrocompatible (octet optionnel en fin de message SysEx).

### Corrigé

- **Décalage rythmique systématique d'une division** sur les générateurs Euclidien et
  Motif en mode synchro : le motif était évalué après avoir attendu une division
  complète de pulses d'horloge au lieu du début du pas, décalant chaque hit en retard
  d'un pas entier (ex. 1/16) par rapport à la grille.

## [0.4.2] — 2026-07-25

### Ajouté

- **Système de générateurs** : jusqu'à 16 générateurs de flux MIDI internes,
  indépendants de toute entrée, routables vers plusieurs sorties/canaux comme un Flux.
  Nouveau sous-menu OLED GENERATEURS (dans ROUTAGE, au même niveau que FLUX).
  - **LFO** : 5 formes d'onde (triangle, sinus, carré, dent de scie, aléatoire
    échantillonné-bloqué), mode libre (Hz, 0.1–50.0) ou synchronisé à l'horloge MIDI
    (7 divisions, 1/16 à 4 mesures), sortie en CC continu (numéro configurable),
    amplitude et valeur centrale réglables.
  - **Euclidien** : séquenceur rythmique (algorithme de Bjorklund — répartition de
    pulses sur un nombre de pas configurable, avec rotation), sortie en Note ON/OFF,
    durée de gate réglable en % du pas.
  - Accélération de l'encodeur sur tous les réglages numériques du sous-menu
    (identique au mécanisme déjà utilisé pour le BPM).
- **Éditeur web** : nouvelle section GENERATEURS (protocole SysEx étendu, opcodes
  `0x12`/`0x13`), édition complète des deux types de générateur. Appui maintenu (+/-)
  généralisé à tous les champs numériques de l'éditeur, Flux compris.
- Format de preset SD v7 (générateurs) puis v8 (type Euclidien), migration automatique.

## [0.4.1] — 2026-07-21 → 2026-07-25

### Ajouté

- **Transformateur "Accords"** (`TRANS_CHORD_HARMONIZE`) : un Flux peut réinterpréter
  une note reçue comme un degré de gamme et la reprojeter sur l'accord courant d'une
  progression en cours de lecture (10 progressions prédéfinies : I-V-vi-IV, ii7-V7-Imaj7,
  blues, Canon de Pachelbel...), calée sur l'horloge/le transport. Tonique et nombre de
  mesures par accord réglables.

### Corrigé

- Corrections diverses sur les boutons de l'écran FLUX.
- Désactivation de l'enregistrement SD en continu (fonctionnalité en cours de retravail).

### Divers

- Ajout de fichiers spécifiques pour faciliter le flashage (patch IDE Arduino).

## [0.4.0] — 2026-07-13

### Ajouté

- **Transformateurs de Flux — Transpose et Harmonize** : chaque Flux peut porter une
  transformation optionnelle sur les notes routées.
  - **Transpose** : décalage fixe en demi-tons (-24 à +24).
  - **Harmonize** : empile jusqu'à 4 notes supplémentaires par rapport à la note reçue,
    intervalles réglables individuellement.

## [0.3.0] — 2026-07-12

### Ajouté

- **Maître SYNC étendu + écran TRANSPORT** : le maître d'horloge peut désormais être
  l'horloge interne de MiniMoc (tempo réglable, 20–300 BPM) en plus des 5 entrées
  physiques/USB existantes.
  - Écran TRANSPORT dédié : Play/Pause/Stop (clic encodeur), Record/Avance/Rewind via
    MIDI Machine Control (gestes chordés BACK + encodeur), réglage du tempo par pas de 1
    (accéléré à 5 en rotation rapide, même mécanisme repris plus tard pour les
    générateurs).
  - Période de rafraîchissement du BPM affiché réglable depuis SYSTEM.
- Fichier 3D pour un socle du boîtier.

## [0.2.2b] — 2026-07-11

### Ajouté

- Fichiers 3D pour le boîtier (impression) et fichiers KiCad du PCB du dessous.
- Scripts d'intégration Ableton Live (auto-création de pistes) — en cours.

### Modifié

- Désactivation de l'enregistrement automatique au démarrage.

## [0.2.2] — 2026-06-16

### Corrigé

- Synchronisation du "smart mirror" (miroir USB vers le DAW) pour le Clock/Start/Stop
  du maître SYNC.
- Correctifs divers sur l'éditeur web.

## [0.2.1] — 2026-06-14

### Ajouté

- Affichage du BPM reçu (calculé depuis l'horloge MIDI entrante) sur l'écran MONITOR.
- Éditeur web : possibilité de choisir un firmware `.hex` en ligne (liste des releases
  publiées) ou un fichier local, pour la mise à jour OTA.

---

## [0.2] — 2026-06-01

### Ajouté

#### Ports matériels

- **2 entrées MIDI physiques 5-broches TRS** (port A sur Serial2, port B sur Serial1),
  buffers étendus à 1 024 octets chacun (vs 64 par défaut) pour absorber les rafales.
- **6 sorties MIDI physiques 5-broches TRS** (sorties 1–6 sur Serial8/3/7/6 + les deux
  ports du Teensy réassignés en sortie A et B).
- **USB Host** : jusqu'à 6 périphériques MIDI USB simultanés via hub, gérés par
  USBHost_t36 avec 3 instances de hub pour la robustesse en hot-plug.  
  Les devices occupent 6 slots physiques internes (MIDIUSB1–6) et sont exposés en 3 entrées
  logiques (C, D, E) et 3 sorties logiques (7, 8, 9).

#### Routage MIDI

- **Architecture hybride BASIC + FLUX** : deux couches de routage cumulatives.

  - **Matrice BASIC (5 × 9)** : passthrough par port — active ou désactive simplement une
    connexion entre une entrée (A–E) et une sortie (1–9) sur tous les canaux MIDI.
    Représentée par un bitmask `uint16_t` par entrée.
  - **Flux avancés** : jusqu'à 16 règles simultanées, chacune pouvant agréger plusieurs
    entrées et plusieurs sorties, avec filtrage et remappage de canaux MIDI (par bitmask
    16 bits). Un canal d'entrée peut être redirigé vers un canal de sortie différent.
    Chaque flux peut être actif ou inactif.
  - `recompute_route_matrix()` reconstruit la matrice de routage complète après toute
    modification de BASIC ou d'un flux.

- **Smart Mirror** : chaque message MIDI routé vers une sortie physique est
  simultanément mirroré vers le câble USB correspondant (câbles 6–14), permettant à un
  DAW connecté d'enregistrer en temps réel tout le trafic physique sans câblage
  supplémentaire.

- **Passthrough DAW → matériel** : les messages arrivant depuis le DAW sur les câbles
  USB 6–11 sont acheminés directement vers les sorties physiques 1–6 ; les câbles 12–14
  sont acheminés vers les sorties USB Host 7–9 (si un device est connecté sur le slot
  correspondant).

- **Messages routés** : Note On/Off, Control Change, Program Change, Pitch Bend,
  Aftertouch canal.  
  Les messages Real-Time (Clock, Start, Stop, Continue, Active Sensing, System Reset)
  sont gérés séparément via le mécanisme SYNC.

- **8 presets d'usine** non modifiables, chargeable depuis l'interface :
  `VIDE`, `DIAGONALE`, `MERGE`, `DISPATCH`, `TOTAL`, `SPLIT`, `USB>TRS`, `TRS>USB`.

#### SYNC (horloge MIDI)

- **Maître d'horloge configurable** parmi les 5 entrées (A, B, C, D, E) ou `OFF`.
- Le port maître transmet Clock, Start, Stop, Continue, Active Sensing et System Reset
  vers toutes les sorties physiques (1–6) et USB Host (7–9) ; les Real-Time des autres
  ports sont filtrés pour éviter les doublons.
- Le choix du maître est persisté en EEPROM (adresse 34) et rechargé au démarrage.

#### Presets utilisateur (carte SD)

- **32 presets** sur carte SD dans `/PRESETS/PRST01.DAT` … `PRST32.DAT`.
- **Format v3** : chaque fichier contient un en-tête magique, la `route_matrix` dérivée,
  la `basic_matrix` et la liste de flux.
- **Migration automatique des fichiers v1** : les anciens presets (route_matrix seule)
  sont convertis en BASIC au chargement.
- Sauvegarde et chargement silencieux (sans interruption du routage MIDI en cours).
- L'index du preset actif est persisté en EEPROM (adresse 0) et rechargé au démarrage.

#### Enregistrement MIDI sur SD

- **Enregistrement automatique** de tous les événements MIDI routés, démarrant dès que
  la SD est disponible à l'initialisation.
- **Format binaire 10 octets** par événement :
  `[timestamp 32 bits µs] [sortie 1–9] [source] [type MIDI] [canal] [data1] [data2]`.
  Sources tracées : PC/DAW (0), Entrée A (1), B (2), USB Host C (3), D (4), E (5).
- **Architecture ring buffer** : 4 096 octets en RAM ; `rec_push()` ≈ 50 ns, non
  bloquant. Écriture SD différée par blocs de 280 octets minimum, sync tous les ~4 Ko.
- **Préallocation 20 Mo** au démarrage pour éviter la fragmentation et les pauses SD.
- **Sessions numérotées** de `REC001.DAT` à `REC099.DAT` avec wrap ; compteur en EEPROM
  (adresse 1).
- **Statistiques exposées** dans le sous-menu INFO : kilo-octets écrits, latence max
  d'écriture en µs, nombre de spikes (>3 ms), nombre d'overflows ring buffer.

> **Limitation connue** : `sd_close()` est défini dans le code mais n'est jamais appelé.
> Le fichier d'enregistrement n'est donc jamais fermé proprement en cours d'utilisation ;
> en particulier, les 20 Mo préalloués ne sont pas libérés. Les données sont cependant
> préservées grâce au `sync()` périodique. Il n'existe pas non plus de commande dans
> l'interface pour démarrer ou arrêter manuellement l'enregistrement.

#### Accès SD depuis le PC (MTP)

- La carte SD est exposée en tant que volume `MiniMoc SD` via le protocole MTP
  (MTP_Teensy), permettant de récupérer les fichiers `REC*.DAT` et `PRST*.DAT` depuis
  le PC sans retirer la carte.
- Un adaptateur `SdFsAdapter` fait le pont entre SdFat (utilisé pour l'enregistrement)
  et l'interface `FS` requise par MTP_Teensy, sans réinitialiser le contrôleur SDIO.

#### Configuration USB Host

- **Mode AUTO** (défaut) : les devices USB MIDI sont assignés aux ports logiques
  (C/D/E/7/8/9) dans l'ordre de connexion (FIFO).
- **Mode MANUEL (LOCK)** : l'assignation port logique → slot physique est fixée par
  l'utilisateur et mémorisée par VID:PID. À la reconnexion, `hc_poll()` retrouve chaque
  device par son empreinte VID:PID, quel que soit son slot d'arrivée.
- Le mode et l'assignation sont persistés en EEPROM (adresses 2–33).

#### Interface utilisateur — OLED + encodeur + boutons

- **Écran OLED SSD1306 128 × 64 px** en I2C (400 kHz). L'oscillateur SSD1306 est réglé
  au maximum (registre `0xD5 = 0xF0`) pour la stabilité.
- **Encodeur rotatif** (pins 39/40) avec anti-rebond à deux niveaux : fenêtre de 120 ms
  + délai d'application de 60 ms. Un clic simultané annule la rotation en attente
  (protection contre les artefacts mécaniques).
- **Bouton SELECT** (pin 41, Bounce2, 5 ms) et **bouton BACK** (pin 38, 150 ms).
- **Appui long BACK (1 s)** : bascule entre le logo de veille et l'interface interactive.
  Un mécanisme de relâchement empêche un réveil immédiat après retour au logo.
- **Logo de veille** : affiche le logo Verveine 64 × 64 px et la version du firmware.
  Tout appui ou rotation de l'encodeur réveille l'interface.

**Structure de navigation** :

- **Carousel principal** : 5 sections — PRESET / SYNC / ROUTAGE / MONITOR / SYSTEM —
  avec animation de glissement horizontal (36 px par step, 16 px/frame) et affichage de
  l'icône 32 × 32 de la section active.  
  > Note : le code pour afficher les icônes 16 × 16 des sections adjacentes est présent
  > mais commenté ; seul l'icône central est actuellement rendu.

- **Sous-menu PRESET** : sélection du numéro de preset (1–32, indicateur `*` si le
  preset existe sur SD), sauvegarde, chargement, application d'un preset d'usine.
  Messages de confirmation centrés à l'écran pendant 1,2 s. Indicateur `SD indisponible`
  si la carte est absente.

- **Sous-menu SYNC** : grille 2 × 3 de grandes cases (A / B / C / D / E / OFF) ;
  la case active est affichée en inversé. Validation immédiate et persistance EEPROM.

- **Sous-menu ROUTAGE** : deux modes d'édition accessibles depuis un menu principal :
  - **MATRICE** : grille interactive 5 × 9 (entrées A–E en lignes, sorties 1–9 en
    colonnes). Un appui SELECT bascule chaque case. Mise à jour instantanée du routage.
  - **FLUX** : liste scrollable des flux existants (4 lignes visibles) avec résumé
    compact (`F1 - A → 1 4`). Création d'un nouveau flux, ou modification/suppression
    d'un flux existant via menu contextuel.  
    Création en deux étapes : sélection des ports d'entrée (A–E, appui court = toggle
    tout-canal, appui long = ouvre un picker de canaux 1–16), puis des ports de sortie
    (1–9, idem). Validation finale sur `✓ VALIDER`.

- **Sous-menu MONITOR** : VU-mètre temps réel — 5 barres d'entrée (A/B/C/D/E) en haut,
  séparateur horizontal, 9 barres de sortie (1–9) en bas. Décroissance en 500 ms.
  Rafraîchissement continu (indépendant des entrées utilisateur).

- **Sous-menu SYSTEM** : 5 entrées :
  - **INFO** (2 pages) : page 1 = preset actif + statistiques enregistrement SD ;
    page 2 = liste des 6 slots USB Host avec nom de produit ou VID:PID.
  - **HOST CONFIG** : bascule AUTO/MANUEL, assignation manuelle des 6 ports logiques
    vers les slots physiques D1–D6 via un popup scrollable.
  - **USB LINK** : polling intensif du bus USB pendant 2,5 s pour forcer l'énumération
    de devices non reconnus, sans reboot. Affiche le nombre de devices détectés.
  - **USB RESET** : redémarrage complet du Teensy (`SCB_AIRCR = SYSRESETREQ`) — à
    utiliser si USB LINK échoue.
  - **CONTRASTE** : réglage du contraste OLED par pas de 16 (valeurs 16–255) avec barre
    de progression et valeur en %. OK sauvegarde en EEPROM ; BACK annule.

#### Éditeur web — protocole SysEx

- Communication via câble USB 0, manufacturer ID `0x7D`.
- **Commandes reçues depuis le PC** :

  | Code | Action |
  |------|--------|
  | `0x01` | Mise à jour directe d'une cellule `route_matrix` (maintenu pour compatibilité éditeur legacy) |
  | `0x02` | Demande de dump complet vers le PC |
  | `0x05` | Charger le preset N depuis SD |
  | `0x06` | Sauvegarder dans le preset N sur SD |
  | `0x08` | Ping / heartbeat → réponse pong |
  | `0x09` | Mise à jour d'une case `basic_matrix` |
  | `0x0A` | Ajout ou mise à jour d'un flux |
  | `0x0B` | Suppression d'un flux |
  | `0x0C` | Définir le maître SYNC |
  | `0x0D` | Définir la configuration USB Host |
  | `0x0E` | Quick poll (dump allégé : preset, sync, basic_matrix, flux, host config) |
  | `0x10` | Reboot en mode bootloader HalfKay |

- **Dump complet** (`0x02`) : envoie `route_matrix`, preset actif, `basic_matrix`,
  liste de flux, maître SYNC, configuration USB Host, et noms de produits (ou VID:PID)
  des devices USB Host connectés.
- Les valeurs 16 bits sont encodées sur 3 octets SysEx 7 bits pour rester dans les
  limites du standard MIDI.

#### Mise à jour firmware OTA (via USB CDC)

- Mise à jour du firmware sans bootloader HalfKay, depuis un PC connecté en USB.
- **Protocole** :
  1. PC → Teensy : `START_UPDATE:{taille}\n`
  2. Teensy → PC : `ACK\n`
  3. Transfert par blocs de 256 octets, chaque bloc acquitté par `ACK\n`
  4. PC → Teensy : `END_UPDATE:{crc32hex}\n`
  5. Vérification CRC32 (IEEE 802.3) → `OK\n` ou `ERR:{raison}\n`
- **Zone de staging** : le nouveau firmware est écrit dans la moitié haute de la flash
  QSPI (offset 4 MiB, 4 MiB disponibles) sans risquer le firmware actif.
- **Application en ITCM** (`FASTRUN`) : la copie staging → partition active s'exécute
  entièrement depuis la SRAM (ITCM), IRQ désactivées, sans dépendre du code en flash.
- `ota_tick()` est non bloquant dans la boucle principale ; il bloque uniquement pendant
  la durée effective d'un transfert.

#### Identité USB

- Le Teensy s'énumère sous le nom `MINIMOC` (descriptor USB défini dans `name.c`).

---

*Changelog maintenu à la main à partir de l'historique du firmware — dernière mise à jour : v0.5.2.*

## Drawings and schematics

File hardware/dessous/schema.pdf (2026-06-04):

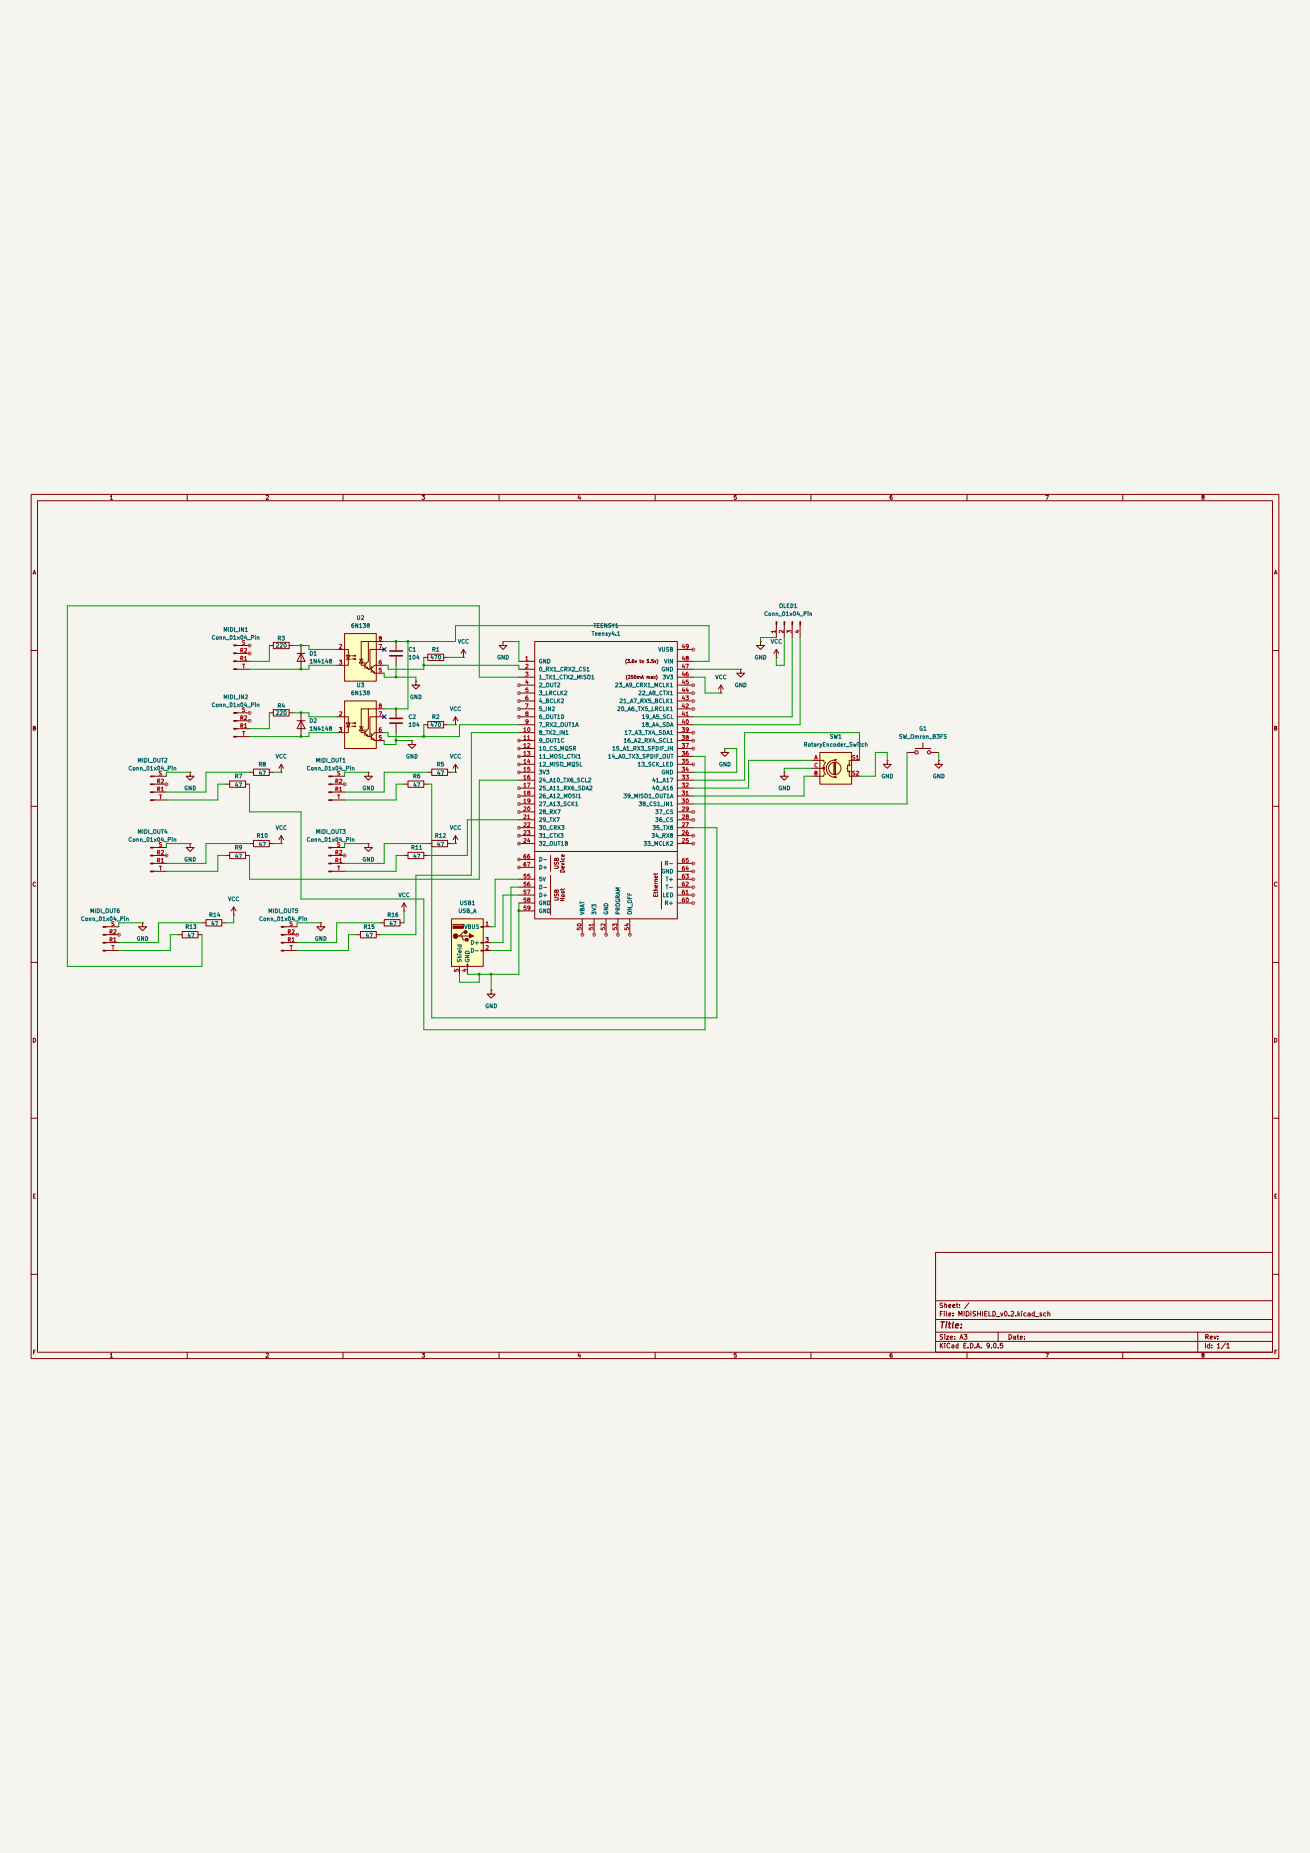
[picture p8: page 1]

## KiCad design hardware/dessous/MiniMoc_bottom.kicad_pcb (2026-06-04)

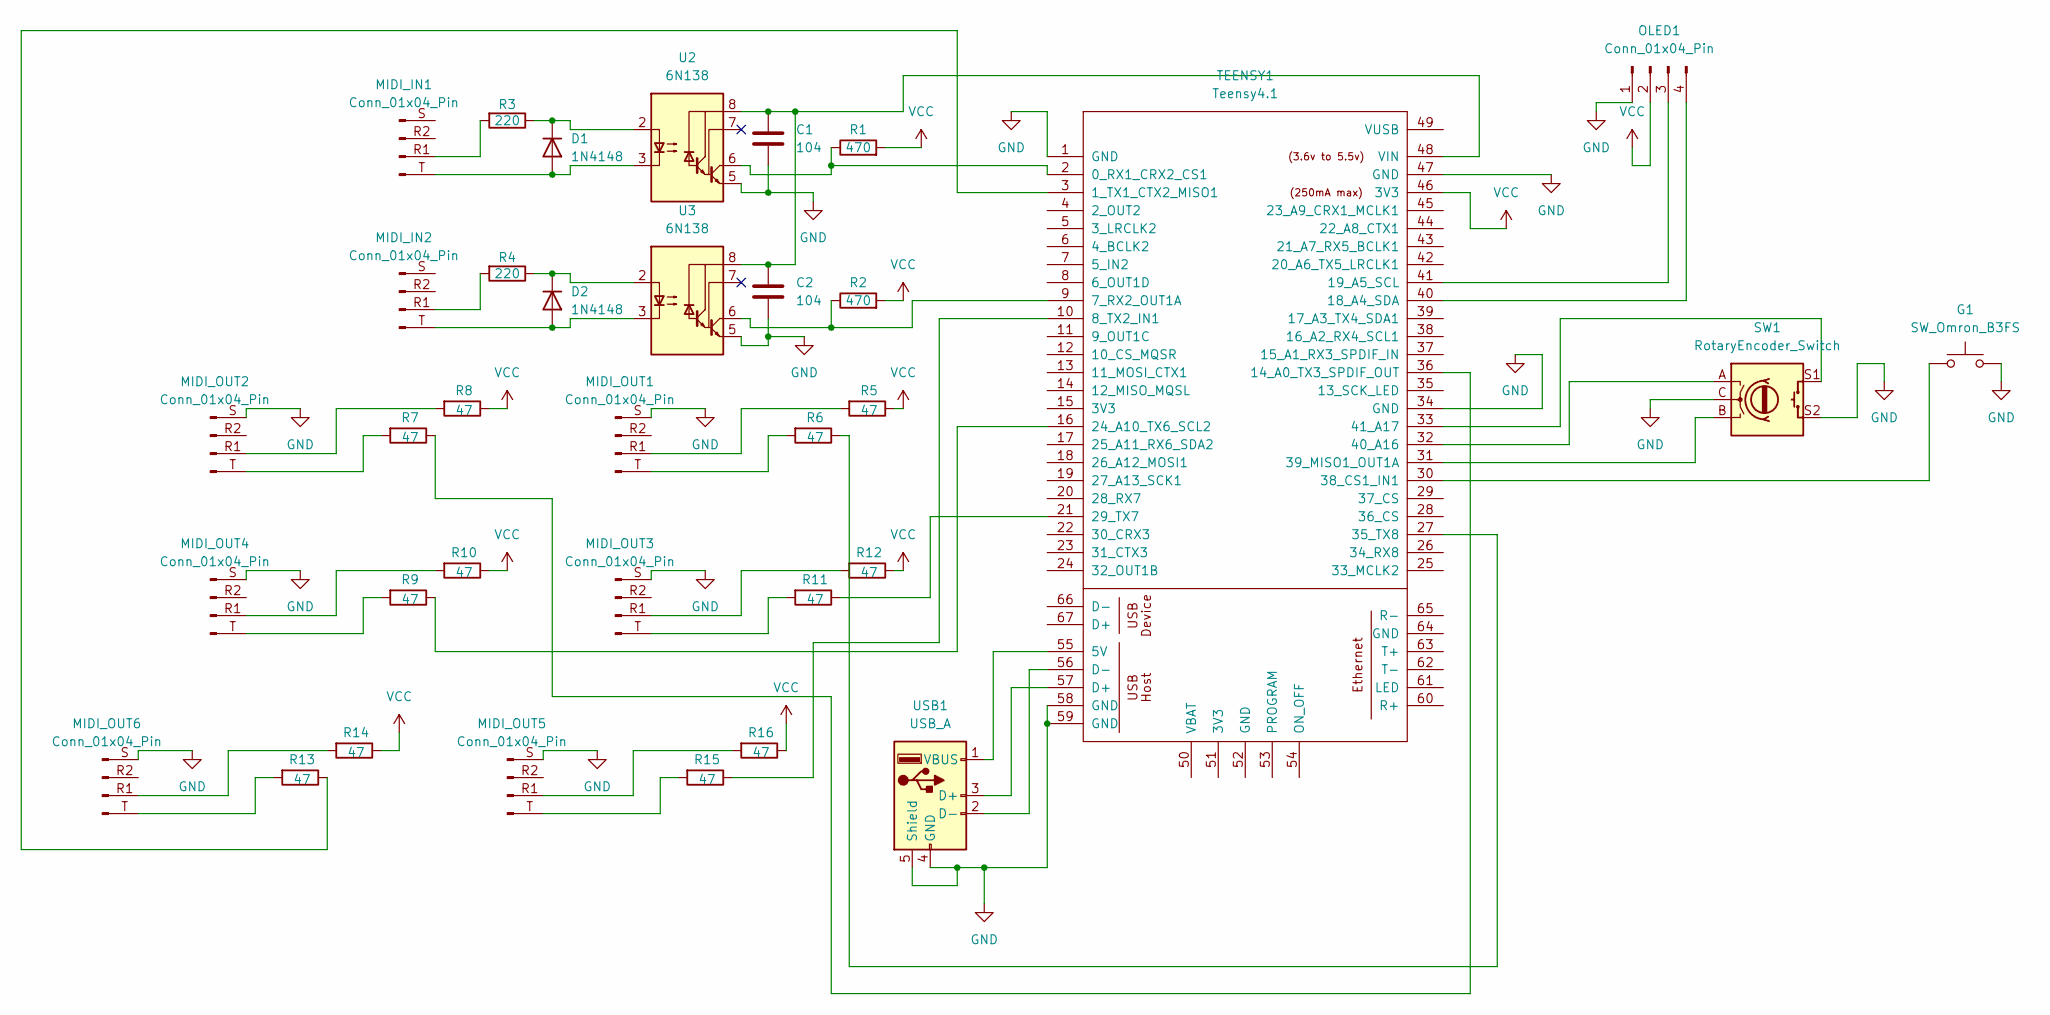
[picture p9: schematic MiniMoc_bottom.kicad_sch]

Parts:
C1, C2: 104; C_Disc_D5.0mm_W2.5mm_P2.50mm
D1, D2: 1N4148; D_DO-35_SOD27_P7.62mm_Horizontal
G1: SW_Omron_B3FS; SW_TH_Tactile_Omron_B3F-100x
MIDI_IN1, MIDI_IN2: Conn_01x04_Pin; Jack_3.5mm_PJ320E_Horizontal
MIDI_OUT1, MIDI_OUT2, MIDI_OUT3, MIDI_OUT4, MIDI_OUT5, MIDI_OUT6: Conn_01x04_Pin; Jack_3.5mm_PJ320E_Horizontal
OLED1: Conn_01x04_Pin; 128x64OLED
R1, R2: 470; R_Axial_DIN0207_L6.3mm_D2.5mm_P10.16mm_Horizontal
R3, R4: 220; R_Axial_DIN0207_L6.3mm_D2.5mm_P10.16mm_Horizontal
R5, R6, R7, R8, R9, R10, R11, R12, R13, R14, R15, R16: 47; R_Axial_DIN0207_L6.3mm_D2.5mm_P10.16mm_Horizontal
SW1: RotaryEncoder_Switch; RotaryEncoder_Alps_EC11E-Switch_Vertical_H20mm
TEENSY1: Teensy4.1; Teensy41
U2, U3: 6N138; DIP-8_W10.16mm_LongPads
USB1: USB_A; USB_A_Stewart_SS-52100-001_Horizontal

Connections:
GND: C1.2, C2.2, G1.2, MIDI_OUT1.S (Pin_1), MIDI_OUT2.S (Pin_1), MIDI_OUT3.S (Pin_1), MIDI_OUT4.S (Pin_1), MIDI_OUT5.S (Pin_1), MIDI_OUT6.S (Pin_1), OLED1.1, SW1.C, SW1.S2, TEENSY1.1 (GND), TEENSY1.34 (GND), TEENSY1.47 (GND), TEENSY1.58 (GND), TEENSY1.59 (GND), U2.5 (GND), U3.5 (GND), USB1.4 (GND), USB1.5 (Shield)
unnamed: D1.2 (A), MIDI_IN1.T (Pin_4), U2.3 (C2)
unnamed: D1.1 (K), R3.1, U2.2 (C1)
unnamed: D2.2 (A), MIDI_IN2.T (Pin_4), U3.3 (C2)
unnamed: D2.1 (K), R4.1, U3.2 (C1)
unnamed: MIDI_IN1.R1 (Pin_3), R3.2
unnamed: MIDI_IN2.R1 (Pin_3), R4.2
unnamed: MIDI_OUT1.R1 (Pin_3), R5.2
unnamed: MIDI_OUT1.T (Pin_4), R6.2
unnamed: MIDI_OUT2.R1 (Pin_3), R8.2
unnamed: MIDI_OUT2.T (Pin_4), R7.2
unnamed: MIDI_OUT3.R1 (Pin_3), R12.2
unnamed: MIDI_OUT3.T (Pin_4), R11.2
unnamed: MIDI_OUT4.R1 (Pin_3), R10.2
unnamed: MIDI_OUT4.T (Pin_4), R9.2
unnamed: MIDI_OUT5.R1 (Pin_3), R16.2
unnamed: MIDI_OUT5.T (Pin_4), R15.2
unnamed: MIDI_OUT6.R1 (Pin_3), R14.2
unnamed: MIDI_OUT6.T (Pin_4), R13.2
unnamed: OLED1.3, TEENSY1.41 (19_A5_SCL)
unnamed: OLED1.4, TEENSY1.40 (18_A4_SDA)
unnamed: R1.1, TEENSY1.2 (0_RX1_CRX2_CS1), U2.6 (VO2)
unnamed: R13.1, TEENSY1.3 (1_TX1_CTX2_MISO1)
unnamed: TEENSY1.55 (5V), USB1.1 (VBUS)
unnamed: R2.1, TEENSY1.9 (7_RX2_OUT1A), U3.6 (VO2)
unnamed: R15.1, TEENSY1.10 (8_TX2_IN1)
unnamed: R7.1, TEENSY1.36 (14_A0_TX3_SPDIF_OUT)
unnamed: R9.1, TEENSY1.16 (24_A10_TX6_SCL2)
unnamed: R11.1, TEENSY1.21 (29_TX7)
unnamed: R6.1, TEENSY1.27 (35_TX8)
unnamed: G1.1, TEENSY1.30 (38_CS1_IN1)
unnamed: SW1.B, TEENSY1.31 (39_MISO1_OUT1A)
unnamed: SW1.A, TEENSY1.32 (40_A16)
unnamed: SW1.S1, TEENSY1.33 (41_A17)
unnamed: C1.1, C2.1, TEENSY1.48 (VIN), U2.8 (VCC), U3.8 (VCC)
unnamed: TEENSY1.57 (D+), USB1.3 (D+)
unnamed: TEENSY1.56 (D-), USB1.2 (D-)
VCC: OLED1.2, R1.2, R2.2, R5.1, R8.1, R10.1, R12.1, R14.1, R16.1, TEENSY1.46 (3V3)

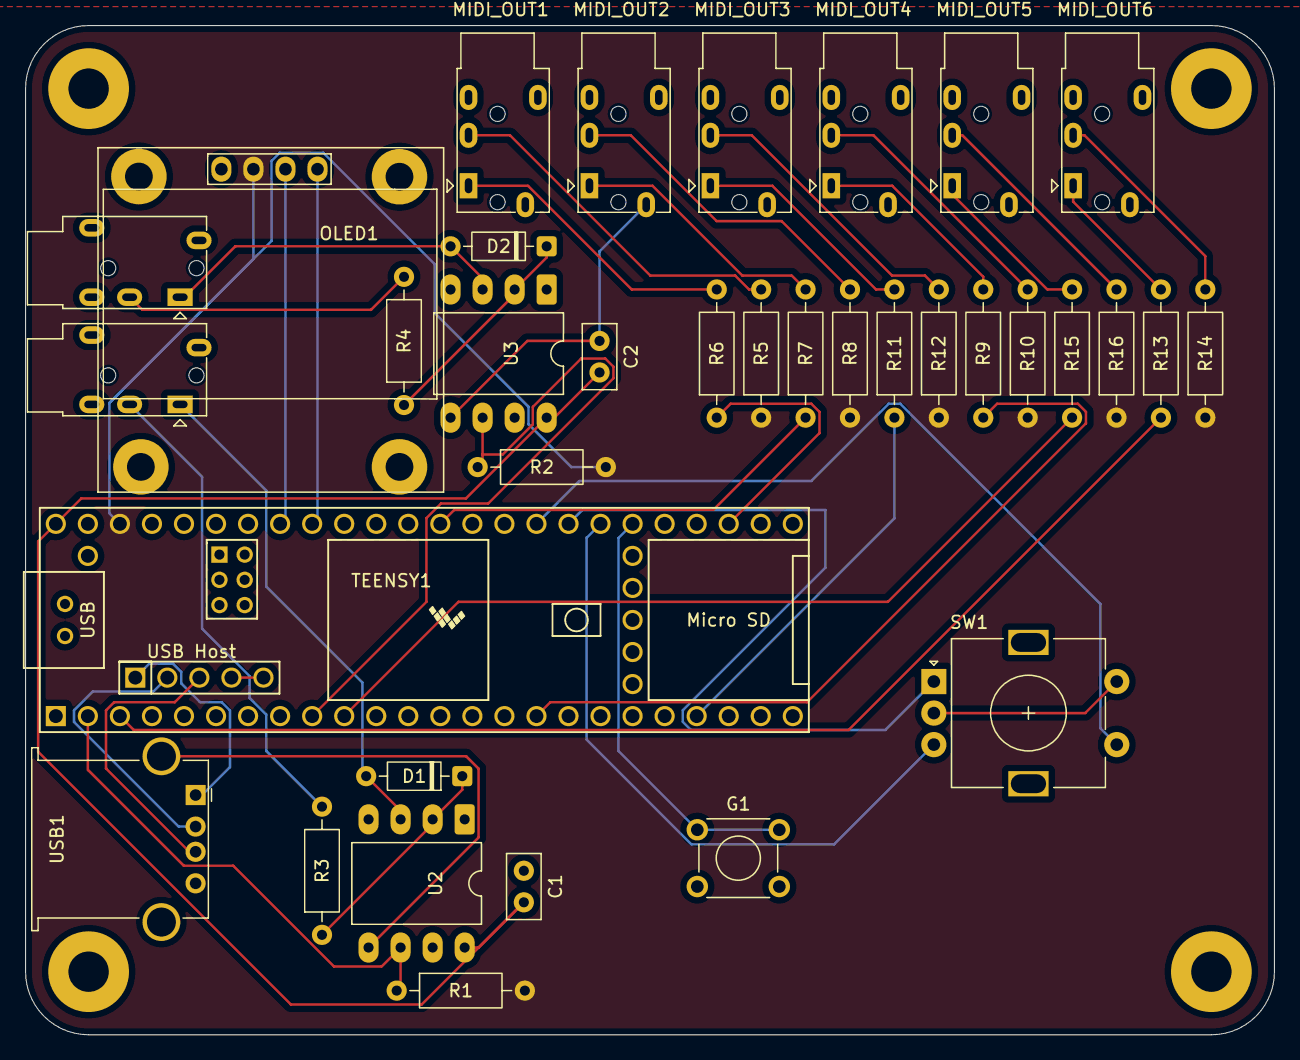
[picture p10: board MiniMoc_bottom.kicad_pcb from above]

Board: 2 copper layers, 99.0 x 80.0 mm, 35 parts (0 on the bottom side), 38 nets.

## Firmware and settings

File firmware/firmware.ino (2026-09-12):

#define FIRMWARE_VERSION "v0.5.2"

// Décommenter pour activer l'enregistrement MIDI continu en tâche de fond sur
// carte SD (+ MTP). Désactivé : sd_tick() et MTP ne tournent pas → latence
// réduite, sync plus stable. Le montage SD et les presets restent actifs
// dans tous les cas (voir sd_setup() dans sd_recorder.h).
//#define SD_RECORDER_ENABLED

#define MIDIA MIDIA_5
#define MIDI5 MIDIA_5

#define MIDIB MIDIB_6
#define MIDI6 MIDIB_6


// DEBUG LED
void traceLED() {
      digitalWrite(LED_BUILTIN, HIGH); // Allume la LED de la Teensy
      delay(100);
      digitalWrite(LED_BUILTIN, LOW);  // Éteint la LED      
}

#include <U8g2lib.h>
#include <Wire.h>
#include <string.h> 
#include <EEPROM.h> 
#include <MIDI.h>
#include <USBHost_t36.h>
#include <MTP_Teensy.h>

#include "graphics.h"
#include "logic.h"
#include "harmony.h"       // TRANS_CHORD_HARMONIZE — après logic.h (FluxTransform), avant monitor.h/_midi.h/routing_submenu.h
#include "monitor.h"       // données VU-mètre — doit précéder sd_recorder (mon_push appelé dans rec_push)
#include "sd_recorder.h"   // déclare sd, sd_ok — doit précéder sd_presets et preset
#include "sd_presets.h"    // sd_preset_save/load/exists, SD_PRESET_MAX
#include "sd_mtp_adapter.h"

#ifdef SD_RECORDER_ENABLED
SdFsAdapter sd_mtp_fs;
#endif

#include "preset.h"        // silent_save/load_preset — après sd_presets
#include "_midi.h"
#include "generators.h"    // generators_tick() — après _midi.h (utilise generators_send_cc)
#include "PCEditor.h"
#include "ota.h"

// --- New carousel UI (replaces menu.h) ---
#include "carousel_ui.h"
#include "generators_submenu.h"   // avant routing_submenu.h (RS_GENERATORS y délègue via gs_*)
#include "routing_submenu.h"
#include "preset_submenu.h"
#include "info_submenu.h"
#include "monitor_submenu.h"
#include "usb_host_config.h"   // après _midi.h (MIDIUSB1/2/3) et carousel_ui.h (UI_FONT_*)
#include "sync_submenu.h"      // après usb_host_config.h (utilise hc_dev_name)
#include "system_submenu.h"    // après info_submenu.h et usb_host_config.h
#include "transport_submenu.h" // après logic.h (internal_clock_bpm) et carousel_ui.h (UI_FONT_*)
#include "controls.h"   // must come after carousel_ui.h (uses u8g2)


// -----------------------------------------------------------------
// J. SETUP ET LOOP
// -----------------------------------------------------------------

void setup() {

  ota_setup();   // USB CDC + TeensyOTA — avant toute autre init

// pour effacer l'eeprom en cas de changement de structure
// for (int i = 0 ; i < 4096 ; i++) {
//    EEPROM.write(i, 0);
//}

// 1024 octets de buffer au lieu de 1k pour éviter les pertes éventuelles de packets
Serial1.addMemoryForRead(new uint8_t[1024], 1024); // On passe de 64 à 1024 octets !
Serial2.addMemoryForRead(new uint8_t[1024], 1024); // On passe de 64 à 1024 octets !


#ifdef DEBUG
  Serial.begin(115200);
#endif

  // On écoute le port USB relié au PC (pour éditeur web sur le PC)
  usbMIDI.setHandleSystemExclusive(handleEditorSysex);

  // MIDI
  MIDI1.begin();
  MIDI2.begin();
  MIDI3.begin();
  MIDI4.begin();
  MIDI5.begin(MIDI_CHANNEL_OMNI);
  MIDI6.begin(MIDI_CHANNEL_OMNI);

  MIDIA.turnThruOff();
  MIDIB.turnThruOff();

  MIDIA.setHandleNoteOn(handleNoteOnA);
  MIDIA.setHandleNoteOff(handleNoteOffA);
  MIDIA.setHandleControlChange(handleControlChangeA);
  MIDIA.setHandleProgramChange(handleProgramChangeA);
  
// Port A utilise les versions "A"
  MIDIA.setHandlePitchBend(handlePitchBendA);
  MIDIA.setHandleAfterTouchChannel(handleAfterTouchA);

  // Port B utilise les versions "B"
  MIDIB.setHandlePitchBend(handlePitchBendB);
  MIDIB.setHandleAfterTouchChannel(handleAfterTouchB);

  MIDIB.setHandleNoteOn(handleNoteOnB);
  MIDIB.setHandleNoteOff(handleNoteOffB);
  MIDIB.setHandleControlChange(handleControlChangeB);
  MIDIB.setHandleProgramChange(handleProgramChangeB);

  // USB HOST — callbacks real-time (clock/transport) pour le maître SYNC
  MIDIUSB1.setHandleRealTimeSystem(handleRT_dev0);
  MIDIUSB2.setHandleRealTimeSystem(handleRT_dev1);
  MIDIUSB3.setHandleRealTimeSystem(handleRT_dev2);
  MIDIUSB4.setHandleRealTimeSystem(handleRT_dev3);
  MIDIUSB5.setHandleRealTimeSystem(handleRT_dev4);
  MIDIUSB6.setHandleRealTimeSystem(handleRT_dev5);

  // USB HOST — callbacks dynamiques par slot (port_slot[] détermine le rôle)
  MIDIUSB1.setHandleNoteOn(handleNoteOn_dev0);
  MIDIUSB1.setHandleNoteOff(handleNoteOff_dev0);
  MIDIUSB1.setHandleControlChange(handleCC_dev0);
  MIDIUSB1.setHandleProgramChange(handlePC_dev0);
  MIDIUSB1.setHandlePitchChange(handlePB_dev0);
  MIDIUSB1.setHandleAfterTouchChannel(handleAT_dev0);

  MIDIUSB2.setHandleNoteOn(handleNoteOn_dev1);
  MIDIUSB2.setHandleNoteOff(handleNoteOff_dev1);
  MIDIUSB2.setHandleControlChange(handleCC_dev1);
  MIDIUSB2.setHandleProgramChange(handlePC_dev1);
  MIDIUSB2.setHandlePitchChange(handlePB_dev1);
  MIDIUSB2.setHandleAfterTouchChannel(handleAT_dev1);

  MIDIUSB3.setHandleNoteOn(handleNoteOn_dev2);
  MIDIUSB3.setHandleNoteOff(handleNoteOff_dev2);
  MIDIUSB3.setHandleControlChange(handleCC_dev2);
  MIDIUSB3.setHandleProgramChange(handlePC_dev2);
  MIDIUSB3.setHandlePitchChange(handlePB_dev2);
  MIDIUSB3.setHandleAfterTouchChannel(handleAT_dev2);

  MIDIUSB4.setHandleNoteOn(handleNoteOn_dev3);
  MIDIUSB4.setHandleNoteOff(handleNoteOff_dev3);
  MIDIUSB4.setHandleControlChange(handleCC_dev3);
  MIDIUSB4.setHandleProgramChange(handlePC_dev3);
  MIDIUSB4.setHandlePitchChange(handlePB_dev3);
  MIDIUSB4.setHandleAfterTouchChannel(handleAT_dev3);

  MIDIUSB5.setHandleNoteOn(handleNoteOn_dev4);
  MIDIUSB5.setHandleNoteOff(handleNoteOff_dev4);
  MIDIUSB5.setHandleControlChange(handleCC_dev4);
  MIDIUSB5.setHandleProgramChange(handlePC_dev4);
  MIDIUSB5.setHandlePitchChange(handlePB_dev4);
  MIDIUSB5.setHandleAfterTouchChannel(handleAT_dev4);

  MIDIUSB6.setHandleNoteOn(handleNoteOn_dev5);
  MIDIUSB6.setHandleNoteOff(handleNoteOff_dev5);
  MIDIUSB6.setHandleControlChange(handleCC_dev5);
  MIDIUSB6.setHandleProgramChange(handlePC_dev5);
  MIDIUSB6.setHandlePitchChange(handlePB_dev5);
  MIDIUSB6.setHandleAfterTouchChannel(handleAT_dev5);

  // Pool USB aligné sur le sketch testHOST (config validée stable en hot-plug).
  static Pipe_t     usb_extra_pipes[12] __attribute__((aligned(32)));
  static Transfer_t usb_extra_xfr[48]  __attribute__((aligned(32)));
  myusb.contribute_Pipes(usb_extra_pipes, 12);
  myusb.contribute_Transfers(usb_extra_xfr, 48);

  myusb.begin();

  // Pins et OLED
  selectButton.attach(PIN_VALID, INPUT_PULLUP);
  selectButton.interval(5);
  backButton.attach(PIN_BACK, INPUT_PULLUP);
  backButton.interval(5);
  pinMode(LED_BUILTIN, OUTPUT);   // flash à chaque temps du maître SYNC (voir bpm_push_clock)
  digitalWrite(LED_BUILTIN, LOW);
  Wire.begin();
  Wire.setClock(1000000);  // 1 MHz (Fast-mode Plus) : réduit sendBuffer ~20ms→~8ms — revenir à 400000 si artefacts OLED
  u8g2.begin();
  u8g2.sendF("ca", 0xD5, 0xF0);   // oscillateur SSD1306 au max (défaut 0x80)

  // --- Carousel principal : PRESET / SYNC / ROUTAGE / MONITOR / SYSTEM / TRANSPORT ---
  carousel_register("PRESET",    icon_preset_16,   icon_preset_32,   NULL);
  carousel_register("SYNC",      icon_sync_16,     icon_sync_32,     NULL);
  carousel_register("ROUTAGE",   icon_routing_16,  icon_routing_32,  NULL);
  carousel_register("MONITOR",   icon_monitor_16,  icon_monitor_32,  NULL);
  carousel_register("SYSTEM",    icon_info_16,     icon_info_32,     NULL);
  carousel_register("TRANSPORT", icon_sync_16,     icon_sync_32,     NULL);  // icône réutilisée (horloge) — à remplacer si besoin

  // Montage SD + presets : toujours actif, indépendant de SD_RECORDER_ENABLED
  // (qui ne contrôle que l'enregistrement MIDI continu, voir sd_recorder.h)
  sd_setup();
  if (sd_ok) {
    sd_preset_init();
#ifdef SD_RECORDER_ENABLED
    sd_mtp_fs.init(sd);
    MTP.addFilesystem(sd_mtp_fs, "MiniMoc SD");
#endif
  }
#ifdef SD_RECORDER_ENABLED
  MTP.begin();
#endif

  hc_load();       // Restaure assignation USB Host + état LOCK depuis EEPROM
  sync_load();     // Restaure le maître SYNC depuis EEPROM
  contrast_load(); contrast_apply(); // Restaure le contraste OLED depuis EEPROM
  bpm_refresh_load();  // Restaure l'intervalle de rafraîchissement BPM depuis EEPROM
  internal_clock_bpm_load();  // Restaure le tempo de l'horloge interne MiniMoc depuis EEPROM
  internal_clock_apply();     // Démarre le timer si MiniMoc était déjà le maître SYNC sauvegardé

  // Chargement du dernier preset actif depuis la SD
  uint8_t stored_preset = 0;
  EEPROM.get(ACTIVE_PRESET_ADDR, stored_preset);
  if (stored_preset >= 1 && stored_preset <= MAX_PRESETS) {
    current_preset = stored_preset;
    silent_load_preset();   // silencieux si preset absent ou SD indisponible
    recompute_route_matrix(); // recalcule route_matrix depuis basic_matrix + flux_list
  } else {
    current_preset = 1;
  }

  // Démarrage du mode interactif ou pas
  delay(10);
  if (digitalRead(PIN_BACK) == LOW) {
    modeInteractif = true;
  } else {
    oldPosition = myEnc.read();   // sync encodeur avant d'afficher le logo
    afficherLogoVerveine();
  }
}

void loop() {

  ota_tick();            // vérifie Serial sans bloquer ; bloque seulement pendant un transfert OTA actif
  bpm_tick();            // recalcule bpm_value à période fixe, indépendamment de l'affichage
  bpm_led_tick();        // éteint la LED de temps après BPM_LED_BLINK_MS (à chaque loop pour une durée précise)
  internal_clock_flush_usb(); // relaie vers les sorties USB Host le Clock généré par l'ISR du timer
  generators_tick(millis());  // sert les LFO (mode libre + envoi CC) — actif même écran éteint

int buttonState = digitalRead(PIN_BACK);

  // ── Réveil depuis le mode logo ────────────────────────────────
  // Toute action (BACK, VALID ou rotation encodeur) sort du logo.
  // On attend d'abord que les touches soient relâchées (cas du retour
  // au logo via appui long : le bouton est encore tenu à ce moment).
  static bool logo_wait_release = false;

  if (!modeInteractif) {
    if (logo_wait_release) {
      // Attendre relâchement complet avant d'autoriser le réveil
      if (buttonState == HIGH && digitalRead(PIN_VALID) == HIGH)
        logo_wait_release = false;
    } else {
      bool wake = (buttonState == LOW) || (digitalRead(PIN_VALID) == LOW);
      if (!wake) {
        long newEnc = myEnc.read();
        if (newEnc != oldPosition) { oldPosition = newEnc; wake = true; }
      }
      if (wake) {
        modeInteractif = true;
        carousel_draw_frame(carousel_anim_offset);
      }
    }
  }

  // ── Appui long BACK → bascule vers le logo ────────────────────
  // Désactivé sur l'écran TRANSPORT : BACK y sert à chorder avec l'encodeur
  // (RECORD/AVANCE/REWIND), ce qui dépasse facilement longPressDuration.
  if (buttonState == LOW && ui_screen != UI_TRANSPORT) {
    if (buttonPressStartTime == 0) {
      buttonPressStartTime = millis();
    }
    if (millis() - buttonPressStartTime > longPressDuration) {
      modeInteractif = !modeInteractif;
      if (!modeInteractif) {
        oldPosition = myEnc.read();
        logo_wait_release = true;   // attendre relâchement avant réveil
        afficherLogoVerveine();
      }
      buttonPressStartTime = 0;
    }
  } else {
    buttonPressStartTime = 0;
  }

  if (modeInteractif) {
    static unsigned long lastUI = 0;
    if (millis() - lastUI > 50) {
      lastUI = millis();
      ui_tick();
    }
  }

  // test d'un msg MIDI sur entrée A
  if (MIDIA.read()) {
    byte msgType = MIDIA.getType();

    // Forward Real-Time (clock/transport) — uniquement si port A est le maître SYNC
    if (msgType == midi::Start || msgType == midi::Stop || msgType == midi::Continue ||
        msgType == midi::Clock || msgType == midi::ActiveSensing || msgType == midi::SystemReset) {
      if (sync_master == 0) _sync_forward(msgType);
      // si sync_master != 0 (autre maître ou OFF) : filtré
    }

    usbMIDI.send(MIDIA.getType(), MIDIA.getData1(), MIDIA.getData2(),
                 MIDIA.getChannel(), USB_PORT_A);
  }

  if (MIDIB.read()) {
    byte msgType = MIDIB.getType();

    if (msgType == midi::Start || msgType == midi::Stop || msgType == midi::Continue ||
        msgType == midi::Clock || msgType == midi::ActiveSensing || msgType == midi::SystemReset) {
      if (sync_master == 1) _sync_forward(msgType);
      // si sync_master != 1 (autre maître ou OFF) : filtré
    }
    
    // On le renvoie vers le Port USB 
    usbMIDI.send(MIDIB.getType(), 
                 MIDIB.getData1(), 
                 MIDIB.getData2(), 
                 MIDIB.getChannel(), 
                 USB_PORT_B); // <--- Le chiffre 1 est le port USB
  }



  myusb.Task();
  MIDIUSB1.read();
  MIDIUSB2.read();
  MIDIUSB3.read();
  MIDIUSB4.read();
  MIDIUSB5.read();
  MIDIUSB6.read();
  hc_poll();   // détecte connexions/déconnexions pour le LOCK VID:PID

  // Second appel myusb.Task() avant les opérations bloquantes (sd_tick ~1-3ms,
  // MTP.loop variable) pour que le hub ne manque pas ses interrupts de port.
  // Sans ça, le gap entre deux Task() peut dépasser le bInterval du hub (~8ms).
  myusb.Task();
  MIDIUSB1.read(); MIDIUSB2.read(); MIDIUSB3.read();
  MIDIUSB4.read(); MIDIUSB5.read(); MIDIUSB6.read();

  // Lecture de tous les messages USB depuis le PC
  // usbMIDI.read() sans argument lit le prochain message quel que soit le câble.
  // usbMIDI.getCable() retourne ensuite le numéro de câble USB pour dispatcher.
  // Note: usbMIDI.read(n) filtre par canal MIDI (pas par câble) — ne pas utiliser pour ça.
#ifdef SD_RECORDER_ENABLED
  sd_tick();
  // MTP : accès SD depuis le PC — après sd_tick() pour donner priorité aux écritures
  if (sd_ok) MTP.loop();
#endif

  while (usbMIDI.read()) {
    byte cable = usbMIDI.getCable();
    byte type  = usbMIDI.getType();
    byte ch    = usbMIDI.getChannel();
    byte d1    = usbMIDI.getData1();
    byte d2    = usbMIDI.getData2();

    if (cable == USB_PORT_A) {                   // câble 1 — Entrée A
      switch (type) {
        case midi::NoteOn:            handleNoteOn(1, ch, d1, d2, SRC_PC); break;
        case midi::NoteOff:           handleNoteOff(1, ch, d1, d2, SRC_PC); break;
        case midi::ControlChange:     handleControlChange(1, ch, d1, d2, SRC_PC); break;
        case midi::ProgramChange:     handleProgramChange(1, ch, d1, SRC_PC); break;
        case midi::PitchBend:         processPitchBend(0, ch, (int)(((int)d2 << 7) | d1) - 8192, SRC_PC); break;
        case midi::AfterTouchChannel: processAfterTouch(0, ch, d1, SRC_PC); break;
        case midi::Clock: case midi::Start: case midi::Stop:
        case midi::Continue: case midi::ActiveSensing: case midi::SystemReset:
          if (sync_master == 5) _sync_forward(type); break;   // 5 = A (USB/PC)
      }
    } else if (cable == USB_PORT_B) {            // câble 2 — Entrée B
      switch (type) {
        case midi::NoteOn:            handleNoteOn(2, ch, d1, d2, SRC_PC); break;
        case midi::NoteOff:           handleNoteOff(2, ch, d1, d2, SRC_PC); break;
        case midi::ControlChange:     handleControlChange(2, ch, d1, d2, SRC_PC); break;
        case midi::ProgramChange:     handleProgramChange(2, ch, d1, SRC_PC); break;
        case midi::PitchBend:         processPitchBend(1, ch, (int)(((int)d2 << 7) | d1) - 8192, SRC_PC); break;
        case midi::AfterTouchChannel: processAfterTouch(1, ch, d1, SRC_PC); break;
        case midi::Clock: case midi::Start: case midi::Stop:
        case midi::Continue: case midi::ActiveSensing: case midi::SystemReset:
          if (sync_master == 6) _sync_forward(type); break;   // 6 = B (USB/PC)
      }
    } else if (cable == USB_IN_C) {               // câble 3 — Entrée C
      switch (type) {
        case midi::NoteOn:            handleNoteOn(3, ch, d1, d2, SRC_PC); break;
        case midi::NoteOff:           handleNoteOff(3, ch, d1, d2, SRC_PC); break;
        case midi::ControlChange:     handleControlChange(3, ch, d1, d2, SRC_PC); break;
        case midi::ProgramChange:     handleProgramChange(3, ch, d1, SRC_PC); break;
        case midi::PitchBend:         processPitchBend(2, ch, (int)(((int)d2 << 7) | d1) - 8192, SRC_PC); break;
        case midi::AfterTouchChannel: processAfterTouch(2, ch, d1, SRC_PC); break;
        case midi::Clock: case midi::Start: case midi::Stop:
        case midi::Continue: case midi::ActiveSensing: case midi::SystemReset:
          if (sync_master == 7) _sync_forward(type); break;   // 7 = C (USB/PC)
      }
    } else if (cable == USB_IN_D) {               // câble 4 — Entrée D
      switch (type) {
        case midi::NoteOn:            handleNoteOn(4, ch, d1, d2, SRC_PC); break;
        case midi::NoteOff:           handleNoteOff(4, ch, d1, d2, SRC_PC); break;
        case midi::ControlChange:     handleControlChange(4, ch, d1, d2, SRC_PC); break;
        case midi::ProgramChange:     handleProgramChange(4, ch, d1, SRC_PC); break;
        case midi::PitchBend:         processPitchBend(3, ch, (int)(((int)d2 << 7) | d1) - 8192, SRC_PC); break;
        case midi::AfterTouchChannel: processAfterTouch(3, ch, d1, SRC_PC); break;
        case midi::Clock: case midi::Start: case midi::Stop:
        case midi::Continue: case midi::ActiveSensing: case midi::SystemReset:
          if (sync_master == 8) _sync_forward(type); break;   // 8 = D (USB/PC)
      }
    } else if (cable >= USB_OUT_1 && cable <= USB_OUT_6) {  // câbles 6-11 — Sorties physiques 1-6
      switch (cable - (USB_OUT_1 - 1)) {
        case 1: MIDI1.send(type, d1, d2, ch); break;
        case 2: MIDI2.send(type, d1, d2, ch); break;
        case 3: MIDI3.send(type, d1, d2, ch); break;
        case 4: MIDI4.send(type, d1, d2, ch); break;
        case 5: MIDI5.send(type, d1, d2, ch); break;
        case 6: MIDI6.send(type, d1, d2, ch); break;
      }
    } else if (cable == USB_OUT_7) {              // câble 11 — Sortie 7 direct
      { MIDIDevice_BigBuffer* _d = _usb_out_dev(0); if (_d && (bool)*_d) switch (type) {
        case midi::NoteOn:            _d->sendNoteOn(d1, d2, ch); break;
        case midi::NoteOff:           _d->sendNoteOff(d1, d2, ch); break;
        case midi::ControlChange:     _d->sendControlChange(d1, d2, ch); break;
        case midi::ProgramChange:     _d->sendProgramChange(d1, ch); break;
        case midi::PitchBend:         _d->sendPitchBend((int)(((int)d2 << 7) | d1) - 8192, ch); break;
        case midi::AfterTouchChannel: _d->sendAfterTouch(d1, ch); break;
      } }
    } else if (cable == USB_OUT_8) {              // câble 12 — Sortie 8 direct
      { MIDIDevice_BigBuffer* _d = _usb_out_dev(1); if (_d && (bool)*_d) switch (type) {
        case midi::NoteOn:            _d->sendNoteOn(d1, d2, ch); break;
        case midi::NoteOff:           _d->sendNoteOff(d1, d2, ch); break;
        case midi::ControlChange:     _d->sendControlChange(d1, d2, ch); break;
        case midi::ProgramChange:     _d->sendProgramChange(d1, ch); break;
        case midi::PitchBend:         _d->sendPitchBend((int)(((int)d2 << 7) | d1) - 8192, ch); break;
        case midi::AfterTouchChannel: _d->sendAfterTouch(d1, ch); break;
      } }
    } else if (cable == USB_IN_E) {               // câble 13 — Entrée E
      switch (type) {
        case midi::NoteOn:            handleNoteOn(5, ch, d1, d2, SRC_PC); break;
        case midi::NoteOff:           handleNoteOff(5, ch, d1, d2, SRC_PC); break;
        case midi::ControlChange:     handleControlChange(5, ch, d1, d2, SRC_PC); break;
        case midi::ProgramChange:     handleProgramChange(5, ch, d1, SRC_PC); break;
        case midi::PitchBend:         processPitchBend(4, ch, (int)(((int)d2 << 7) | d1) - 8192, SRC_PC); break;
        case midi::AfterTouchChannel: processAfterTouch(4, ch, d1, SRC_PC); break;
        case midi::Clock: case midi::Start: case midi::Stop:
        case midi::Continue: case midi::ActiveSensing: case midi::SystemReset:
          if (sync_master == 9) _sync_forward(type); break;   // 9 = E (USB/PC)
      }
    } else if (cable == USB_OUT_9) {              // câble 14 — Sortie 9 direct
      { MIDIDevice_BigBuffer* _d = _usb_out_dev(2); if (_d && (bool)*_d) switch (type) {
        case midi::NoteOn:            _d->sendNoteOn(d1, d2, ch); break;
        case midi::NoteOff:           _d->sendNoteOff(d1, d2, ch); break;
        case midi::ControlChange:     _d->sendControlChange(d1, d2, ch); break;
        case midi::ProgramChange:     _d->sendProgramChange(d1, ch); break;
        case midi::PitchBend:         _d->sendPitchBend((int)(((int)d2 << 7) | d1) - 8192, ch); break;
        case midi::AfterTouchChannel: _d->sendAfterTouch(d1, ch); break;
      } }
    }
    // câble 0 : éditeur SysEx — déjà géré par le callback handleEditorSysex
  }








}

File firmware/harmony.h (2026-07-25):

#pragma once
// harmony.h — Harmonisation d'accords en temps réel (TRANS_CHORD_HARMONIZE)
//
// Principe : au lieu d'un décalage fixe (TRANS_NOTE_TRANSPOSE) ou d'un
// empilement d'intervalles fixes (TRANS_HARMONIZE), ce transform recalcule à
// chaque note un décalage qui dépend de l'accord actuellement actif dans une
// progression (I-V-vi-IV, ii7-V7-Imaj7, ...) et de sa nature (majeur, mineur,
// 7e) — la note reçue est réinterprétée comme un degré de la gamme fondamentale
// puis reprojetée sur la gamme de l'accord courant (Ionien/Éolien/Dorien/
// Mixolydien selon la nature), pas juste transposée dans la gamme d'origine.
//
// Exemple (fondamentale Do, accord Ré majeur) : motif Do-Ré-Fa-Mi-Sol donne
// Ré-Mi-Sol-Fa#-La — le Fa devient Fa# car c'est la tierce de l'accord de Ré
// majeur (Ionien sur Ré), pas un décalage uniforme de +2 demi-tons.
//
// Inclus dans firmware.ino juste après logic.h (a besoin de FluxTransform) et
// avant monitor.h/_midi.h/routing_submenu.h (qui appellent les fonctions ici).

// -----------------------------------------------------------------
// Gammes — demi-tons depuis la tonique/racine, degrés I à VII
// -----------------------------------------------------------------
static const int8_t MAJOR_SCALE_STEPS[7]  = {0,2,4,5,7,9,11};   // gamme de la FONDAMENTALE (Ionien)
static const int8_t HARMONY_IONIAN[7]     = {0,2,4,5,7,9,11};   // accord majeur, maj7
static const int8_t HARMONY_AEOLIAN[7]    = {0,2,3,5,7,8,10};   // accord mineur (triade)
static const int8_t HARMONY_DORIAN[7]     = {0,2,3,5,7,9,10};   // accord mineur 7e
static const int8_t HARMONY_MIXOLYDIAN[7] = {0,2,4,5,7,9,10};   // accord dominante 7e

enum ChordQuality : uint8_t {
    CHORD_MAJOR = 0,
    CHORD_MINOR,
    CHORD_MIN7,
    CHORD_DOM7,
    CHORD_MAJ7,
};

static inline const int8_t* _harmony_quality_scale(uint8_t quality) {
    switch (quality) {
        case CHORD_MINOR: return HARMONY_AEOLIAN;
        case CHORD_MIN7:  return HARMONY_DORIAN;
        case CHORD_DOM7:  return HARMONY_MIXOLYDIAN;
        default:          return HARMONY_IONIAN;   // CHORD_MAJOR, CHORD_MAJ7
    }
}

// -----------------------------------------------------------------
// Progressions prédéfinies — degré (1-7) + nature de chaque accord
// -----------------------------------------------------------------
struct ChordDef { uint8_t degree; uint8_t quality; };   // degree : 1-7 (I..VII)

#define PROGRESSION_MAX_CHORDS 8   // le plus long preset (Canon de Pachelbel) en a 8
#define PROGRESSION_COUNT 10

struct ProgressionPreset {
    const char* name;         // libellé complet (affichage weblink)
    const char* short_label;  // libellé compact, tronqué avec "..." si besoin (écran OLED 128px)
    uint8_t     length;       // nb d'accords actifs
    ChordDef    chords[PROGRESSION_MAX_CHORDS];
};

// NB : les libellés complets (weblink) et une description par progression
// sont dupliqués côté weblink/index.html (PROGRESSION_LABELS/PROGRESSION_DESCRIPTIONS)
// — pas de dépendance runtime entre le firmware et le JS, juste à garder synchro
// si cette liste évolue encore.
static const ProgressionPreset PROGRESSION_PRESETS[PROGRESSION_COUNT] = {
    { "I - V - vi - IV",                  "I-V-vi-IV",         4,
      { {1,CHORD_MAJOR}, {5,CHORD_MAJOR}, {6,CHORD_MINOR}, {4,CHORD_MAJOR} } },
    { "ii7 - V7 - Imaj7",                 "ii7-V7-Imaj7",      3,
      { {2,CHORD_MIN7},  {5,CHORD_DOM7},  {1,CHORD_MAJ7},  {0,CHORD_MAJOR} } },
    { "I - vi - IV - V",                  "I-vi-IV-V",         4,
      { {1,CHORD_MAJOR}, {6,CHORD_MINOR}, {4,CHORD_MAJOR}, {5,CHORD_MAJOR} } },
    { "vi - IV - I - V",                  "vi-IV-I-V",         4,
      { {6,CHORD_MINOR}, {4,CHORD_MAJOR}, {1,CHORD_MAJOR}, {5,CHORD_MAJOR} } },
    { "I - IV - V",                       "I-IV-V",            3,
      { {1,CHORD_MAJOR}, {4,CHORD_MAJOR}, {5,CHORD_MAJOR} } },
    { "I - IV - vi - V",                  "I-IV-vi-V",         4,
      { {1,CHORD_MAJOR}, {4,CHORD_MAJOR}, {6,CHORD_MINOR}, {5,CHORD_MAJOR} } },
    { "vi7 - ii7 - V7 - Imaj7",           "vi7-ii7-V7-Imaj7",  4,
      { {6,CHORD_MIN7},  {2,CHORD_MIN7},  {5,CHORD_DOM7},  {1,CHORD_MAJ7} } },
    { "Imaj7 - vi7 - ii7 - V7",           "Imaj7-vi7-ii7-V7",  4,
      { {1,CHORD_MAJ7},  {6,CHORD_MIN7},  {2,CHORD_MIN7},  {5,CHORD_DOM7} } },
    { "I7 - IV7 - V7",                    "I7-IV7-V7",         3,
      { {1,CHORD_DOM7},  {4,CHORD_DOM7},  {5,CHORD_DOM7} } },
    { "I - V - vi - iii - IV - I - IV - V", "I-V-vi-iii-IV-...", 8,
      { {1,CHORD_MAJOR}, {5,CHORD_MAJOR}, {6,CHORD_MINOR}, {3,CHORD_MINOR},
        {4,CHORD_MAJOR}, {1,CHORD_MAJOR}, {4,CHORD_MAJOR}, {5,CHORD_MAJOR} } },
};

// -----------------------------------------------------------------
// Toniques — libellés français (Do=0 .. Si=11)
// -----------------------------------------------------------------
static const char* ROOT_KEY_LABELS[12] = {
    "Do","Do#","Ré","Ré#","Mi","Fa","Fa#","Sol","Sol#","La","La#","Si"
};

#define CHORD_BARS_MIN     1
#define CHORD_BARS_MAX     8
#define CHORD_BARS_DEFAULT 1

// -----------------------------------------------------------------
// Compteur de mesure global — avance sur l'horloge MIDI (temps réel ou
// interne), remis à zéro sur Start/Continue. Un seul compteur partagé par
// tous les Flux TRANS_CHORD_HARMONIZE : chacun dérive son accord courant
// statelessement à partir de ce compteur + de sa propre config
// (progression_id, bars_per_chord) — aucun état par-Flux à maintenir.
// -----------------------------------------------------------------
static uint32_t harmony_bar_ctr         = 0;   // mesures écoulées depuis Start/Continue
static uint8_t  harmony_beat_in_bar_ctr = 0;   // 0-3, position dans la mesure 4/4 courante

// Appelé depuis bpm_push_clock() (monitor.h) à chaque temps complet (24 ticks
// MIDI Clock). Ne touche que 2 entiers → sûr à appeler depuis l'ISR de
// l'horloge interne (internal_clock_isr() dans _midi.h).
inline void harmony_on_beat() {
    if (++harmony_beat_in_bar_ctr >= 4) {
        harmony_beat_in_bar_ctr = 0;
        harmony_bar_ctr++;
    }
}

// Appelé depuis bpm_reset_beat() (monitor.h), sur Start/Continue.
inline void harmony_on_transport_reset() {
    harmony_bar_ctr         = 0;
    harmony_beat_in_bar_ctr = 0;
}

// Accord actif pour un FluxTransform donné, dérivé du compteur de mesure global.
static inline ChordDef harmony_current_chord(const FluxTransform& tr) {
    uint8_t prog = (tr.progression_id < PROGRESSION_COUNT) ? tr.progression_id : 0;
    uint8_t plen = PROGRESSION_PRESETS[prog].length;
    uint8_t bpc  = (tr.bars_per_chord >= CHORD_BARS_MIN) ? tr.bars_per_chord : CHORD_BARS_DEFAULT;   // garde-fou div/0
    uint32_t idx = (harmony_bar_ctr / bpc) % plen;
    return PROGRESSION_PRESETS[prog].chords[idx];
}
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

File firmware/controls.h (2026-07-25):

#pragma once
#include <Encoder.h>
#include <Bounce2.h>

// Encoder on pins 39/40, click button on 41, back button on 38
Encoder myEnc(40, 39);
Bounce  selectButton = Bounce();
Bounce  backButton   = Bounce();
long    oldPosition  = -999;

unsigned long buttonPressStartTime = 0;
const int     longPressDuration    = 1000;

bool modeInteractif = false;

const int PIN_BACK  = 38;
const int PIN_VALID = 41;

const long    DEBOUNCE_DELAY_MS  = 150;
unsigned long last_debounce_time = 0;

// Encoder: one step accepted per ENC_DEBOUNCE_MS regardless of pulse count
static const unsigned long ENC_DEBOUNCE_MS = 120;
static unsigned long       last_enc_time   = 0;

// Encodeur différé : l'event n'est appliqué qu'après ENC_APPLY_MS sans clic.
// Si un clic survient dans ce délai, l'event est annulé (rotation mécanique parasite).
static const unsigned long ENC_APPLY_MS = 60;
static int8_t    enc_pending    = 0;   // 0=rien  +1=down  -1=up
static uint32_t  enc_pending_ms = 0;

// -----------------------------------------------------------------
// TOP-LEVEL UI STATE
// -----------------------------------------------------------------

enum UIScreen {
  UI_CAROUSEL,     // main carousel selector
  UI_PRESETS,      // preset sub-menu
  UI_SYNC,         // sync sub-menu
  UI_ROUTING,      // routing sub-menu (inclut GENERATEURS — voir routing_submenu.h/RS_GENERATORS)
  UI_MONITOR,      // moniteur VU-mètre temps réel
  UI_SYSTEM,       // system sub-menu (INFO + HOST CONFIG)
  UI_TRANSPORT,    // tempo de l'horloge interne MiniMoc (source MINIMOC du menu SYNC)
};

static UIScreen ui_screen = UI_CAROUSEL;

// -----------------------------------------------------------------
// INPUT SAMPLING — returns raw button state this tick
// -----------------------------------------------------------------

struct InputState {
  bool enc_up;
  bool enc_down;
  bool btn_valid;
  bool btn_back;        // front (une seule fois par appui) — "remonter d'un niveau" pour la plupart des écrans
  bool btn_held;        // état brut (debounced) du bouton VALID, indépendant du front de clic
  bool btn_back_held;   // état continu (debounced) du bouton BACK — gestes chordés de l'écran TRANSPORT
};

static InputState read_inputs() {
  InputState s = {false, false, false, false, false, false};

  long newPos = myEnc.read();
  long diff   = newPos - oldPosition;
  unsigned long now = millis();

  if (diff != 0) {
    oldPosition = newPos;  // toujours consommer pour éviter la dérive
    if (now - last_enc_time >= ENC_DEBOUNCE_MS) {
      enc_pending    = (diff > 0) ? 1 : -1;
      enc_pending_ms = now;
      last_enc_time  = now;
    }
  }

  // Bouton SELECT — si clic détecté, annuler la rotation en attente (artefact mécanique)
  selectButton.update();
  bool btn_fell = selectButton.fell();
  if (btn_fell) enc_pending = 0;
  s.btn_held = (selectButton.read() == LOW);   // état continu (appui maintenu)

  // Appliquer la rotation différée si le délai est écoulé sans clic
  if (enc_pending != 0 && (now - enc_pending_ms) >= ENC_APPLY_MS) {
    s.enc_down = (enc_pending > 0);
    s.enc_up   = (enc_pending < 0);
    enc_pending = 0;
  }

  // Bouton BACK — deux signaux distincts, tous deux indépendants du minuteur
  // ci-dessous (même raison que pour BTN_HELD : un appui maintenu ne doit pas
  // rester "vrai" en continu pour les écrans qui ne veulent qu'un front).
  //   btn_back      : front (une fois par appui) — "remonter d'un niveau"
  //                   pour la quasi-totalité des écrans. Sans ça, un appui
  //                   tenu ~150-300ms fait remonter plusieurs niveaux d'un
  //                   coup (ui_tick tourne plusieurs fois pendant l'appui).
  //   btn_back_held : état continu — gestes chordés de l'écran TRANSPORT
  //                   (BACK tenu + encodeur).
  backButton.update();
  s.btn_back      = backButton.fell();
  s.btn_back_held = (backButton.read() == LOW);

  if ((now - last_debounce_time) >= DEBOUNCE_DELAY_MS) {
    if (btn_fell) s.btn_valid = true;
    if (s.btn_valid) {
      last_debounce_time = now;
    }
  }
  return s;
}

// -----------------------------------------------------------------
// MAIN UI TICK — call every ~50 ms from loop()
// -----------------------------------------------------------------
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

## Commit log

2026-06-05 erreur dans le n° de version
2026-06-14 Sync display et online hex update
    - ajout de l'affichage du BPM reçu depuis le monitor
    - ajout dans le site web de la possibilité de choisir un .hex en ligne ou local
2026-06-16 sync smartmirror + weblink bug
    [firmware.ino]
2026-07-11 boitier et script ableton
    -Ajout des fichiers 3D pour le boitier
    -Ajout de script pour plugin ableton (en cours)
    - Désactivation autorecord
    [MIDISHIELD.step, boitier.scad, boitier.stl]
2026-07-12 ajout master sync
    - ajout d'un master sync + transport
    - ajout de la période de refresh pour le bpm monitor
    - ajout d'un fichier 3D pour un socle
    [CAHIER_DE_TESTS.xlsx, socle.scad, socle.stl]
2026-07-13 ajout transformateurs
    ajout des premiers transformateurs
    [socle.scad, socle.stl]
2026-07-21 bugfix & minor things
    - correction de pbs de boutons dans les flux
    - ajout des fichiers spécifiques pour flashage
    - désactivation de l'enregistrement en continu (work in progress)
    [controls.h, firmware.ino, routing_submenu.h]
2026-07-25 ajout des générateurs
    ajout des générateurs:
    -LFO
    - euclidien
2026-07-25 v0.5.0
    ajout des loops de batteris dans les générateurs
2026-09-12 buxfix presets
    correction regression sur les presets en 0.5.0
    [firmware.ino]
2026-09-12 diable autorecord
    autorecord désactivé pour la V1 (en attente pour une potentielle future version)
